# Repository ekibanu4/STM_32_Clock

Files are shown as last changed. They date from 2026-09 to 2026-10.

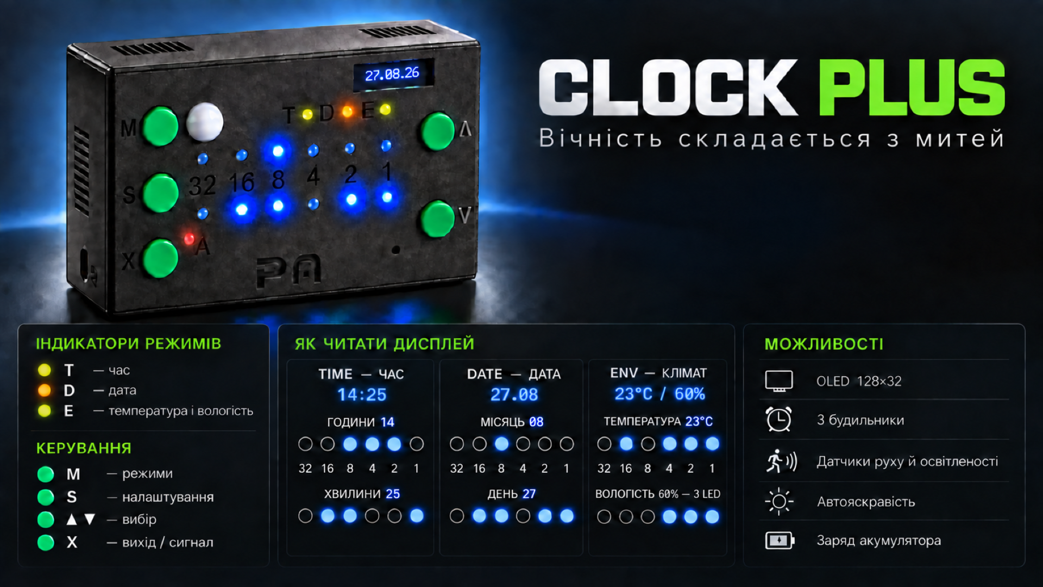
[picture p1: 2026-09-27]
docs/clock-plus-stand-poster-16x9.png

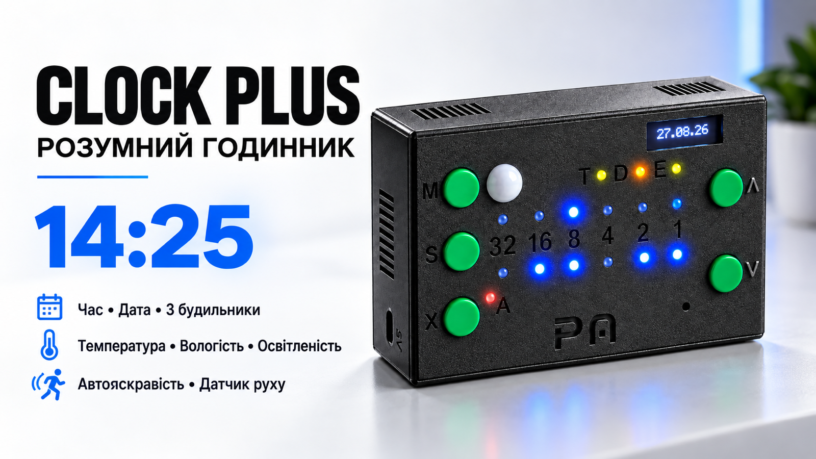
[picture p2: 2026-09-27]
docs/clock-plus-promo-16x9.png

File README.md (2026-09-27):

# STM32 Binary Clock Lab

This repository is a development sandbox for a binary clock built around
different STM32 microcontrollers and peripheral combinations. It contains the
current clock firmware, earlier hardware ports, reusable device drivers, board
experiments, KiCad sources, and end-user documentation.

The project is intentionally broader than a single finished product: it is used
to test display concepts, sensors, RTC implementations, power management, alarm
behavior, and small-memory firmware optimizations on real hardware.

## MCU variants

- **STM32L010F4P6** - current primary target and the most complete low-power build.
- **STM32F030F4P6** - compact CubeMX/HAL port used during early hardware tests.
- **STM32F407G-DISC1** - original prototype and development platform.

The default CMake configuration currently builds the STM32L010F4P6 firmware.
Board-specific notes and wiring are kept under [`Core/Src/boards`](Core/Src/boards).

## Hardware and drivers

The repository includes implementations or experiments for:

- a 16-LED binary display driven by chained 74HC595 shift registers;
- a 128x32 OLED display;
- an internal STM32 RTC clocked from a 32.768 kHz LSE crystal;
- the external DS1302 RTC used by earlier board versions;
- AHT10 and DHT11 temperature/humidity sensors;
- BH1750 and analog LDR light sensing with automatic display brightness;
- an ADC resistor ladder for five control buttons;
- active-buzzer alarm output and three persistent alarm slots;
- PIR motion detection, idle display shutdown, battery measurement, and standby
  power handling.

Separate branches also preserve display and peripheral experiments such as the
MAX721x 8x8 LED matrix version.

## Firmware layout

- `Core/Src/app` - clock behavior, alarms, display rendering, environment data,
  automatic modes, and user-interface state.
- `Core/Src/boards` - MCU/board-specific GPIO and peripheral implementations.
- `Core/Src/drivers` - reusable drivers for buttons, buzzer, DHT11, DS1302,
  light sensing, and shift registers.
- `Drivers` - STM32 CMSIS and HAL sources.
- `docs` - user guide, technical reference, diagrams, and promotional assets.
- `Clocl i2C l0 16 -2 595` - KiCad schematic and PCB sources for the current
  STM32L010-based hardware.

## Build

The current target requires CMake, Ninja, and the GNU Arm Embedded toolchain.

```bash
cmake --preset Release
cmake --build --preset Release
```

Debug and Release presets place their output under `build/`.

## Documentation

- [User manual](docs/clock-plus-user-manual.md)
- [Technical reference](docs/clock-plus-technical-reference.md)
- [STM32L010 board notes](Core/Src/boards/l010f4p6/README.md)
- [STM32F030 board notes](Core/Src/boards/f030f4p6/README.md)
- [STM32F407 board notes](Core/Src/boards/f407_disc1/README.md)

This is an experimental hardware/firmware repository. Verify the selected board
configuration, supply voltage, pin mapping, and programming setup before using
it on assembled hardware.

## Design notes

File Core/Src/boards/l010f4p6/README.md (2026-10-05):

# STM32L010F4P6 Clock Board

This board package contains the STM32L010F4P6 port of the binary clock.
The CubeMX project is `l010f4p6.ioc`.

## MCU Pinout

| MCU pin | Function | Notes |
| --- | --- | --- |
| PA0 | WKUP1 | Main-power wake input, `SYS_WKUP1` in CubeMX |
| PA1 | Buttons ADC | Five-button resistor ladder, `ADC_IN1` |
| PA2 | 74HC595 SER / DS | Shift-register serial data, pin 14 |
| PA3 | 74HC595 RCLK / ST_CP | Shift-register latch clock, pin 12 |
| PA4 | 74HC595 SRCLK / SH_CP | Shift-register shift clock, pin 11 |
| PA5 | 74HC595 OE / TIM2_CH1 | Active-low output enable PWM, pin 13 |
| PA6 | Buzzer drive | Active buzzer transistor control |
| PA7 | Motion sensor input | High means motion detected, low means idle; no internal pull |
| PA9 | I2C SCL | Software I2C clock for OLED, AHT10, and BH1750 |
| PA10 | I2C SDA | Software I2C data for OLED, AHT10, and BH1750 |
| PB1 | Battery sense ADC | BAT+ divider input, `ADC_IN9` |
| PC14 | LSE OSC32_IN | 32.768 kHz crystal |
| PC15 | LSE OSC32_OUT | 32.768 kHz crystal |
| PA13 | SWDIO | Debug/programming |
| PA14 | SWCLK | Debug/programming |

## 74HC595 Display

The current display module uses two chained 74HC595 shift registers:

| MCU pin | Display signal | 74HC595 pin |
| --- | --- | --- |
| PA2 | SER / DS | 14 |
| PA3 | RCLK / ST_CP | 12 |
| PA4 | SRCLK / SH_CP | 11 |
| PA5 | OE / TIM2_CH1 PWM | 13 |

OE is active-low. Firmware controls the display brightness automatically from
the BH1750 light sensor on the shared I2C bus.

### 74HC595 LED Map

The first register carries the six upper value LEDs plus the two high minute
bits. The second register carries the four low minute bits and mode/status
indicators.

| Firmware bit | Normal display meaning |
| --- | --- |
| `board1 bit0..bit5` | upper row value bits `32,16,8,4,2,1` |
| `board1 bit6..bit7` | lower row value bits `32,16` |
| `board2 bit0..bit3` | lower row value bits `8,4,2,1` |
| `board2 bit4` | time mode indicator |
| `board2 bit5` | date mode indicator |
| `board2 bit6` | environment mode indicator |
| `board2 bit7` | alarm indicator |

In time mode the upper row shows hours and the lower row shows minutes. In date
mode the upper row shows month and the lower row shows day. In environment mode
the upper row shows temperature as binary, while humidity is shown as a scale on
the lower row.

## Buttons ADC Ladder

The five buttons are read through one resistor ladder on `PA1 / ADC_IN1`.
The ADC node is pulled up to `3.3V` through `10k`; each button connects the
same `PA1` node to `GND` through its own resistor:

```text
3.3V -- 10k -- PA1 / ADC_IN1
                 |
                 +-- MODE -- 1k   -- GND
                 +-- SET  -- 2k   -- GND
                 +-- UP   -- 4.7k -- GND
                 +-- DOWN -- 10k  -- GND
                 +-- OFF  -- 20k  -- GND
```

With no button pressed, `PA1` stays near `3.3V` and the ADC value is treated as
no button. Pressing a button pulls `PA1` lower; smaller resistor means lower ADC
value.

Current thresholds:

| Button | Max ADC value |
| --- | ---: |
| MODE | 470 |
| SET | 950 |
| UP | 1630 |
| DOWN | 2330 |
| OFF | 3360 |

Values above `3360` are treated as no button.

## User Controls

Manual `MODE` presses cycle through:

```text
time -> date -> environment -> alarm -> battery -> time
```

Automatic display cycling only runs through:

```text
time -> date -> environment -> time
```

Current automatic durations are:

| Auto mode | Duration |
| --- | ---: |
| Time | 15 s |
| Date | 5 s |
| Environment | 5 s |

Button behavior by mode:

| Button | Time | Date | Environment | Alarm | Battery |
| --- | --- | --- | --- | --- | --- |
| MODE | next mode | next mode | next mode | next mode | next mode |
| SET | edit minutes/hours | edit day/month/year | no action | edit alarm hours/minutes | no action |
| UP | increment edited value | increment edited value | no action | when not editing: previous slot; when editing: increment value | no action |
| DOWN | decrement edited value | decrement edited value | no action | when not editing: next slot; when editing: decrement value | no action |
| OFF | exit editing | exit editing | no action | toggle/exit alarm editing | no action |

After user activity, automatic cycling is paused for 30 seconds on the current
screen. If a button is held, the 30-second pause starts after the button is
released. When this pause expires, firmware advances to the next automatic
display mode.

### Time And Date Editing

Setup modes exit automatically after 60 seconds without button activity, the
same as pressing `OFF`.

In time setup, `SET` cycles `minutes -> hours -> minutes`. On the 74HC595
display only the time mode LED blinks; the edited row stays steadily lit.
Editing minutes lights only the lower row, editing hours lights only the upper
row.

In date setup, `SET` cycles `day -> month -> year -> day`. On the 74HC595
display only the date mode LED blinks. Editing day lights only the lower row,
editing month lights only the upper row, and editing year lights `20` on the
upper row plus the editable `00..99` year on the lower row.

## I2C OLED / AHT10 / BH1750 Bus

The experimental I2C branch uses a software I2C bus:

| MCU pin | I2C signal |
| --- | --- |
| PA9 | SCL / SCK |
| PA10 | SDA |

The 0.91" 128x32 OLED is probed at `0x3C`, then `0x3D`. The AHT10
temperature/humidity sensor uses address `0x38`. The BH1750 light sensor uses
address `0x23`. All devices share the same two lines. Both lines are configured
as open-drain GPIO with pull-ups enabled in firmware; external pull-ups are
still recommended for a stable bus.

Before initializing AHT10, firmware recovers the bus with nine SCL pulses and
STOP, waits 40 ms, sends soft reset `0xBA`, and waits 20 ms. It then initializes
the sensor with `0xE1 0x08 0x00` and waits another 40 ms. A measurement starts
with `0xAC 0x33 0x00`; its 80 ms wait starts after the command finishes, so
initialization cannot shorten conversion time. Firmware reads 6 bytes and
converts the 20-bit humidity and temperature values. A busy response keeps the
measurement pending for another scheduler attempt, up to 200 ms from the
trigger; timeout marks the reading invalid and resets initialization state.
Successful measurements are throttled to no faster than once every 15 seconds.

In environment display mode, the top/six-hour LEDs show temperature as a binary
number. The lower humidity LEDs are a scale, not a binary value:

| Humidity | Lit humidity LEDs |
| --- | ---: |
| `< 30%` | 0 |
| `40%` | 1 |
| `50%` | 2 |
| `60%` | 3 |
| `70%` | 4 |
| `80%` | 5 |
| `>= 90%` | 6 |

For example, top `011011` means `27 C`; three lit humidity LEDs means about
`60% RH`.

## BH1750 Light Sensor

The light sensor is now a BH1750 on the shared software I2C bus. Firmware puts
it into continuous high-resolution mode and reads lux about once every 5 seconds,
then maps that value to 10 brightness levels with hysteresis. Brightness is
applied through `PA5 / TIM2_CH1` to the 74HC595 OE pin.

Current brightness calibration:

| Setting | Value |
| --- | ---: |
| Lux dark | 2 |
| Lux bright | 400 |
| Brightness min | 2% |
| Brightness max | 50% |
| Brightness levels | 10 |
| Lux hysteresis | 5 |

## OLED Display

The OLED mirrors the selected mode with text output:

| Mode | OLED content |
| --- | --- |
| Time | `HH:MM:SS`; a small `A` in the lower-right corner means at least one alarm is enabled |
| Date | `DD.MM.YY` |
| Environment | temperature and humidity from AHT10 |
| Alarm list | three rows, `*` marks the selected slot, `-` marks non-selected slots |
| Alarm edit | only the selected slot is shown large, with `..` over hours or minutes |
| Battery | `BAT xx.x%` plus a bottom charge bar |

Time/date setup on OLED uses two dots above the edited field. Alarm setup uses
two dots above the edited hour or minute field. When an alarm is ringing, OLED is
written once with `ALARM n` and normal redraw is skipped until the alarm stops.

## Active Buzzer

`PA6` drives the active buzzer circuit through a transistor. The firmware drives
`PA6` high while the buzzer should sound and low when it should be silent.

## Motion Sensor Idle Display

`PA7` is used as a digital motion sensor input. The sensor output should be
`0..3.3V`; high means motion is present. After one complete automatic display
cycle without motion, button activity, active setup, or an active alarm, firmware
clears the displays and turns the buzzer off. The firmware waits for the
actual automatic transitions `time -> date -> environment -> time`, so each
automatic screen is shown before idle display shutdown. With the current
`15s/5s/5s` auto-mode timing this is about 25 seconds. It does not enter standby
in this idle-display state.

The idle cycle is reset by:

- high level on `PA7`;
- any button press;
- active time/date/alarm editing;
- currently ringing alarm.

Between application updates the CPU enters ordinary Sleep (`WFI`, not STOP).
The active update interval remains 20 ms. In idle-display state it increases to
100 ms, and the core clock is reduced from MSI range 6 (`4.194304 MHz`) to MSI
range 5 (`2.097152 MHz`) while the displays are off.
When motion, a button press, or an alarm requires the UI again, firmware returns
the MSI clock to `4.194304 MHz`, restores the 20 ms interval, shows time mode,
and resumes the normal display cycle. Low-battery handling also uses 20 ms so
the existing buzzer pattern keeps its timing.

LPTIM1 is reserved for a one-shot wake interrupt, clocked from the RTC's
32.768 kHz LSE crystal. Sleep lasts only for the remaining part of the update
interval; if processing already consumed the interval, the next update runs
immediately. SysTick runs at 1 ms while code executes, but its counter and IRQ
are stopped during Sleep. On wake, the elapsed LPTIM1 count advances the HAL
millisecond counter, with fractional milliseconds retained across sleeps and
MSI changes. A pending SysTick is accounted for before sleeping. Interrupts
are masked across WFI: an enabled pending timer IRQ prevents sleep or wakes
the core even with its handler masked (PM0223, wakeup from WFI). This also
handles an IRQ that is already pending before WFI, without depending on the
WFE event latch or SEVONPEND. LPTIM1 is reset after reading its
elapsed count, avoiding flag clearing outside its ISR (ES0483). SysTick keeps
counting while the ARR write synchronizes to LSE. If LSE is not ready, the
firmware falls back to Sleep with the normal 1 ms SysTick wake source; timer
configuration also has a bounded synchronization wait.

PA7 and the ADC button ladder are still polled, without EXTI. Idle detection
latency is approximately up to 100 ms plus processing time, and button presses
shorter than the polling interval can be missed. RTC calendar updates remain
at 1 s. This path does not turn off ADC, TIM2 PWM, or sensor power.

When main power is missing, the normal standby path runs first and the motion
sensor is ignored so it cannot block power-loss handling.

## Alarms

The firmware supports three alarm slots. Alarm settings are stored in RTC backup
registers, so configured slots survive main-power loss while the RTC domain is
kept alive by the supercapacitor.

Alarm mode behavior:

- `MODE` selects the alarm screen.
- entering alarm mode selects slot `A1`.
- `DOWN` selects the next slot: `A1 -> A2 -> A3 -> A1`.
- `UP` selects the previous slot: `A1 -> A3 -> A2 -> A1`.
- `SET` enters alarm hour/minute editing.
- `UP` / `DOWN` while editing increment/decrement the edited alarm value.
- `OFF` while editing exits to alarm-slot selection.
- `OFF` while not editing toggles the selected configured slot on/off.
- `OFF` on an empty slot blinks all hour/minute LEDs as an error.
- long `OFF` toggles all configured alarms: if any alarm is on it disables all;
  if all are off it enables all configured slots.

74HC595 alarm-mode display:

| LED group | Meaning |
| --- | --- |
| upper/lower value rows | selected alarm time |
| alarm LED, `board2 bit7` | alarm mode indicator; also lit in other modes if any alarm is enabled |
| status LED, `board2 bit4` | lit when selected slot is enabled |
| slot number LEDs, `board2 bit6/bit5` visually | selected slot as binary `01`, `10`, `11` |

While editing an alarm, the alarm LED stays steadily lit, the selected slot
number LEDs blink, and only the edited value row is lit: upper row for hours,
lower row for minutes.

OLED alarm-list display uses:

```text
*A1 17:20 ON
-A2 12:20 OFF
-A3 --:-- OFF
```

An empty slot is shown as `--:--`.

When an alarm is saved or re-enabled, firmware clears the "already triggered for
this minute" guard. This means a slot can ring again after being reconfigured,
even if that same slot already fired earlier today.

## RTC / LSE

Time is read from the internal RTC clocked by an external 32.768 kHz crystal on
`PC14/PC15`. Firmware refreshes the cached RTC value once per second.

Date setup cycles through day, month, and year. The year is stored in the STM32
RTC as `00..99` with an implied `20xx` century. While editing the year, the
hour LEDs show the fixed `20` prefix and the minute LEDs show the editable
`00..99` year value; only the date mode indicator blinks. Leap-year day limits
are calculated for the `2000..2099` range.

RTC init keeps the LSE path conservative:

- if `LSERDY` is already set after standby wake, firmware does not re-run
  `HAL_RCC_OscConfig()` for LSE;
- if LSE/RTC init returns an error, firmware returns from RTC init instead of
  staying forever in `Error_Handler()`.

## Wake Power, Battery Sense, And Standby

`PA0 / WKUP1` is the hard power-loss and wake signal. If `PA0` is low, the
firmware powers external devices down, prepares `WKUP1`, and enters standby.

Battery level is measured separately on `PB1 / ADC_IN9`. The firmware converts
the ADC reading through `VREFINT`, then scales it through the measured battery
divider calibration. `PA0` and `PB1` intentionally have separate jobs:

- `PA0 / WKUP1` decides hard standby and wake after real power loss;
- `PB1 / ADC_IN9` decides low-battery display shutdown and battery percentage.

Divider scaling follows the fitted 470 kOhm upper and 1 MOhm lower resistors:

```text
BAT+ -- 470 kOhm -- PB1 / ADC_IN9 -- 1 MOhm -- GND
battery_mV = sense_mV * 1470 / 1000
```

At 3390 mV on BAT+, an unloaded PB1 should be about 2306 mV. The previous
3650/2140 scaling overestimated battery voltage by about 16%. A voltage meter
loads this high-impedance divider: a 1 MOhm input in parallel with the lower
resistor reduces PB1 to about 1747 mV and can trigger low-battery mode. Compare
firmware voltage against BAT+ with the PB1 probe removed; use the raw ADC and
VREFINT readings to inspect PB1 without changing the divider load.
On the tested board at 4200 mV input, ADC diagnostics measured 2184 mV with the
meter connected and 2870 mV after removing the PB1 probe.
After correcting the scaling, firmware read 4215 mV at the supply's 4200 mV
setting. At a multimeter-measured 3380 mV on BAT+, it read about 3338 mV; the
remaining error is about 42 mV (1.2%), so this is nominal divider scaling rather
than a precision calibration of the full measurement path.

Current low-battery thresholds:

```text
MAIN_POWER_BATTERY_MV_MIN = 2900 mV battery voltage
MAIN_POWER_BATTERY_MV_RECOVER = 3100 mV battery voltage
```

Battery voltage is measured once every 500 ms and cached for both the
low-battery check and the percentage display. ADC sampling time is 160.5 clock
cycles for button, battery, and VREFINT channels; the first conversion after
selecting a channel is discarded as before.

When the scaled battery voltage is below `2900 mV` for three consecutive fresh measurements
while `PA0` is still high, firmware enters low-battery mode instead of standby:
external devices are powered down and only the alarm LED blinks periodically.
Normal display operation resumes only after three consecutive fresh measurements
at or above `3100 mV`. Repeated cache reads do not count as confirmation; a
persistent threshold crossing takes approximately 1–1.5 s to confirm.

Before standby the firmware powers external devices down, then waits up to
`25 s` for `PA0 / WKUP1` to be low and debounces that low level for `300 ms`.

The battery display percentage uses a lookup curve from the same calibrated
battery voltage:

```text
2900 mV = 0%
3100 mV = 10%
3200 mV = 22%
3300 mV = 36%
3400 mV = 50%
3500 mV = 62%
3600 mV = 73%
3700 mV = 82%
3800 mV = 90%
4100 mV = 100%
```

Values between points are interpolated. The displayed percentage is filtered and
updated with hysteresis so it does not jump on every ADC sample.

The manual battery mode is reached through:

```text
time -> date -> environment -> alarm -> battery -> time
```

In battery mode the 74HC595 display uses only the six minute LEDs as a charge
bar. The OLED shows `BAT xx.x%` plus a bottom charge bar.

Expected power-loss flow:

```text
main power present  -> PA0 high, firmware runs
main power removed  -> PA0 low, VDD MCU held by supercapacitor
firmware enters standby
main power returns  -> PA0 rising edge wakes the MCU
```

`PA0` is not used as ADC or normal GPIO output. CubeMX assigns it as
`SYS_WKUP1`; firmware only enables the PWR wake source before entering standby.

## Size-Oriented Firmware Notes

The l010 build avoids several HAL driver paths to keep the firmware inside the
16 KB flash limit:

- ADC reads for the button ladder, battery sense, and `VREFINT` use direct ADC1
  registers instead of `HAL_ADC_Init`, `HAL_ADC_ConfigChannel`, and
  `HAL_ADC_PollForConversion`;
- `stm32l0xx_hal_adc.c`, `stm32l0xx_hal_adc_ex.c`, `stm32l0xx_hal_i2c.c`,
  `stm32l0xx_hal_i2c_ex.c`, and `stm32l0xx_hal_dma.c` are not linked by the
  CMake build;
- system clock setup and `HAL_InitTick` are kept small and register-based;
- the OLED/AHT10/BH1750 bus remains software I2C on GPIO, so no hardware I2C
  handle or HAL I2C transfer code is used.

The main loop uses ordinary Sleep between updates (20 ms active, 100 ms idle)
with LPTIM1 wakeup and HAL time compensation. This preserves peripheral state
and avoids 1 ms SysTick wakeups while asleep. STOP is not used; PA7 motion,
button input, low-battery handling, and software alarm checks run on each update.

## Flashing Notes

OpenOCD may fail to halt the target when the chip is in a low-power state. In
that case, use STM32CubeProgrammer CLI with connect-under-reset, for example:

```text
STM32_Programmer_CLI -c port=SWD mode=UR freq=50 -w build/Debug/l010f4p6.elf -v -rst
```

The VS Code tasks still include OpenOCD flash tasks for normal cases.

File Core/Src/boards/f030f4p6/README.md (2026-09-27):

# STM32F030F4P6 Binary Clock Board

This board package documents the STM32F030F4P6 wiring used by the CubeMX/HAL
port of the binary clock.

## MCU Pinout

| MCU pin | Function | Notes |
| --- | --- | --- |
| PA0 | LDR ADC input | Light sensor / automatic brightness, ADC_IN0 |
| PA1 | Buttons ADC input | Five-button resistor ladder, ADC_IN1 |
| PA2 | 74HC595 SER / DS | Shift-register serial data, pin 14 |
| PA3 | 74HC595 RCLK / ST_CP | Shift-register latch clock, pin 12 |
| PA5 | 74HC595 SRCLK / SH_CP | Shift-register shift clock, pin 11 |
| PA6 | 74HC595 OE | TIM3_CH1 PWM, active-low output enable, pin 13 |
| PA7 | DS1302 CLK | RTC clock |
| PA9 | DS1302 DATA / I/O | Bidirectional RTC data |
| PA10 | DS1302 RST / CE | RTC chip enable |
| PB1 | Buzzer control | Active buzzer transistor drive |
| PF1 | DHT11 DATA | Single-wire temperature/humidity data |
| PA13 | SWDIO | Debug/programming |
| PA14 | SWCLK | Debug/programming |

## 74HC595N Chain

Two 74HC595N shift registers are chained for 16 LED outputs.

STM32F030F4P6 to first 74HC595N:

| STM32 pin | 74HC595N pin | Function |
| --- | --- | --- |
| PA2 | pin 14 | SER / DS, serial data |
| PA3 | pin 12 | RCLK / ST_CP, latch clock |
| PA5 | pin 11 | SRCLK / SH_CP, shift clock |
| PA6 | pin 13 | OE, output enable PWM |

The first byte shifted out travels through the first 74HC595 `QH'` output and
ends up in the second chip. The second byte shifted out remains in the first
chip connected directly to MCU DATA.

### LED Mapping

First 74HC595, connected directly to MCU DATA:

| Output | Display |
| --- | --- |
| QA | hours 32 |
| QB | hours 16 |
| QC | hours 8 |
| QD | hours 4 |
| QE | hours 2 |
| QF | hours 1 |
| QG | minutes 32 |
| QH | minutes 16 |

Second 74HC595, chained from first chip `QH'`:

| Output | Display |
| --- | --- |
| QA | minutes 8 |
| QB | minutes 4 |
| QC | minutes 2 |
| QD | minutes 1 |
| QE | mode time / alarm slot 1 |
| QF | mode date / alarm slot 2 |
| QG | mode environment / alarm slot 3 |
| QH | alarm status |

## Buttons ADC Ladder

The five buttons are read through one resistor ladder on `PA1 / ADC_IN1`.

Current measured ADC ranges are decoded with these thresholds:

| Button | Max ADC value |
| --- | ---: |
| MODE | 470 |
| SET | 950 |
| UP | 1630 |
| DOWN | 2330 |
| OFF | 3360 |

Values above `3360` are treated as no button.

## Light Sensor

The LDR divider is connected to `PA0 / ADC_IN0`.

Current calibration:

| Constant | Value |
| --- | ---: |
| ADC dark | 1000 |
| ADC bright | 3200 |
| Brightness min | 5% |
| Brightness max | 70% |
| Brightness levels | 6 |
| ADC hysteresis | 80 |

Brightness is applied through `PA6 / TIM3_CH1` to the 74HC595 OE pin. OE is
active-low.

## DS1302 RTC

| STM32 pin | DS1302 pin |
| --- | --- |
| PA7 | CLK |
| PA9 | DATA / I/O |
| PA10 | RST / CE |

The DS1302 stores the current time/date and the three alarm slots in
battery-backed RAM.

Alarm RAM format:

```text
byte 0  -> signature
byte 1  -> version
byte 2  -> alarm slot 1 flags
byte 3  -> alarm slot 1 hour
byte 4  -> alarm slot 1 minute
byte 5  -> alarm slot 2 flags
byte 6  -> alarm slot 2 hour
byte 7  -> alarm slot 2 minute
byte 8  -> alarm slot 3 flags
byte 9  -> alarm slot 3 hour
byte 10 -> alarm slot 3 minute
byte 11 -> checksum
```

Alarm flags:

```text
bit 0 -> configured
bit 1 -> enabled
```

## DHT11

The DHT11 data line is connected to `PF1`.

The firmware switches PF1 between open-drain output for the start pulse and
input for the DHT11 response and 40-bit data transfer. The DHT11 transaction is
guarded so a full read is not started more often than once every 2 seconds.

## Buzzer

`PB1` drives the active buzzer circuit. The alarm pattern is generated by the
application layer:

```text
beep beep beep ... pause ... beep beep beep ... pause
```

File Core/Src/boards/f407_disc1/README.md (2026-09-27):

# STM32F407G-DISC1 Board Package

This board package contains the current prototype wiring for the binary clock on
STM32F407G-DISC1.

## MCU Pinout

| MCU pin | Function | Notes |
| --- | --- | --- |
| PA0 | Light sensor ADC | LDR divider input |
| PA1 | Buttons ADC | Five-button resistor ladder |
| PA2 | 74HC595 SER / DS | Shift-register serial data, pin 14 |
| PA3 | 74HC595 RCLK / ST_CP | Shift-register latch, pin 12 |
| PA4 | 74HC595 SRCLK / SH_CP | Shift-register clock, pin 11 |
| PA5 | DS1302 CLK | RTC clock |
| PA6 | 74HC595 OE / TIM3_CH1 | Output-enable PWM dimming, pin 13 |
| PA7 | DS1302 DATA / I/O | RTC bidirectional data |
| PA8 | DS1302 RST / CE | RTC chip enable |
| PA10 | DHT11 DATA / S | HW-481 DHT11 module data |
| PA15 | Buzzer drive | NPN base through 1k..4.7k |

PA13 and PA14 are kept free for SWD debugging.

## Buttons ADC Ladder

```text
3.3V
 |
[10k]
 |
 +-------> PA1 / ADC_BUTTONS
 |
 +--[ MODE]--[1k]--GND
 |
 +--[ SET ]--[2k]--GND
 |
 +--[ UP  ]--[4.7k]--GND
 |
 +--[ DOWN]--[10k]--GND
 |
 +--[ OFF ]--[20k]--GND
```

ADC thresholds live in `board_config.h`.

## Light Sensor

```text
3.3V
 |
[LDR]
 |
 +-------> PA0 / ADC_LIGHT
 |
[10k]
 |
GND
```

The light sensor controls display brightness from 5% to 70%. The 74HC595 outputs
are dimmed together through the OE pin.

## 74HC595 Chain

First 74HC595N wiring:

| 74HC595 pin | Signal | MCU / rail |
| --- | --- | --- |
| 14 DS / SER | Serial data | PA2 |
| 11 SH_CP / SRCLK | Shift clock | PA4 |
| 12 ST_CP / RCLK | Latch clock | PA3 |
| 13 OE | Output enable PWM | PA6 |
| 10 MR / SRCLR | Master reset | 3.3V |
| 16 VCC | Power | 3.3V |
| 8 GND | Ground | GND |

Second 74HC595N is chained from the first register QH' to the second register DS.

### Display Mapping

Board 1 outputs:

| Output | Display |
| --- | --- |
| QA | hours 32 |
| QB | hours 16 |
| QC | hours 8 |
| QD | hours 4 |
| QE | hours 2 |
| QF | hours 1 |
| QG | minutes 32 |
| QH | minutes 16 |

Board 2 outputs:

| Output | Display |
| --- | --- |
| QA | minutes 8 |
| QB | minutes 4 |
| QC | minutes 2 |
| QD | minutes 1 |
| QE | mode time |
| QF | mode date |
| QG | mode environment |
| QH | alarm set |

## DS1302Z RTC

| DS1302 pin | MCU / rail |
| --- | --- |
| CLK | PA5 |
| DATA / I/O | PA7 |
| RST / CE | PA8 |
| VCC | 3.3V |
| GND | GND |

The module has quartz and backup battery assembled. DS1302 RAM stores alarm
slots.

## HW-481 / DHT11

| Module pin | MCU / rail |
| --- | --- |
| DATA / S | PA10 |
| VCC / + | 5V on the current prototype |
| GND / - | GND |

The DHT11 module was unreliable at the lower prototype voltage, so the current
test wiring uses 5V module power while the data line goes to PA10.

## Active Buzzer

Current prototype buzzer: TMB12A05 active buzzer.

```text
PA15 -> NPN base through 1k..4.7k
3.3V -> 270R -> buzzer +
buzzer - -> NPN collector
NPN emitter -> GND
```

The 270R resistor was chosen experimentally to reduce volume.

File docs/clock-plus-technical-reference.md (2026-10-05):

# Clock Plus на STM32L010F4P6

## Технічна документація апаратної частини та firmware

**Статус документа:** первинна технічна редакція
**Дата звірки:** 2026-09-27
**Гілка:** `optimizations`
**Звірений коміт:** `ea0914f` (`Optimize l010 firmware size and idle mode`)
**Цільова плата:** STM32L010F4P6, TSSOP-20
**Проєкт CubeMX:** `l010f4p6.ioc`

Цей документ описує поточну реалізацію Clock Plus: електричну схему,
розведення контактів, периферію, формати даних, алгоритми firmware, режими
живлення, збірку, прошивання та відомі розбіжності між кодом і KiCad.

> Важливо: джерелом істини для поведінки пристрою є поточний код. KiCad-схема
> містить щонайменше одну критичну розбіжність із firmware у підключенні
> 74HC595. Перед виготовленням наступної ревізії плати її треба усунути.

## 1. Джерела даних

Документ складено за такими файлами:

- `Core/Src/main.c` - запуск, системна частота, RTC, головний цикл і стани
  живлення;
- `Core/Src/board.h` - апаратний API та формат 16-бітного LED-дисплея;
- `Core/Src/boards/l010f4p6/board.c` - GPIO, ADC, 74HC595, програмний I2C,
  AHT10, BH1750, батарея, buzzer і STANDBY;
- `Core/Src/boards/l010f4p6/board_config.h` - апаратні контакти, пороги й
  калібрування;
- `Core/Src/boards/l010f4p6/oled_128x32.c` - драйвер OLED 128x32;
- `Core/Src/app/*` - UI, автоматична зміна режимів, відображення, датчики й
  будильники;
- `Core/Src/boards/l010f4p6/README.md` - опис плати й інструкції збірки;
- `l010f4p6.ioc` - конфігурація STM32CubeMX;
- `STM32L010XX_FLASH.ld` - карта Flash/RAM;
- `CMakeLists.txt`, `CMakePresets.json`, `.vscode/*` та `openocd.cfg` - збірка,
  debug і прошивання;
- `docs/Clock i2c l0.pdf` - принципова схема KiCad;
- `docs/Clock i2c l0 pcb.pdf` - дев'ятисторінковий комплект шарів PCB;
- `docs/Clocl i2C l0 16 -2 595/Clock i2c l0.kicad_sch` - вихідна схема;
- `docs/Clocl i2C l0 16 -2 595/Clock i2c l0.kicad_pcb` - вихідна PCB.

## 2. Призначення та склад системи

Clock Plus - автономний бінарний годинник із двома засобами індикації:

- 16 світлодіодів через два послідовно з'єднані 74HC595;
- OLED 0.91 дюйма, 128x32, I2C, сумісний із SSD1306.

Функціональні вузли:

- RTC мікроконтролера від зовнішнього LSE 32.768 kHz;
- три незалежні щоденні будильники;
- активний buzzer через NPN-транзистор;
- AHT10 для температури й вологості;
- BH1750 для освітленості та автоматичної яскравості;
- PIR AM312/HC-SR312 для контролю присутності;
- п'ять кнопок через один ADC-резистивний ladder;
- контроль напруги 18650 через ADC;
- Sleep між обробками та повний STANDBY при зникненні основного
  живлення;
- SWD для програмування та налагодження.

## 3. Мікроконтролер і ресурси

| Параметр | Значення |
| --- | --- |
| MCU | STM32L010F4P6 |
| Ядро | Arm Cortex-M0+ |
| Корпус | TSSOP-20 |
| Flash | 16 KiB, адреса `0x08000000` |
| SRAM | 2 KiB, адреса `0x20000000` |
| Активна частота | MSI range 6, 4.194304 MHz |
| Частота очікування | MSI range 5, 2.097152 MHz |
| RTC clock | LSE 32.768 kHz |
| Системний tick | SysTick, 1 ms під час виконання; компенсація часу Sleep через LPTIM1/LSE |
| Період головного циклу | 20 ms активний, 100 ms із погашеними екранами |
| Мова | C11 із GNU extensions |
| HAL/CMSIS | STM32CubeL0 FW 1.12.4 |

### 3.1 Поточне використання пам'яті

Перевірено збірками Debug і Release 2026-09-27. Через однакову оптимізацію
`-Os` і LTO їхній виконуваний образ має однаковий розмір.

| Область | Використано | Доступно | Частка |
| --- | ---: | ---: | ---: |
| Flash | 14,100 B | 16,384 B | 86.06% |
| RAM разом із резервом heap/stack | 1,776 B | 2,048 B | 86.72% |
| `.text` | 13,592 B | - | - |
| `.rodata` | 256 B | - | - |
| `.data` | 52 B | - | - |
| `.bss` | 188 B | - | - |
| `_user_heap_stack` | 1,536 B | - | - |

Налаштування linker script:

- мінімальний heap: `0x200` = 512 B;
- мінімальний stack: `0x400` = 1024 B;
- запас Flash до межі регіону: 2,284 B;
- запас RAM з урахуванням зарезервованих heap/stack: 272 B.

У firmware не використовується динамічна пам'ять, тому резерв heap можна
переглянути окремою оптимізацією після перевірки всіх бібліотечних залежностей.

## 4. Архітектура вихідного коду

```text
Core/Src/main.c
  запуск MCU, clock, ADC base, RTC, main loop, power-state orchestration

Core/Src/board.h
  апаратно-незалежні типи та API плати

Core/Src/boards/l010f4p6/
  board.c              GPIO, ADC, PWM, I2C, датчики, battery, standby
  board_config.h       контакти, пороги, калібрування
  oled_128x32.c/.h     OLED SSD1306-compatible

Core/Src/app/
  alarm/               три alarm slots, trigger, buzzer, RTC backup storage
  display/             формування 16-бітної LED-маски
  environment/         планувальник читання AHT10
  ui/                  кнопки, edit states, auto modes
  core/                спільні типи та константи
```

Апаратна залежність зосереджена в `board.c`. Застосунок працює через функції
`Board_*`, але OLED поки що викликається напряму з `main.c`.

## 5. Карта контактів MCU

### 5.1 Карта, яку використовує поточний firmware

| Контакт MCU | Напрямок/периферія | Функція | Електричні примітки |
| --- | --- | --- | --- |
| PA0 | digital input / WKUP1 | наявність основного живлення, wake зі STANDBY | високий = живлення є; низький = підготовка до STANDBY |
| PA1 | ADC_IN1 | п'ять кнопок через resistor ladder | analog, без внутрішньої підтяжки |
| PA2 | GPIO output | 74HC595 SER/DS | serial data, pin 14 регістра |
| PA3 | GPIO output | 74HC595 RCLK/ST_CP | latch, pin 12 |
| PA4 | GPIO output | 74HC595 SRCLK/SH_CP | shift clock, pin 11 |
| PA5 | TIM2_CH1 AF5 | 74HC595 OE | active-low PWM, pin 13 |
| PA6 | GPIO output | активний buzzer через NPN | high = звук увімкнено |
| PA7 | digital input | PIR motion | high = рух; внутрішньої підтяжки немає |
| PA9 | GPIO open-drain | software I2C SCL | OLED, AHT10, BH1750 |
| PA10 | GPIO open-drain | software I2C SDA | OLED, AHT10, BH1750 |
| PA13 | SWDIO | програмування/debug | роз'єм SWD |
| PA14 | SWCLK | програмування/debug | роз'єм SWD |
| PB1 | ADC_IN9 | BAT+ sense | через резистивний дільник |
| PC14 | OSC32_IN | LSE input | кварц 32.768 kHz |
| PC15 | OSC32_OUT | LSE output | кварц 32.768 kHz |
| NRST | reset input | hardware reset/connect-under-reset | зовнішня підтяжка до VDD MCU |
| PB9/BOOT0 | boot selection | штатно притиснутий до GND | очікується normal boot from Flash |

### 5.2 CubeMX проти runtime-конфігурації

У `l010f4p6.ioc` описані PA0, PA1, PA2-PA5, PB1, PC14/PC15 та SWD. Контакти
PA6, PA7, PA9 і PA10 ініціалізуються вручну в board layer і не повністю
представлені в CubeMX. Після повторної генерації CubeMX необхідно перевіряти:

- збереження всіх блоків `USER CODE`;
- `Board_Init()` для PA6, PA7 і програмного I2C;
- CMake source list;
- ручну ініціалізацію ADC, системної частоти та SysTick.

### 5.3 Критична розбіжність KiCad і firmware

Поточна схема `Clock i2c l0.kicad_sch` підписує сигнали так:

| Контакт | KiCad-схема | Поточний firmware |
| --- | --- | --- |
| PA2 | RCLK/ST_CP | SER/DS |
| PA3 | OE | RCLK/ST_CP |
| PA4 | SER/DS | SRCLK/SH_CP |
| PA5 | SRCLK | OE/TIM2_CH1 |

Це не косметична різниця: PA5 потрібен firmware як TIM2_CH1 для PWM. Перед
замовленням PCB треба або перерозвести KiCad під firmware, або синхронно змінити
`board_config.h`, GPIO і TIM2. Поточна перевірена програмна карта наведена в
розділі 5.1.

## 6. Апаратна схема

### 6.1 PCB

Параметри поточного KiCad PCB:

| Параметр | Значення |
| --- | --- |
| Габарит | 120 x 80 mm |
| Шари міді | 2: F.Cu, B.Cu |
| Матеріал | FR4 |
| Товщина плати | 1.6 mm |
| Мідь | 35 um на кожному боці |
| Кількість footprints | 77 |
| Монтажні отвори | 4 x 3.3 mm |
| Координати отворів від origin KiCad | (22.65, 22.65), (22.65, 97.45), (137.35, 22.65), (137.35, 97.35) mm |

У `docs/Clock i2c l0 pcb.pdf` наведено дев'ять сторінок виробничого перегляду
шарів. Джерело PCB має кілька історичних snapshot-файлів `before-*`; актуальним
вважається файл без суфікса.

### 6.2 Основні компоненти зі схеми

| Позначення | Компонент/номінал | Призначення |
| --- | --- | --- |
| U1 | STM32L010F4Px | MCU |
| U2, U3 | 74HC595, SOIC-16 | 16 LED outputs |
| Y1 | 32.768 kHz crystal | LSE для RTC |
| C7, C8 | 15 pF | load capacitors LSE |
| C1, C2 | 100 nF | локальне decoupling VDD/VDDA |
| C4 | 10 uF | bulk decoupling VDD MCU |
| C3 | polarized, номінал у схемі не заданий | резервне живлення/накопичення |
| R2 | 10 kOhm | NRST pull-up |
| R3 | 220 kOhm | PA0/WKUP pull-down у схемі |
| R5 | 470 kOhm | верхнє плече BAT+ sense |
| R8 | 1 MOhm | нижнє плече BAT+ sense |
| R6, R9 | 4.7 kOhm | pull-up SCL/SDA до VCC peripheral |
| R7 | 10 kOhm | PB9/BOOT0 pull-down до GND |
| R27 | 10 kOhm | pull-up button ladder до VCC peripheral |
| R28-R32 | 1 k, 2 k, 4.7 k, 10 k, 20 kOhm | MODE, SET, UP, DOWN, OFF |
| R10 | 2 kOhm | base resistor buzzer transistor |
| Q1 | 2N2222 | low-side key активного buzzer |
| R11-R26 | 200 Ohm | струмообмеження 16 LED |
| BT1 | 18650 | акумулятор |
| J3 | BMS, 4 pin | BMS connection |
| J4 | buck-boost, 4 pin | перетворювач до 3.3 V |
| J2 | SWD, 5 pin | SWCLK, SWDIO, GND, VDD MCU, NRST |
| J5 | OLED, 4 pin | SDA, SCL/SCK, VCC peripheral, GND |
| J6 | GY-302/BH1750, 4 pin | VCC, GND, SCL, SDA |
| J7 | AHT10, 4 pin | VCC, GND, SCL, SDA |
| J1 | AM312/HC-SR312, 3 pin | PIR output, VCC, GND |
| BZ1 | active buzzer | звуковий сигнал |

На схемі D1-D4 та R1 мають загальні позначення без конкретного part number або
номіналу. Їх треба конкретизувати в BOM перед виробництвом.

### 6.3 Живлення

Схема розділяє щонайменше такі мережі:

- `+3.3V` - основний вихід buck-boost;
- `VCC периферія` - OLED, сенсори, 74HC595, LED, PIR і buzzer;
- `VDD MCU` - VDD та VDDA мікроконтролера;
- `Bms+`, `Bms-` - акумуляторна сторона BMS;
- `GND`.

Між основним живленням, периферією та MCU використано діоди D1-D4, резистор R1
і полярний накопичувальний конденсатор C3. Ідея вузла - не допустити живлення
вимкненої периферії через GPIO/I2C і дати RTC/MCU час коректно перейти в
STANDBY.

Firmware додатково переводить зовнішні лінії в analog/no-pull перед STANDBY,
щоб зменшити leakage і back-powering. Діодна розв'язка не скасовує вимоги, що
сигнал на вході MCU не повинен перевищувати VDD MCU більш ніж допускає
datasheet.

### 6.4 Decoupling і LSE

- C1 і C2: 100 nF біля VDD та VDDA;
- C4: 10 uF на `VDD MCU`;
- LSE: Y1 32.768 kHz між PC14 і PC15;
- C7 і C8: по 15 pF від кожного виводу кварцу до GND;
- доріжки LSE повинні бути короткими, симетричними й віддаленими від LED/PWM;
- точне значення load capacitors слід перевірити за `CL` конкретного кварцу та
  паразитною ємністю PCB. 15 pF - значення поточної схеми, а не універсальне
  правило.

## 7. RTC і календар

RTC тактується від зовнішнього LSE:

| Налаштування | Значення |
| --- | --- |
| LSE | 32.768 kHz |
| Drive | `RCC_LSEDRIVE_HIGH` |
| Формат часу | 24 години |
| Async prescaler | 127 |
| Sync prescaler | 255 |
| RTC output | disabled |

Під час запуску `App_RTC_Init()`:

1. відкриває доступ до backup domain;
2. скидає backup domain, якщо RTC clock source не LSE;
3. запускає LSE через `HAL_RCC_OscConfig()`;
4. перевіряє `LSERDY`;
5. вибирає LSE для RTC та вмикає RTC;
6. викликає `HAL_RTC_Init()`.

Якщо запуск LSE або RTC не вдався, функція повертає 0, але `main()` зараз
ігнорує результат і продовжує запуск. Окремої індикації LSE failure немає.

Поточний час читається раз на 1000 ms. За вимогою STM32 HAL після
`HAL_RTC_GetTime()` одразу викликається `HAL_RTC_GetDate()` для коректного
розблокування shadow registers.

Рік зберігається як `00..99` та інтерпретується UI як 2000-2099. Високосний
рік визначається через `year % 4 == 0`, що коректно для цього діапазону.
`Board_WriteDate()` записує weekday як Monday; weekday у UI не використовується
і не обчислюється з дати.

## 8. 16-LED дисплей і 74HC595

Використано два каскадно з'єднані 74HC595. Firmware передає спочатку `board2`
від MSB до LSB, потім `board1` від MSB до LSB, після чого формує імпульс latch.

### 8.1 Формат `ClockDisplay_t`

| Байт/біт | Значення у звичайних режимах |
| --- | --- |
| `board1 bit0` | верхній ряд, вага 32 |
| `board1 bit1` | верхній ряд, вага 16 |
| `board1 bit2` | верхній ряд, вага 8 |
| `board1 bit3` | верхній ряд, вага 4 |
| `board1 bit4` | верхній ряд, вага 2 |
| `board1 bit5` | верхній ряд, вага 1 |
| `board1 bit6` | нижній ряд, вага 32 |
| `board1 bit7` | нижній ряд, вага 16 |
| `board2 bit0` | нижній ряд, вага 8 |
| `board2 bit1` | нижній ряд, вага 4 |
| `board2 bit2` | нижній ряд, вага 2 |
| `board2 bit3` | нижній ряд, вага 1 |
| `board2 bit4` | T/time; у alarm mode статус selected slot |
| `board2 bit5` | D/date; у alarm mode старший біт номера slot |
| `board2 bit6` | E/environment; у alarm mode молодший біт номера slot |
| `board2 bit7` | alarm indicator |

### 8.2 Значення режимів

- **TIME:** верхній ряд - години у binary, нижній - хвилини;
- **DATE:** верхній ряд - місяць, нижній - день;
- **ENVIRONMENT:** верхній ряд - температура у binary; нижній - шкала
  вологості;
- **ALARM:** два ряди - час вибраного будильника; mode LEDs кодують номер і
  enabled state;
- **BATTERY:** верхній ряд вимкнений, нижній - шкала з 0..6 LED.

Шкала вологості реалізована так:

| RH | Кількість LED |
| ---: | ---: |
| `<=30%` | 0 |
| 40% | 1 |
| 50% | 2 |
| 60% | 3 |
| 70% | 4 |
| 80% | 5 |
| `>=90%` | 6 |

LED шкали заповнюються від молодшої ваги: 1, 2, 4, 8, 16, 32.

### 8.3 PWM яскравості

OE регістрів активний низьким рівнем. TIM2_CH1 налаштований вручну:

| Регістр | Значення |
| --- | --- |
| PSC | 7 |
| ARR | 99 |
| CCR1 | 0..100 |
| PWM mode | mode 1, preload enabled |
| Polarity | inverted через `CC1P` |

При 4.194304 MHz PWM має приблизно 5.24 kHz; у режимі очікування дисплей уже
вимкнений, тому зміна core clock не впливає на видиму яскравість.

BH1750 задає 10 дискретних рівнів у діапазоні 2-50%.

## 9. Програмний I2C

Шина реалізована bit-bang GPIO, без апаратного I2C, DMA та interrupt transfer.

| Параметр | Значення |
| --- | --- |
| SCL | PA9 |
| SDA | PA10 |
| GPIO mode | open-drain output |
| Внутрішні pull-up | увімкнені |
| Зовнішні pull-up у KiCad | 4.7 kOhm на кожній лінії |
| Software delay | 8 коротких loop iterations на edge |
| Clock stretching | не підтримується явно |
| Bus arbitration | не підтримується |

На одній шині працюють:

| Пристрій | 7-bit address |
| --- | ---: |
| OLED | `0x3C`, fallback `0x3D` |
| AHT10 | `0x38` |
| BH1750 | `0x23` |

OLED має власну копію low-level I2C-функцій, а AHT10/BH1750 використовують
реалізацію з `board.c`. Доступ до шини не арбітрується mutex/state machine, але
всі операції виконуються послідовно з одного main loop.

## 10. OLED 128x32

Поточний драйвер орієнтований на SSD1306-compatible 128x32:

| Параметр | Значення |
| --- | --- |
| Розмір | 128 x 32 px |
| Сторінки | 4 сторінки по 8 px |
| Power-on delay | 80 ms |
| Probe retries | 3 |
| Text chunk | 24 bytes/columns |
| Мінімальний redraw interval | 200 ms |

Драйвер:

- пробує адресу `0x3C`, потім `0x3D`;
- виконує bus recovery перед probe;
- має вбудований 5x7 font;
- масштабує текст 2x у два OLED pages;
- кешує останні відображені значення й не перерисовує незмінний екран;
- групує символи в I2C chunks до 24 bytes;
- очищає весь framebuffer OLED при переходах до/з alarm і battery та при
  переході між alarm list/edit;
- під час звичайного оновлення часу/дати пише лише потрібні області.

Поточна відрисовка синхронна. Окремої черги дрібних OLED jobs і функції
`Process()` немає; довгі clear/battery operations блокують main loop на час
I2C-транзакцій.

Формати:

| Mode | OLED output |
| --- | --- |
| TIME | `HH:MM:SS`; `A` у правому нижньому куті, якщо є enabled alarm |
| DATE | `DD.MM.YY` |
| ENVIRONMENT | `Txx Hxx` або `T-- H--` |
| ALARM list | `*A1 HH:MM ON`, `-A2 --:-- OFF` тощо |
| ALARM edit | один slot великим шрифтом, `..` над hours/minutes |
| BATTERY | `BAT xx.x%` та смуга 120 px |
| Active alarm | `ALARM n`, запис один раз до завершення alarm |

## 11. AHT10

| Параметр | Значення |
| --- | --- |
| Address | `0x38` |
| Bus recovery | 9 SCL pulses та STOP перед initialization |
| Soft reset | `BA`, після 40 ms очікування; далі 20 ms до init command |
| Init command | `E1 08 00` |
| Init delay | 40 ms після init command |
| Measure command | `AC 33 00` |
| Conversion wait | 80 ms |
| Busy timeout | 200 ms після завершення measure command |
| Response | 6 bytes |
| Мінімальний interval | 15 s |
| Busy flag | byte 0, bit `0x80` |

Humidity і temperature вилучаються як 20-бітні значення. Результат округлюється
до цілих одиниць:

- humidity обмежується 0..100% RH;
- temperature обмежується 0..99 C;
- від'ємні temperature зараз примусово стають 0 C;
- LED-дисплей додатково обмежує temperature до 60.

Measurement розділена на start і read, тому 80 ms очікування не виконується
через блокувальний `HAL_Delay`. Відлік починається після завершення measure
command, а не до initialization. Busy response залишає measurement pending
для наступної спроби scheduler; після 200 ms дані позначаються invalid і стан
initialization скидається. При помилці запису/читання драйвер також повторно
ініціалізує сенсор із bus recovery та soft reset.

## 12. BH1750

| Параметр | Значення |
| --- | --- |
| Address | `0x23` |
| Power on | `0x01` |
| Reset | `0x07` |
| Mode | continuous high-resolution, `0x10` |
| Read interval | 5 s |
| Lux conversion | `raw * 5 / 6`, приблизно `raw / 1.2` |

Мапування яскравості:

| Параметр | Значення |
| --- | ---: |
| Темний поріг | 2 lux |
| Верхній поріг | 400 lux |
| Рівні | 10 |
| Мінімальна яскравість | 2% |
| Максимальна яскравість | 50% |
| Hysteresis | 5 lux |

У разі відсутності/помилки BH1750 зберігається попередня PWM brightness.

## 13. Кнопки через ADC ladder

Схема:

```text
VCC peripheral -- 10k -- PA1 / ADC_IN1
                           |
                           +-- MODE -- 1k   -- GND
                           +-- SET  -- 2k   -- GND
                           +-- UP   -- 4.7k -- GND
                           +-- DOWN -- 10k  -- GND
                           +-- OFF  -- 20k  -- GND
```

ADC threshold values:

| Button | Максимальне значення ADC |
| --- | ---: |
| MODE | 470 |
| SET | 950 |
| UP | 1630 |
| DOWN | 2330 |
| OFF | 3360 |
| NONE | `>3360` |

ADC 12-bit, full scale 4095. Для кожного читання firmware виконує дві
конверсії та використовує останню. Подія звичайної кнопки формується на зміні
`NONE -> button`; auto-repeat для UP/DOWN не реалізований. OFF обробляється
окремо для long press.

Керування:

- MODE: `time -> date -> environment -> alarm -> battery -> time`;
- SET: перехід між edit fields;
- UP/DOWN: зміна значення або вибір alarm slot;
- OFF short: вихід із edit або toggle selected alarm;
- OFF hold 2 s: якщо щось enabled - вимкнути всі; інакше ввімкнути всі
  configured alarms;
- будь-яка кнопка під час звучання лише вимикає buzzer; її UI-команда
  відкидається до повного відпускання.

## 14. Будильники

### 14.1 Модель

- три slots: A1, A2, A3;
- кожен має `configured`, `enabled`, `hour`, `minute`;
- seconds не налаштовуються;
- trigger перевіряється кожні 20 ms (100 ms у режимі очікування) проти кешованого RTC часу, який
  оновлюється раз на секунду;
- hardware RTC Alarm interrupt не використовується;
- однакова hour/minute не запускається повторно в межах тієї самої хвилини;
- редагування або повторне ввімкнення slot очищає trigger guard;
- наступного дня той самий alarm знову спрацьовує, бо guard очищується після
  зміни minute.

### 14.2 Звуковий pattern

| Параметр | Ticks | Час при 50 Hz |
| --- | ---: | ---: |
| Buzzer on | 5 | 100 ms |
| Пауза між beep | 7 | 140 ms |
| Один beep step | 12 | 240 ms |
| Beeps у group | 3 | - |
| Group pause | 45 | 900 ms |
| Повний group | 81 | 1.62 s |
| Максимальна тривалість alarm | 3000 | 60 s |

Використовується активний buzzer: firmware лише подає/знімає DC керування на
PA6. Генерування звукової частоти PWM не потрібне.

### 14.3 Формат RTC backup storage

Firmware резервує 16 bytes у BKP0R-BKP3R і використовує перші 12 bytes.
Packing little-endian по чотири bytes на 32-bit register.

| Byte | Вміст |
| ---: | --- |
| 0 | signature `0xA7` |
| 1 | version `0x01` |
| 2 | A1 flags: bit0 configured, bit1 enabled |
| 3 | A1 hour |
| 4 | A1 minute |
| 5..7 | A2 flags/hour/minute |
| 8..10 | A3 flags/hour/minute |
| 11 | checksum |

Checksum: сума bytes 0..10 modulo 256, потім XOR із `0x5A`.

Під час завантаження образ читається до трьох разів. Якщо signature, version
або checksum неправильні, alarm slots очищуються в RAM. Невалідний образ не
перезаписується автоматично до наступної зміни налаштувань.

## 15. Battery sense і ADC

### 15.1 Апаратний дільник

KiCad показує:

```text
Bms+ -- 470k -- PB1 / ADC_IN9 -- 1M -- GND
```

Це дає коефіцієнт `1M / (470k + 1M) = 0.6803`. Firmware відновлює
напругу батареї за номіналами встановленого дільника:

```text
battery_mV = sense_mV * 1470 / 1000
```

При 3390 mV на BAT+ ненавантажений PB1 має близько 2306 mV. Попередня
пара 2140/3650 mV завищувала відновлену напругу батареї приблизно на 16%.
Вхідний опір мультиметра навантажує високоомний дільник: 1 MOhm паралельно
нижньому резистору знижує PB1 приблизно до 1747 mV і може викликати low-battery
mode. Для перевірки firmware вимірювати BAT+ зі знятим щупом PB1; сам PB1
перевіряти через ADC raw data та VREFINT або враховувати навантаження приладу.
Перевірка на платі при 4200 mV: ADC показав 2184 mV на PB1 зі щупом
мультиметра та 2870 mV після його зняття.
Після виправлення коефіцієнта firmware показав 4215 mV при встановлених
4200 mV на джерелі. При виміряних мультиметром 3380 mV на BAT+ firmware
показує близько 3338 mV: залишкова похибка близько 42 mV (1.2%). Це номінальне
масштабування дільника, а не точне калібрування всього вимірювального тракту.

### 15.2 ADC implementation

- ADC1 налаштовується напряму через регістри, без HAL ADC driver;
- channels: ADC_IN1, ADC_IN9 та internal VREFINT;
- 12-bit result, range 0..4095;
- увімкнений low-frequency mode;
- sampling time — 160.5 ADC clock cycles (`ADC_SMPR_SMPR`), включно з VREFINT;
- виконується hardware calibration;
- кожен channel читається двічі, використовується другий sample;
- sense voltage коригується через factory-calibrated VREFINT;
- напруга батареї вимірюється раз на 500 ms; low-battery check та percentage
  display використовують спільне кешоване значення;
- перед STANDBY ADC, VREFINT і regulator вимикаються.

### 15.3 Low-battery state

| Параметр | Значення |
| --- | ---: |
| Вхід у low battery | `<2900 mV` |
| Вихід із low battery | `>=3100 mV` |
| Confirm samples | 3 |
| Measurement interval | 500 ms |
| Hysteresis | 200 mV |
| Alarm LED blink | 1 s |

Підтвердження рахує лише нові вимірювання, а не повторні читання кешу.
Постійне перетинання порога підтверджується приблизно за 1–1.5 s.

Low-battery state не є STANDBY. У ньому:

- дисплеї та зовнішня індикація вимикаються;
- червоний alarm LED блимає раз на секунду;
- alarm trigger і buzzer продовжують працювати;
- кнопки продовжують читатися, тому alarm можна вимкнути;
- повернення вище 3.1 V відновлює активну частоту й time mode.

### 15.4 State-of-charge curve

Процент обчислюється piecewise-linear interpolation:

| Battery, mV | Charge, % |
| ---: | ---: |
| 4100 | 100 |
| 3800 | 90 |
| 3700 | 82 |
| 3600 | 73 |
| 3500 | 62 |
| 3400 | 50 |
| 3300 | 36 |
| 3200 | 22 |
| 3100 | 10 |
| 2900 | 0 |

Фільтр percentage: IIR `new = (old * 15 + sample + 8) / 16`. Відображене
значення оновлюється не частіше ніж раз на 2 s і лише при зміні не менше 2.0
percentage points. Значення 0% і 100% застосовуються одразу.

## 16. PIR і Sleep

PA7 читається як digital input без pull-up/pull-down. PIR повинен видавати
логічний рівень у межах 0..VDD MCU.

`userActivity` активний, якщо виконується хоча б одна умова:

- PA7 high;
- натиснута будь-яка кнопка;
- активне редагування;
- звучить alarm.

Без активності firmware очікує завершення повного фактичного циклу
`time -> date -> environment -> time`. Після цього:

- очищує LED і OLED;
- вимикає buzzer;
- знижує MSI з 4.194304 до 2.097152 MHz;
- збільшує інтервал обробки з 20 до 100 ms та спить між обробками;
- не читає AHT10/BH1750 і не оновлює OLED, бо повертається з `App_Tick()`
  одразу після перевірки motion/button/alarm.

Між обробками ядро входить у звичайний Sleep через `WFI`; STOP не
використовується. LPTIM1 від LSE 32.768 kHz генерує одноразове пробудження через
залишок інтервалу. Якщо обробка вже зайняла весь інтервал, наступна починається
одразу. SysTick зупиняється лише на час Sleep, а фактичний час LPTIM1 додається
до HAL tick із накопиченням дробових мілісекунд. Під час виконання коду SysTick
працює з кроком 1 ms, тому HAL delays і timeouts зберігають цей крок.
Handler замаскований до відновлення HAL tick і SysTick, але дозволений у NVIC
pending IRQ розбудить WFI або не дозволить заснути, якщо вже pending перед
WFI. Пробудження не залежить від event latch WFE або `SEVONPEND`.
Після читання лічильника LPTIM1
скидається, щоб не очищувати його flags поза ISR (ES0483). Під час
синхронізації ARR із LSE SysTick продовжує працювати. Якщо LSE не готовий,
використовується Sleep із пробудженням від звичайного SysTick кожні 1 ms.
Очікування синхронізації ARR обмежене timeout.

PA7, ADC-кнопки, battery та alarm перевіряються після кожного пробудження.
EXTI для PIR не використовується. Коротке натискання менш як 100 ms у режимі
очікування може бути пропущене. При виявленні активності частота відновлюється,
інтервал повертається до 20 ms, UI переходить до TIME. Low-battery mode також
має інтервал 20 ms, щоб зберігався ритм buzzer. RTC читається раз на 1 s.
ADC, TIM2 PWM і живлення сенсорів цей Sleep path не вимикає.

## 17. Повний STANDBY

STANDBY запускається незалежно від battery percentage, коли PA0/WKUP1 low.
Перевірка PA0 виконується першою у кожному application tick (20 ms активний,
100 ms у режимі очікування), тому PIR не
може заблокувати перехід при зникненні основного живлення.

Послідовність `Board_EnterStandby()`:

1. очистити 74HC595 та OLED;
2. вимкнути buzzer;
3. зупинити TIM2 PWM і примусово підняти OE;
4. перевести зовнішні GPIO в analog/no-pull;
5. чекати PA0 low до 25 s; якщо не впав - скасувати STANDBY;
6. debounce low 300 ms; якщо сигнал повернувся high - скасувати;
7. вимкнути ADC, VREFINT, ADC regulator і ADC clock;
8. вимкнути fast wake, увімкнути ultra-low-power;
9. очистити debug bit у DBGMCU;
10. перевести решту GPIO в analog/no-pull, не змінюючи PA0;
11. disable WKUP1, очистити WUF до reset, enable WKUP1;
12. `HAL_PWR_EnterSTANDBYMode()`.

Wake від PA0 викликає reset-like startup. RTC і BKP-регістри зберігаються лише
поки backup domain має достатнє живлення. Firmware не використовує RTC alarm
або RTC wakeup timer для виходу зі STANDBY.

## 18. Автоматичні режими та таймінги UI

| Подія | Значення |
| --- | ---: |
| TIME auto duration | 15 s |
| DATE auto duration | 5 s |
| ENV auto duration | 5 s |
| Пауза auto після user action | 30 s |
| Edit inactivity timeout | 60 s |
| Mode/edit blink | 800 ms |
| Empty alarm error | 1 s |
| OLED redraw throttle | 200 ms |
| RTC refresh | 1 s |
| BH1750 read | 5 s |
| AHT10 read | 15 s |

Automatic cycle містить лише TIME, DATE та ENVIRONMENT. ALARM не переходить
автоматично. BATTERY після завершення 30 s user pause використовує default
5-second duration і переходить у TIME.

Під час утримання кнопки 30-second user pause постійно перезапускається. Відлік
фактично починається після відпускання. Через 60 s бездіяльності edit mode
закривається як short OFF.

## 19. Ініціалізація та головний цикл

Порядок startup:

1. custom `HAL_InitTick()`;
2. `HAL_MspInit()`;
3. MSI 4.194304 MHz;
4. base GPIO;
5. direct-register ADC setup;
6. LSE + RTC;
7. board peripherals;
8. OLED probe/init;
9. UI state;
10. alarm backup load;
11. environment scheduler;
12. infinite main loop.

Кожні 20 ms (100 ms у режимі очікування) `App_Tick()` виконує:

1. PA0/STANDBY check;
2. RTC cache refresh, якщо минула 1 s;
3. alarm trigger check;
4. ADC button read і alarm-button suppression;
5. low-battery state check;
6. activity/idle handling;
7. battery percentage read;
8. auto mode update;
9. environment scheduler;
10. buzzer pattern update;
11. BH1750 brightness update;
12. 74HC595 render/write;
13. OLED conditional render;
14. full-auto-cycle idle check.

## 20. Збірка

### 20.1 Вимоги

- CMake 3.22+;
- Ninja;
- GNU Arm Embedded toolchain із prefix `arm-none-eabi-` у `PATH`;
- STM32CubeL0 sources вже збережені в репозиторії.

### 20.2 Команди

Debug:

```bash
cmake --preset Debug
cmake --build --preset Debug
arm-none-eabi-size build/Debug/l010f4p6.elf
```

Release:

```bash
cmake --preset Release
cmake --build --preset Release
arm-none-eabi-size build/Release/l010f4p6.elf
```

Обидві конфігурації використовують `-Os`, `-ffunction-sections`,
`-fdata-sections`, `--gc-sections` і `-flto`. Debug додає `-g3`, Release -
`-g0`. Linker використовує `nano.specs`.

У source list навмисно додано тільки потрібний RTC HAL module. ADC і I2C HAL
drivers не лінкуються, бо ці підсистеми реалізовані напряму.

## 21. Прошивання і debug

### 21.1 OpenOCD

```bash
openocd -f openocd.cfg \
  -c "init; reset halt; program build/Debug/l010f4p6.elf verify; reset run; shutdown"
```

OpenOCD settings:

- ST-Link DAP;
- SWD;
- adapter speed 100 kHz;
- `connect_assert_srst` / connect under reset;
- target work area `0x800` bytes;
- `srst_only srst_nogate`.

### 21.2 STM32CubeProgrammer CLI

```bash
STM32_Programmer_CLI \
  -c port=SWD mode=UR freq=50 \
  -w build/Debug/l010f4p6.elf -v -rst
```

`mode=UR` потрібен для надійного підключення під reset, особливо коли firmware
швидко переходить у STANDBY або стан низького споживання.

### 21.3 VS Code Cortex-Debug

Конфігурація `Debug OpenOCD`:

- device `STM32L010F4P6`;
- executable `build/Debug/l010f4p6.elf`;
- preLaunchTask: Debug build;
- remote timeout 20 s;
- reset run, 100 ms wait, halt, load, reset halt.

Cortex-M0+ цього MCU має обмежену кількість hardware breakpoints. Надлишкові
breakpoints дають OpenOCD error `Can not find free FPB Comparator`.

## 22. Error handling і діагностика

Поточні обмеження:

- `Error_Handler()` вимикає interrupts і входить у нескінченний loop;
- окремого error code на LED/OLED немає;
- failure `App_RTC_Init()` ігнорується в `main()`;
- OLED init failure лише встановлює `oledReady = 0`, LED-дисплей продовжує
  працювати;
- AHT10 failure показує invalid environment;
- BH1750 failure залишає попередню brightness;
- software I2C не має timeout на stuck SCL і не читає clock stretching;
- ADC ready/calibration loops переважно не мають аварійного timeout;
- weekday не обчислюється;
- negative AHT10 temperature не відображається;
- firmware не має brownout telemetry або журналу reset causes.

## 23. Відомі розбіжності та ризики

1. **74HC595 pin mapping:** KiCad не відповідає `board_config.h`; це треба
   виправити до виробництва.
2. **Battery divider calibration:** firmware використовує номінальний коефіцієнт
   1.47 для 470k/1M; точність залежить від допусків резисторів. Щуп мультиметра
   на PB1 змінює навантаження дільника і може спотворити перевірку.
3. **CubeMX clock report:** `.ioc` може показувати близько 2.097 MHz, але runtime
   стартує на 4.194304 MHz через ручну конфігурацію.
4. **Manual GPIO outside CubeMX:** PA6, PA7, PA9 і PA10 легко втратити під час
   необережної регенерації проєкту.
5. **LSE failure:** немає user-visible fault path, запуск продовжується.
6. **OLED blocking:** оптимізовано кешем і 24-byte chunks, але немає повністю
   асинхронного renderer.
7. **I2C duplication:** OLED і sensors мають дві low-level bit-bang
   реалізації, що збільшує Flash і ускладнює єдине відновлення bus.
8. **RAM margin:** лише 272 B понад зарезервовані heap/stack; великі локальні
   buffers небезпечні.
9. **Flash margin:** близько 2.23 KiB; нові features потребують size check.
10. **Schematic placeholders:** D1-D4, R1 і C3 не мають завершених BOM values.
11. **BOOT0:** очікується зовнішня прив'язка PB9 до GND; її слід перевірити на
    готовій PCB continuity test.
12. **PIR input:** PA7 без pull resistor; sensor output не повинен плавати при
    вимкненій периферії.

## 24. Контрольний список bring-up

### 24.1 До подачі живлення

- перевірити short між `+3.3V`, `VDD MCU`, `VCC peripheral` і GND;
- перевірити орієнтацію U1, U2, U3, D1-D4, C3, BT1 і Q1;
- перевірити фактичний pinout 2N2222 конкретного корпусу;
- перевірити PB9/BOOT0 -> GND;
- перевірити NRST pull-up 10 kOhm;
- перевірити LSE і два 15 pF capacitors;
- перевірити відповідність 74HC595 wiring до firmware, а не лише до KiCad;
- перевірити SCL/SDA pull-up 4.7 kOhm до правильної rail.

### 24.2 Перше живлення

- подати лабораторне 3.3 V з current limit;
- виміряти VDD і VDDA без значної різниці;
- переконатися, що NRST high, BOOT0 low;
- під'єднати SWD із NRST і використати connect under reset;
- прошити й verify ELF;
- перевірити запуск LSE та зміну seconds;
- перевірити обидва 74HC595 тестовим pattern;
- перевірити PWM на PA5/OE;
- просканувати фактичні I2C addresses;
- перевірити всі п'ять ADC button ranges;
- калібрувати BAT+ проти PB1 і показу firmware;
- перевірити PA0 low -> STANDBY та PA0 high -> wake;
- перевірити зникнення peripheral power на відсутність back-power через I2C.

### 24.3 Функціональний regression test

- TIME, DATE, ENV, ALARM, BATTERY на LED та OLED;
- дата 28/29 February для високосного й невисокосного року;
- три alarm slots, persistence після power cycle;
- повторне спрацювання наступного дня;
- зупинка alarm будь-якою кнопкою без виконання її UI action;
- long OFF toggle all;
- low battery 2.9 V та recover 3.1 V;
- buzzer продовжує звучати у low-battery mode;
- один повний auto cycle до Sleep із погашеними екранами;
- LPTIM1/LSE wake через залишок 20/100 ms, відсутність 1 ms SysTick wake під час Sleep;
- wake від PIR і кнопок;
- full STANDBY тільки від PA0 low;
- відновлення RTC і alarm backup після wake.

## 25. Рекомендовані наступні технічні роботи

Пріоритет 1:

- синхронізувати 74HC595 mapping у KiCad і firmware;
- зафіксувати точні part numbers D1-D4, R1 та C3;
- повторно відкалібрувати battery divider мінімум у трьох точках;
- додати явну індикацію LSE/RTC initialization failure.

Пріоритет 2:

- об'єднати дві software-I2C реалізації;
- додати timeout і bus-recovery для всіх I2C transactions;
- винести OLED у неблокувальну чергу малих jobs;
- зменшити linker heap reservation після stack-usage audit;
- додати build-time size limit, щоб Flash/RAM overflow ловився в CI.

Пріоритет 3:

- обчислювати weekday;
- підтримати negative temperature;
- зберігати reset cause для сервісної діагностики;
- додати production self-test для LED, buttons, I2C sensors, buzzer і battery
  ADC.

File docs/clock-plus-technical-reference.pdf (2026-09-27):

# CLOCK PLUS

## Технічна документація

ПЛАТФОРМА | STM32L010F4P6 / Cortex-M0+
РЕДАКЦІЯ | Первинна технічна редакція
ЗВІРЕНО | 2026-09-27, гілка optimizations
СКЛАД | Hardware, firmware, power states, build, KiCad appendices

Повний довідник апаратної частини та firmware з оригінальною принциповою схемою і комплектом шарів PCB.

CLOCK PLUS / STM32L010F4P6

Сторінка 2

# Зміст

1. Джерела даних | 4
2. Призначення та склад системи | 4
3. Мікроконтролер і ресурси | 4
4. Архітектура вихідного коду | 6
5. Карта контактів MCU | 6
6. Апаратна схема | 7
7. RTC і календар | 9
8. 16-LED дисплей і 74HC595 | 9
9. Програмний I2C | 11
10. OLED 128x32 | 11
11. AHT10 | 12
12. BH1750 | 12
13. Кнопки через ADC ladder | 13
14. Будильники | 14
15. Battery sense і ADC | 15

16. PIR і псевдосон | 16
17. Повний STANDBY | 16
18. Автоматичні режими та таймінги UI | 17
19. Ініціалізація та головний цикл | 17
20. Збірка | 18
21. Прошивання і debug | 18
22. Error handling і діагностика | 19
23. Відомі розбіжності та ризики | 19
24. Контрольний список bring-up | 20
25. Рекомендовані наступні технічні роботи | 21
Технічні додатки KiCad | 22

# 1. Джерела даних

Документ складено за такими файлами:

- Core/Src/main.c - запуск, системна частота, RTC, головний цикл і стани

живлення;

- Core/Src/board.h - апаратний API та формат 16-бітного LED-дисплея;
- Core/Src/boards/l010f4p6/board.c - GPIO, ADC, 74HC595, програмний I2C,

AHT10, BH1750, батарея, buzzer і STANDBY;

- Core/Src/boards/l010f4p6/board_config.h - апаратні контакти, пороги й

калібрування;

- Core/Src/boards/l010f4p6/oled_128x32.c - драйвер OLED 128x32;
- Core/Src/app/* - UI, автоматична зміна режимів, відображення, датчики й

будильники;

- Core/Src/boards/l010f4p6/README.md - опис плати й інструкції збірки;
- l010f4p6.ioc - конфігурація STM32CubeMX;
- STM32L010XX_FLASH.ld - карта Flash/RAM;
- CMakeLists.txt, CMakePresets.json, .vscode/* та openocd.cfg - збірка,

debug і прошивання;

- docs/Clock i2c l0.pdf - принципова схема KiCad;
- docs/Clock i2c l0 pcb.pdf - дев'ятисторінковий комплект шарів PCB;
- docs/Clocl i2C l0 16 -2 595/Clock i2c l0.kicad_sch - вихідна схема;
- docs/Clocl i2C l0 16 -2 595/Clock i2c l0.kicad_pcb - вихідна PCB.

# 2. Призначення та склад системи

Clock Plus - автономний бінарний годинник із двома засобами індикації:

- 16 світлодіодів через два послідовно з'єднані 74HC595;
- OLED 0.91 дюйма, 128x32, I2C, сумісний із SSD1306.

Функціональні вузли:

- RTC мікроконтролера від зовнішнього LSE 32.768 kHz;
- три незалежні щоденні будильники;
- активний buzzer через NPN-транзистор;
- AHT10 для температури й вологості;
- BH1750 для освітленості та автоматичної яскравості;
- PIR AM312/HC-SR312 для контролю присутності;
- п'ять кнопок через один ADC-резистивний ladder;
- контроль напруги 18650 через ADC;
- псевдосон без зупинки ядра та повний STANDBY при зникненні основного

живлення;

- SWD для програмування та налагодження.

# 3. Мікроконтролер і ресурси

Параметр | Значення
MCU | STM32L010F4P6
Ядро | Arm Cortex-M0+
Корпус | TSSOP-20
Flash | 16 KiB, адреса 0x08000000
SRAM | 2 KiB, адреса 0x20000000
Активна частота | MSI range 6, 4.194304 MHz
Частота псевдосну | MSI range 5, 2.097152 MHz
RTC clock | LSE 32.768 kHz
Системний tick | SysTick, 1 ms
Період головного циклу | 20 ms, 50 Hz
Мова | C11 із GNU extensions
HAL/CMSIS | STM32CubeL0 FW 1.12.4

## 3.1 Поточне використання пам'яті

Перевірено збірками Debug і Release 2026-09-27. Через однакову оптимізацію -Os і LTO їхній виконуваний образ має однаковий розмір.

Область | Використано | Доступно | Частка
Flash | 14,100 B | 16,384 B | 86.06%
RAM разом із резервом heap/stack | 1,776 B | 2,048 B | 86.72%
.text | 13,592 B | - | -
.rodata | 256 B | - | -
.data | 52 B | - | -
.bss | 188 B | - | -
_user_heap_stack | 1,536 B | - | -

Налаштування linker script:

- мінімальний heap: 0x200 = 512 B;
- мінімальний stack: 0x400 = 1024 B;
- запас Flash до межі регіону: 2,284 B;
- запас RAM з урахуванням зарезервованих heap/stack: 272 B.

У firmware не використовується динамічна пам'ять, тому резерв heap можна переглянути окремою оптимізацією після перевірки всіх бібліотечних залежностей.

# 4. Архітектура вихідного коду

Core/Src/main.c
запуск MCU, clock, ADC base, RTC, main loop, power-state orchestration

Core/Src/board.h
апаратно-незалежні типи та API плати

Core/Src/boards/l010f4p6/
board.c | GPIO, ADC, PWM, I2C, датчики, battery, standby
board_config.h | контакти, пороги, калібрування
oled_128x32.c/.h | OLED SSD1306-compatible

Core/Src/app/
alarm/ | три alarm slots, trigger, buzzer, RTC backup storage
display/ | формування 16-бітної LED-маски
environment/ | планувальник читання AHT10
ui/ | кнопки, edit states, auto modes
core/ | спільні типи та константи

Апаратна залежність зосереджена в board.c. Застосунок працює через функції Board_*, але OLED поки що викликається напряму з main.c.

# 5. Карта контактів MCU

## 5.1 Карта, яку використовує поточний firmware

Контакт MCU | Напрямок/периферія | Функція | Електричні примітки
PA0 | digital input / WKUP1 | наявність основного живлення, wake зі STANDBY | високий = живлення є; низький = підготовка до STANDBY
PA1 | ADC_IN1 | п'ять кнопок через resistor ladder | analog, без внутрішньої підтяжки
PA2 | GPIO output | 74HC595 SER/DS | serial data, pin 14 регістра
PA3 | GPIO output | 74HC595 RCLK/ST_CP | latch, pin 12
PA4 | GPIO output | 74HC595 SRCLK/SH_CP | shift clock, pin 11
PA5 | TIM2_CH1 AF5 | 74HC595 OE | active-low PWM, pin 13
PA6 | GPIO output | активний buzzer через NPN | high = звук увімкнено
PA7 | digital input | PIR motion | high = рух; внутрішньої підтяжки немає
PA9 | GPIO open-drain | software I2C SCL | OLED, AHT10, BH1750
PA10 | GPIO open-drain | software I2C SDA | OLED, AHT10, BH1750
PA13 | SWDIO | програмування/debug | роз'єм SWD
PA14 | SWCLK | програмування/debug | роз'єм SWD
PB1 | ADC_IN9 | BAT+ sense | через резистивний дільник
PC14 | OSC32_IN | LSE input | кварц 32.768 kHz
PC15 | OSC32_OUT | LSE output | кварц 32.768 kHz
NRST | reset input | hardware reset/connect-under-reset | зовнішня підтяжка до VDD MCU
PB9/BOOT0 | boot selection | штатно притиснутий до GND | очікується normal boot from Flash

## 5.2 CubeMX проти runtime-конфігурації

У l010f4p6.ioc описані PA0, PA1, PA2-PA5, PB1, PC14/PC15 та SWD. Контакти PA6, PA7, PA9 і PA10 ініціалізуються вручну в board layer і не повністю представлені в CubeMX. Після повторної генерації CubeMX необхідно перевіряти:

- збереження всіх блоків USER CODE;
- Board_Init() для PA6, PA7 і програмного I2C;
- CMake source list;

- ручну ініціалізацію ADC, системної частоти та SysTick.

## 5.3 Критична розбіжність KiCad і firmware

Поточна схема Clock i2c l0.kicad_sch підписує сигнали так:

Контакт | KiCad-схема | Поточний firmware
PA2 | RCLK/ST_CP | SER/DS
PA3 | OE | RCLK/ST_CP
PA4 | SER/DS | SRCLK/SH_CP
PA5 | SRCLK | OE/TIM2_CH1

Це не косметична різниця: PA5 потрібен firmware як TIM2_CH1 для PWM. Перед замовленням PCB треба або перерозвести KiCad під firmware, або синхронно змінити board_config.h, GPIO і TIM2. Поточна перевірена програмна карта наведена в розділі 5.1.

# 6. Апаратна схема

## 6.1 PCB

Параметри поточного KiCad PCB:

Параметр | Значення
Габарит | 120 x 80 mm
Шари міді | 2: F.Cu, B.Cu
Матеріал | FR4
Товщина плати | 1.6 mm
Мідь | 35 um на кожному боці
Кількість footprints | 77
Монтажні отвори | 4 x 3.3 mm
Координати отворів від origin KiCad | (22.65, 22.65), (22.65, 97.45), (137.35, 22.65), (137.35, 97.35) mm

У docs/Clock i2c l0 pcb.pdf наведено дев'ять сторінок виробничого перегляду шарів. Джерело PCB має кілька історичних snapshot-файлів before-*; актуальним вважається файл без суфікса.

## 6.2 Основні компоненти зі схеми

Позначення | Компонент/номінал | Призначення
U1 | STM32L010F4Px | MCU
U2, U3 | 74HC595, SOIC-16 | 16 LED outputs
Y1 | 32.768 kHz crystal | LSE для RTC
C7, C8 | 15 pF | load capacitors LSE
C1, C2 | 100 nF | локальне decoupling VDD/VDDA
C4 | 10 uF | bulk decoupling VDD MCU
C3 | polarized, номінал у схемі не заданий | резервне живлення/накопичення
R2 | 10 kOhm | NRST pull-up
R3 | 220 kOhm | PA0/WKUP pull-down у схемі
R5 | 470 kOhm | верхнє плече BAT+ sense
R8 | 1 MOhm | нижнє плече BAT+ sense
R6, R9 | 4.7 kOhm | pull-up SCL/SDA до VCC peripheral
R7 | 10 kOhm | PB9/BOOT0 pull-down до GND
R27 | 10 kOhm | pull-up button ladder до VCC peripheral
R28-R32 | 1 k, 2 k, 4.7 k, 10 k, 20 kOhm | MODE, SET, UP, DOWN, OFF
R10 | 2 kOhm | base resistor buzzer transistor
Q1 | 2N2222 | low-side key активного buzzer
R11-R26 | 200 Ohm | струмообмеження 16 LED
BT1 | 18650 | акумулятор
J3 | BMS, 4 pin | BMS connection
J4 | buck-boost, 4 pin | перетворювач до 3.3 V
J2 | SWD, 5 pin | SWCLK, SWDIO, GND, VDD MCU, NRST
J5 | OLED, 4 pin | SDA, SCL/SCK, VCC peripheral, GND
J6 | GY-302/BH1750, 4 pin | VCC, GND, SCL, SDA
J7 | AHT10, 4 pin | VCC, GND, SCL, SDA
J1 | AM312/HC-SR312, 3 pin | PIR output, VCC, GND
BZ1 | active buzzer | звуковий сигнал

На схемі D1-D4 та R1 мають загальні позначення без конкретного part number або номіналу. Їх треба конкретизувати в BOM перед виробництвом.

## 6.3 Живлення

Схема розділяє щонайменше такі мережі:

- +3.3V - основний вихід buck-boost;
- VCC периферія - OLED, сенсори, 74HC595, LED, PIR і buzzer;
- VDD MCU - VDD та VDDA мікроконтролера;
- Bms+, Bms- - акумуляторна сторона BMS;
- GND.

Між основним живленням, периферією та MCU використано діоди D1-D4, резистор R1 і полярний накопичувальний конденсатор C3. Ідея вузла - не допустити живлення вимкненої периферії через GPIO/I2C і дати RTC/MCU час коректно перейти в STANDBY.

Firmware додатково переводить зовнішні лінії в analog/no-pull перед STANDBY, щоб зменшити leakage і back-powering. Діодна розв'язка не скасовує вимоги, що сигнал на вході MCU не повинен перевищувати VDD MCU більш ніж допускає datasheet.

## 6.4 Decoupling і LSE

- C1 і C2: 100 nF біля VDD та VDDA;
- C4: 10 uF на VDD MCU;
- LSE: Y1 32.768 kHz між PC14 і PC15;
- C7 і C8: по 15 pF від кожного виводу кварцу до GND;
- доріжки LSE повинні бути короткими, симетричними й віддаленими від LED/PWM;
- точне значення load capacitors слід перевірити за CL конкретного кварцу та

паразитною ємністю PCB. 15 pF - значення поточної схеми, а не універсальне правило.

# 7. RTC і календар

RTC тактується від зовнішнього LSE:

Налаштування | Значення
LSE | 32.768 kHz
Drive | RCC_LSEDRIVE_HIGH
Формат часу | 24 години
Async prescaler | 127
Sync prescaler | 255
RTC output | disabled

Під час запуску App_RTC_Init():

1. відкриває доступ до backup domain;
2. скидає backup domain, якщо RTC clock source не LSE;
3. запускає LSE через HAL_RCC_OscConfig();
4. перевіряє LSERDY;
5. вибирає LSE для RTC та вмикає RTC;
6. викликає HAL_RTC_Init().

Якщо запуск LSE або RTC не вдався, функція повертає 0, але main() зараз ігнорує результат і продовжує запуск. Окремої індикації LSE failure немає.

Поточний час читається раз на 1000 ms. За вимогою STM32 HAL після HAL_RTC_GetTime() одразу викликається HAL_RTC_GetDate() для коректного розблокування shadow registers.

Рік зберігається як 00..99 та інтерпретується UI як 2000-2099. Високосний рік визначається через year % 4 == 0, що коректно для цього діапазону. Board_WriteDate() записує weekday як Monday; weekday у UI не використовується і не обчислюється з дати.

# 8. 16-LED дисплей і 74HC595

Використано два каскадно з'єднані 74HC595. Firmware передає спочатку board2 від MSB до LSB, потім board1 від MSB до LSB, після чого формує імпульс latch.

### 8.1 Формат ClockDisplay_t

Байт/біт | Значення у звичайних режимах
board1 bit0 | верхній ряд, вага 32
board1 bit1 | верхній ряд, вага 16
board1 bit2 | верхній ряд, вага 8
board1 bit3 | верхній ряд, вага 4
board1 bit4 | верхній ряд, вага 2
board1 bit5 | верхній ряд, вага 1
board1 bit6 | нижній ряд, вага 32
board1 bit7 | нижній ряд, вага 16
board2 bit0 | нижній ряд, вага 8
board2 bit1 | нижній ряд, вага 4
board2 bit2 | нижній ряд, вага 2
board2 bit3 | нижній ряд, вага 1
board2 bit4 | T/time; у alarm mode статус selected slot
board2 bit5 | D/date; у alarm mode старший біт номера slot
board2 bit6 | E/environment; у alarm mode молодший біт номера slot
board2 bit7 | alarm indicator

## 8.2 Значення режимів

- TIME: верхній ряд - години у binary, нижній - хвилини;
- DATE: верхній ряд - місяць, нижній - день;
- ENVIRONMENT: верхній ряд - температура у binary; нижній - шкала

вологості;

- ALARM: два ряди - час вибраного будильника; mode LEDs кодують номер і

enabled state;

- BATTERY: верхній ряд вимкнений, нижній - шкала з 0..6 LED.

Шкала вологості реалізована так:

RH | Кількість LED
<=30% | 0
40% | 1
50% | 2
60% | 3
70% | 4
80% | 5
>=90% | 6

LED шкали заповнюються від молодшої ваги: 1, 2, 4, 8, 16, 32.

## 8.3 PWM яскравості

OE регістрів активний низьким рівнем. TIM2_CH1 налаштований вручну:

Регістр | Значення
PSC | 7
ARR | 99
CCR1 | 0..100
PWM mode | mode 1, preload enabled
Polarity | inverted через CC1P

При 4.194304 MHz PWM має приблизно 5.24 kHz; у псевдосні дисплей уже вимкнений, тому зміна core clock не впливає на видиму яскравість.

BH1750 задає 10 дискретних рівнів у діапазоні 2-50%.

# 9. Програмний I2C

Шина реалізована bit-bang GPIO, без апаратного I2C, DMA та interrupt transfer.

Параметр | Значення
SCL | PA9
SDA | PA10
GPIO mode | open-drain output
Внутрішні pull-up | увімкнені
Зовнішні pull-up у KiCad | 4.7 kOhm на кожній лінії
Software delay | 8 коротких loop iterations на edge
Clock stretching | не підтримується явно
Bus arbitration | не підтримується

На одній шині працюють:

Пристрій | 7-bit address
OLED | 0x3C, fallback 0x3D
AHT10 | 0x38
BH1750 | 0x23

OLED має власну копію low-level I2C-функцій, а AHT10/BH1750 використовують реалізацію з board.c. Доступ до шини не арбітрується mutex/state machine, але всі операції виконуються послідовно з одного main loop.

# 10. OLED 128x32

Поточний драйвер орієнтований на SSD1306-compatible 128x32:

Параметр | Значення
Розмір | 128 x 32 px
Сторінки | 4 сторінки по 8 px
Power-on delay | 80 ms
Probe retries | 3
Text chunk | 24 bytes/columns
Мінімальний redraw interval | 200 ms

Драйвер:

- пробує адресу 0x3C, потім 0x3D;
- виконує bus recovery перед probe;
- має вбудований 5x7 font;

- масштабує текст 2x у два OLED pages;
- кешує останні відображені значення й не перерисовує незмінний екран;
- групує символи в I2C chunks до 24 bytes;
- очищає весь framebuffer OLED при переходах до/з alarm і battery та при

переході між alarm list/edit;

- під час звичайного оновлення часу/дати пише лише потрібні області.

Поточна відрисовка синхронна. Окремої черги дрібних OLED jobs і функції Process() немає; довгі clear/battery operations блокують main loop на час I2C-транзакцій.

Формати:

Mode | OLED output
TIME | HH:MM:SS; A у правому нижньому куті, якщо є enabled alarm
DATE | DD.MM.YY
ENVIRONMENT | Txx Hxx або T-- H--
ALARM list | *A1 HH:MM ON, -A2 --:-- OFF тощо
ALARM edit | один slot великим шрифтом, .. над hours/minutes
BATTERY | BAT xx.x% та смуга 120 px
Active alarm | ALARM n, запис один раз до завершення alarm

# 11. AHT10

Параметр | Значення
Address | 0x38
Init command | E1 08 00
Init delay | 40 ms до і 40 ms після command
Measure command | AC 33 00
Conversion wait | 80 ms
Response | 6 bytes
Мінімальний interval | 15 s
Busy flag | byte 0, bit 0x80

Humidity і temperature вилучаються як 20-бітні значення. Результат округлюється до цілих одиниць:

- humidity обмежується 0..100% RH;
- temperature обмежується 0..99 C;
- від'ємні temperature зараз примусово стають 0 C;
- LED-дисплей додатково обмежує temperature до 60.

Measurement розділена на start і read, тому 80 ms очікування не виконується через блокувальний HAL_Delay. При помилці запису/читання дані позначаються invalid і драйвер повторно ініціалізує сенсор.

# 12. BH1750

Параметр | Значення
Address | 0x23
Power on | 0x01
Reset | 0x07
Mode | continuous high-resolution, 0x10
Read interval | 5 s
Lux conversion | raw * 5 / 6, приблизно raw / 1.2

Мапування яскравості:

Параметр | Значення
Темний поріг | 2 lux
Верхній поріг | 400 lux
Рівні | 10
Мінімальна яскравість | 2%
Максимальна яскравість | 50%
Hysteresis | 5 lux

У разі відсутності/помилки BH1750 зберігається попередня PWM brightness.

# 13. Кнопки через ADC ladder

Схема:

VCC peripheral -- 10k -- PA1 / ADC_IN1 |
+-- MODE -- 1k | -- GND
+-- SET | -- 2k | -- GND
+-- UP | -- 4.7k -- GND
+-- DOWN -- 10k | -- GND
+-- OFF | -- 20k | -- GND

ADC threshold values:

Button | Максимальне значення ADC
MODE | 470
SET | 950
UP | 1630
DOWN | 2330
OFF | 3360
NONE | >3360

ADC 12-bit, full scale 4095. Для кожного читання firmware виконує дві конверсії та використовує останню. Подія звичайної кнопки формується на зміні NONE -> button; auto-repeat для UP/DOWN не реалізований. OFF обробляється окремо для long press.

Керування:

- MODE: time -> date -> environment -> alarm -> battery -> time;
- SET: перехід між edit fields;
- UP/DOWN: зміна значення або вибір alarm slot;
- OFF short: вихід із edit або toggle selected alarm;
- OFF hold 2 s: якщо щось enabled - вимкнути всі; інакше ввімкнути всі

configured alarms;

- будь-яка кнопка під час звучання лише вимикає buzzer; її UI-команда

відкидається до повного відпускання.

# 14. Будильники

## 14.1 Модель

- три slots: A1, A2, A3;
- кожен має configured, enabled, hour, minute;
- seconds не налаштовуються;
- trigger перевіряється кожні 20 ms проти кешованого RTC часу, який

оновлюється раз на секунду;

- hardware RTC Alarm interrupt не використовується;
- однакова hour/minute не запускається повторно в межах тієї самої хвилини;
- редагування або повторне ввімкнення slot очищає trigger guard;
- наступного дня той самий alarm знову спрацьовує, бо guard очищується після

зміни minute.

## 14.2 Звуковий pattern

Параметр | Ticks | Час при 50 Hz
Buzzer on | 5 | 100 ms
Пауза між beep | 7 | 140 ms
Один beep step | 12 | 240 ms
Beeps у group | 3 | -
Group pause | 45 | 900 ms
Повний group | 81 | 1.62 s
Максимальна тривалість alarm | 3000 | 60 s

Використовується активний buzzer: firmware лише подає/знімає DC керування на PA6. Генерування звукової частоти PWM не потрібне.

## 14.3 Формат RTC backup storage

Firmware резервує 16 bytes у BKP0R-BKP3R і використовує перші 12 bytes. Packing little-endian по чотири bytes на 32-bit register.

Byte | Вміст
0 | signature 0xA7
1 | version 0x01
2 | A1 flags: bit0 configured, bit1 enabled
3 | A1 hour
4 | A1 minute
5..7 | A2 flags/hour/minute
8..10 | A3 flags/hour/minute
11 | checksum

Checksum: сума bytes 0..10 modulo 256, потім XOR із 0x5A.

Під час завантаження образ читається до трьох разів. Якщо signature, version або checksum неправильні, alarm slots очищуються в RAM. Невалідний образ не перезаписується автоматично до наступної зміни налаштувань.

# 15. Battery sense і ADC

## 15.1 Апаратний дільник

KiCad показує:

Bms+ -- 470k -- PB1 / ADC_IN9 -- 1M -- GND

Це дає теоретичний коефіцієнт 1M / (470k + 1M) = 0.6803. Firmware, однак, відновлює напругу батареї за виміряною калібрувальною парою:

2140 mV на PB1 відповідає 3650 mV батареї
battery_mV = sense_mV * 3650 / 2140

Ефективний калібрувальний коефіцієнт становить 0.5863 і не збігається з ідеальним дільником 470k/1M. Це може враховувати фактичну плату, допуски, помилку монтажу або інший установленний номінал. Перед серійною ревізією треба повторно виміряти BAT+, PB1 і VDD та узгодити схему з константами.

## 15.2 ADC implementation

- ADC1 налаштовується напряму через регістри, без HAL ADC driver;
- channels: ADC_IN1, ADC_IN9 та internal VREFINT;
- 12-bit result, range 0..4095;
- увімкнений low-frequency mode;
- sampling time задається ADC_SMPR_SMPR_1;
- виконується hardware calibration;
- кожен channel читається двічі, використовується другий sample;
- sense voltage коригується через factory-calibrated VREFINT;
- перед STANDBY ADC, VREFINT і regulator вимикаються.

## 15.3 Low-battery state

Параметр | Значення
Вхід у low battery | <2900 mV
Вихід із low battery | >=3100 mV
Confirm samples | 3
Hysteresis | 200 mV
Alarm LED blink | 1 s

Low-battery state не є STANDBY. У ньому:

- дисплеї та зовнішня індикація вимикаються;
- червоний alarm LED блимає раз на секунду;
- alarm trigger і buzzer продовжують працювати;
- кнопки продовжують читатися, тому alarm можна вимкнути;
- повернення вище 3.1 V відновлює активну частоту й time mode.

## 15.4 State-of-charge curve

Процент обчислюється piecewise-linear interpolation:

Battery, mV | Charge, %
4100 | 100
3800 | 90
3700 | 82
3600 | 73
3500 | 62
3400 | 50
3300 | 36
3200 | 22
3100 | 10
2900 | 0

Фільтр percentage: IIR new = (old * 15 + sample + 8) / 16. Відображене значення оновлюється не частіше ніж раз на 2 s і лише при зміні не менше 2.0 percentage points. Значення 0% і 100% застосовуються одразу.

# 16. PIR і псевдосон

PA7 читається як digital input без pull-up/pull-down. PIR повинен видавати логічний рівень у межах 0..VDD MCU.

userActivity активний, якщо виконується хоча б одна умова:

- PA7 high;
- натиснута будь-яка кнопка;
- активне редагування;
- звучить alarm.

Без активності firmware очікує завершення повного фактичного циклу time -> date -> environment -> time. Після цього:

- очищує LED і OLED;
- вимикає buzzer;
- знижує MSI з 4.194304 до 2.097152 MHz;
- залишається у main loop;
- не читає AHT10/BH1750 і не оновлює OLED, бо повертається з App_Tick()

одразу після перевірки motion/button/alarm.

Це не STOP і не STANDBY. Пробудження не потребує interrupt: main loop продовжує опитувати PA7, кнопки й alarm. Після wake частота відновлюється, UI переходить до TIME.

# 17. Повний STANDBY

STANDBY запускається незалежно від battery percentage, коли PA0/WKUP1 low. Перевірка PA0 виконується першою у кожному 20 ms application tick, тому PIR не може заблокувати перехід при зникненні основного живлення.

Послідовність Board_EnterStandby():

1. очистити 74HC595 та OLED;
2. вимкнути buzzer;
3. зупинити TIM2 PWM і примусово підняти OE;
4. перевести зовнішні GPIO в analog/no-pull;
5. чекати PA0 low до 25 s; якщо не впав - скасувати STANDBY;
6. debounce low 300 ms; якщо сигнал повернувся high - скасувати;

7. вимкнути ADC, VREFINT, ADC regulator і ADC clock;
8. вимкнути fast wake, увімкнути ultra-low-power;
9. очистити debug bit у DBGMCU;
10. перевести решту GPIO в analog/no-pull, не змінюючи PA0;
11. disable WKUP1, очистити WUF до reset, enable WKUP1;
12. HAL_PWR_EnterSTANDBYMode().

Wake від PA0 викликає reset-like startup. RTC і BKP-регістри зберігаються лише поки backup domain має достатнє живлення. Firmware не використовує RTC alarm або RTC wakeup timer для виходу зі STANDBY.

# 18. Автоматичні режими та таймінги UI

Подія | Значення
TIME auto duration | 15 s
DATE auto duration | 5 s
ENV auto duration | 5 s
Пауза auto після user action | 30 s
Edit inactivity timeout | 60 s
Mode/edit blink | 800 ms
Empty alarm error | 1 s
OLED redraw throttle | 200 ms
RTC refresh | 1 s
BH1750 read | 5 s
AHT10 read | 15 s

Automatic cycle містить лише TIME, DATE та ENVIRONMENT. ALARM не переходить автоматично. BATTERY після завершення 30 s user pause використовує default 5-second duration і переходить у TIME.

Під час утримання кнопки 30-second user pause постійно перезапускається. Відлік фактично починається після відпускання. Через 60 s бездіяльності edit mode закривається як short OFF.

# 19. Ініціалізація та головний цикл

Порядок startup:

1. custom HAL_InitTick();
2. HAL_MspInit();
3. MSI 4.194304 MHz;
4. base GPIO;
5. direct-register ADC setup;
6. LSE + RTC;
7. board peripherals;
8. OLED probe/init;
9. UI state;
10. alarm backup load;
11. environment scheduler;
12. infinite main loop.

Кожні 20 ms App_Tick() виконує:

1. PA0/STANDBY check;
2. RTC cache refresh, якщо минула 1 s;
3. alarm trigger check;
4. ADC button read і alarm-button suppression;
5. low-battery state check;
6. activity/idle handling;
7. battery percentage read;
8. auto mode update;
9. environment scheduler;
10. buzzer pattern update;
11. BH1750 brightness update;
12. 74HC595 render/write;
13. OLED conditional render;
14. full-auto-cycle idle check.

# 20. Збірка

## 20.1 Вимоги

- CMake 3.22+;
- Ninja;
- GNU Arm Embedded toolchain із prefix arm-none-eabi- у PATH;
- STM32CubeL0 sources вже збережені в репозиторії.

## 20.2 Команди

Debug:

cmake --preset Debug
cmake --build --preset Debug arm-none-eabi-size build/Debug/l010f4p6.elf

Release:

cmake --preset Release
cmake --build --preset Release
arm-none-eabi-size build/Release/l010f4p6.elf

Обидві конфігурації використовують -Os, -ffunction-sections, -fdata-sections, --gc-sections і -flto. Debug додає -g3, Release - -g0. Linker використовує nano.specs.

У source list навмисно додано тільки потрібний RTC HAL module. ADC і I2C HAL drivers не лінкуються, бо ці підсистеми реалізовані напряму.

# 21. Прошивання і debug

## 21.1 OpenOCD

openocd -f openocd.cfg \
-c "init; reset halt; program build/Debug/l010f4p6.elf verify; reset run; shutdown"

OpenOCD settings:

- ST-Link DAP;
- SWD;
- adapter speed 100 kHz;

- connect_assert_srst / connect under reset;
- target work area 0x800 bytes;
- srst_only srst_nogate.

## 21.2 STM32CubeProgrammer CLI

STM32_Programmer_CLI \
-c port=SWD mode=UR freq=50 \
-w build/Debug/l010f4p6.elf -v -rst

mode=UR потрібен для надійного підключення під reset, особливо коли firmware швидко переходить у STANDBY або стан низького споживання.

## 21.3 VS Code Cortex-Debug

Конфігурація Debug OpenOCD:

- device STM32L010F4P6;
- executable build/Debug/l010f4p6.elf;
- preLaunchTask: Debug build;
- remote timeout 20 s;
- reset run, 100 ms wait, halt, load, reset halt.

Cortex-M0+ цього MCU має обмежену кількість hardware breakpoints. Надлишкові breakpoints дають OpenOCD error Can not find free FPB Comparator.

# 22. Error handling і діагностика

Поточні обмеження:

- Error_Handler() вимикає interrupts і входить у нескінченний loop;
- окремого error code на LED/OLED немає;
- failure App_RTC_Init() ігнорується в main();
- OLED init failure лише встановлює oledReady = 0, LED-дисплей продовжує

працювати;

- AHT10 failure показує invalid environment;
- BH1750 failure залишає попередню brightness;
- software I2C не має timeout на stuck SCL і не читає clock stretching;
- ADC ready/calibration loops переважно не мають аварійного timeout;
- weekday не обчислюється;
- negative AHT10 temperature не відображається;
- firmware не має brownout telemetry або журналу reset causes.

# 23. Відомі розбіжності та ризики

1. 74HC595 pin mapping: KiCad не відповідає board_config.h; це треба

виправити до виробництва.

2. Battery divider calibration: номінали 470k/1M не відповідають парі

2140/3650 mV у firmware; потрібне повторне вимірювання.

3. CubeMX clock report: .ioc може показувати близько 2.097 MHz, але runtime

стартує на 4.194304 MHz через ручну конфігурацію.

4. Manual GPIO outside CubeMX: PA6, PA7, PA9 і PA10 легко втратити під час

необережної регенерації проєкту.

5. LSE failure: немає user-visible fault path, запуск продовжується.
6. OLED blocking: оптимізовано кешем і 24-byte chunks, але немає повністю

асинхронного renderer.

7. I2C duplication: OLED і sensors мають дві low-level bit-bang

реалізації, що збільшує Flash і ускладнює єдине відновлення bus.

8. RAM margin: лише 272 B понад зарезервовані heap/stack; великі локальні

buffers небезпечні.

9. Flash margin: близько 2.23 KiB; нові features потребують size check.
10. Schematic placeholders: D1-D4, R1 і C3 не мають завершених BOM values.
11. BOOT0: очікується зовнішня прив'язка PB9 до GND; її слід перевірити на

готовій PCB continuity test.

12. PIR input: PA7 без pull resistor; sensor output не повинен плавати при

вимкненій периферії.

# 24. Контрольний список bring-up

## 24.1 До подачі живлення

- перевірити short між +3.3V, VDD MCU, VCC peripheral і GND;
- перевірити орієнтацію U1, U2, U3, D1-D4, C3, BT1 і Q1;
- перевірити фактичний pinout 2N2222 конкретного корпусу;
- перевірити PB9/BOOT0 -> GND;
- перевірити NRST pull-up 10 kOhm;
- перевірити LSE і два 15 pF capacitors;
- перевірити відповідність 74HC595 wiring до firmware, а не лише до KiCad;
- перевірити SCL/SDA pull-up 4.7 kOhm до правильної rail.

## 24.2 Перше живлення

- подати лабораторне 3.3 V з current limit;
- виміряти VDD і VDDA без значної різниці;
- переконатися, що NRST high, BOOT0 low;
- під'єднати SWD із NRST і використати connect under reset;
- прошити й verify ELF;
- перевірити запуск LSE та зміну seconds;
- перевірити обидва 74HC595 тестовим pattern;
- перевірити PWM на PA5/OE;
- просканувати фактичні I2C addresses;
- перевірити всі п'ять ADC button ranges;
- калібрувати BAT+ проти PB1 і показу firmware;
- перевірити PA0 low -> STANDBY та PA0 high -> wake;
- перевірити зникнення peripheral power на відсутність back-power через I2C.

## 24.3 Функціональний regression test

- TIME, DATE, ENV, ALARM, BATTERY на LED та OLED;
- дата 28/29 February для високосного й невисокосного року;
- три alarm slots, persistence після power cycle;
- повторне спрацювання наступного дня;
- зупинка alarm будь-якою кнопкою без виконання її UI action;
- long OFF toggle all;
- low battery 2.9 V та recover 3.1 V;
- buzzer продовжує звучати у low-battery mode;
- один повний auto cycle до псевдосну;
- wake від PIR і кнопок;
- full STANDBY тільки від PA0 low;
- відновлення RTC і alarm backup після wake.

# 25. Рекомендовані наступні технічні роботи

Пріоритет 1:

- синхронізувати 74HC595 mapping у KiCad і firmware;
- зафіксувати точні part numbers D1-D4, R1 та C3;
- повторно відкалібрувати battery divider мінімум у трьох точках;
- додати явну індикацію LSE/RTC initialization failure.

Пріоритет 2:

- об'єднати дві software-I2C реалізації;
- додати timeout і bus-recovery для всіх I2C transactions;
- винести OLED у неблокувальну чергу малих jobs;
- зменшити linker heap reservation після stack-usage audit;
- додати build-time size limit, щоб Flash/RAM overflow ловився в CI.

Пріоритет 3:

- обчислювати weekday;
- підтримати negative temperature;
- зберігати reset cause для сервісної діагностики;
- додати production self-test для LED, buttons, I2C sensors, buzzer і battery

ADC.

# Технічні додатки KiCad

Після цієї сторінки без змін додано оригінальний PDF принципової схеми та дев'ять сторінок PCB output. Вони є частиною технічного пакета, але в разі розбіжності поведінку поточної прошивки визначає вихідний код і таблиця перевірки у розділі 5.3.

Buzzer VCC периферія | Bms+VCC периферія
SW2 set R28 | 1K Q1

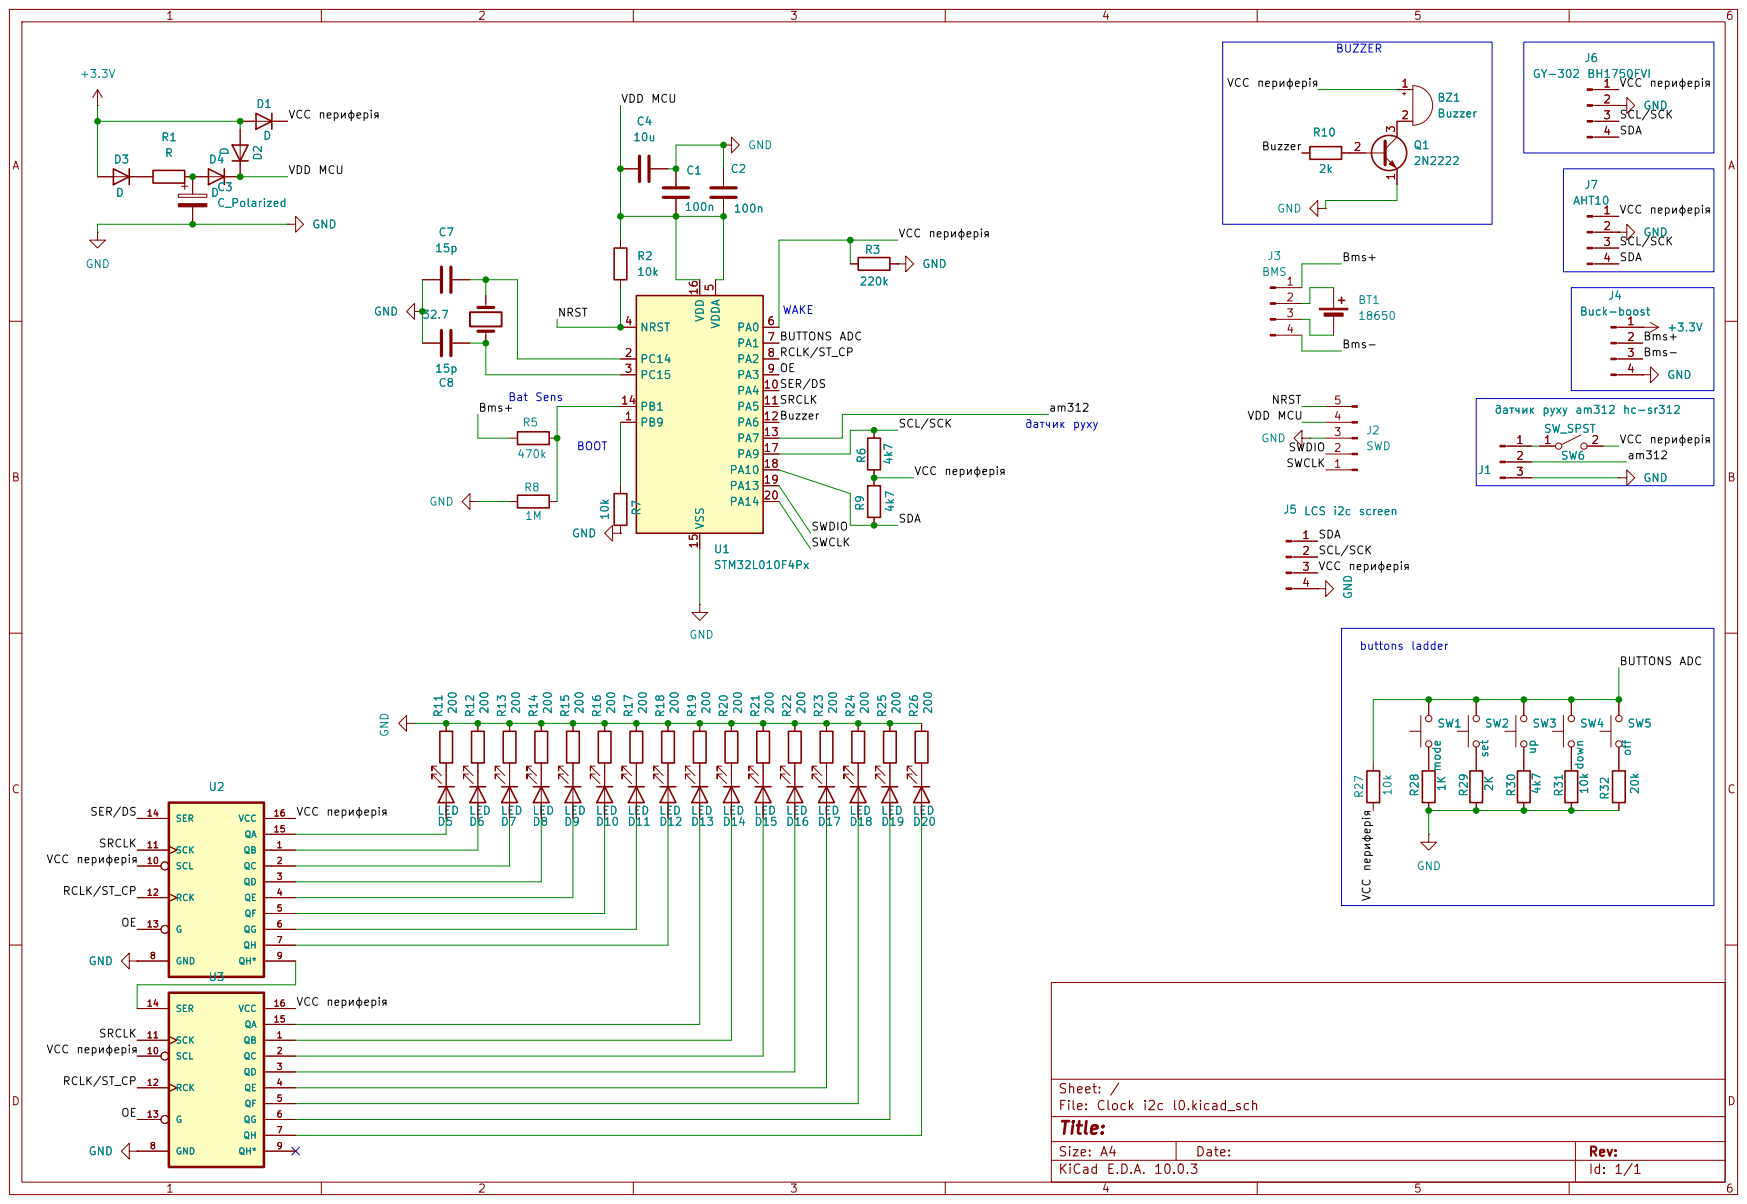
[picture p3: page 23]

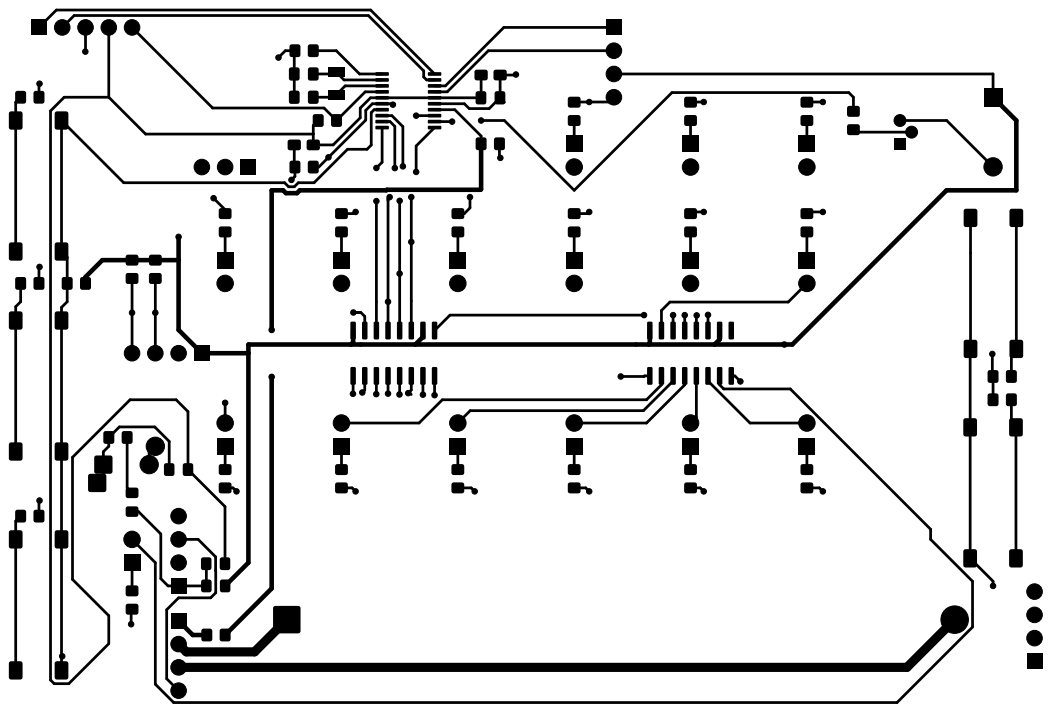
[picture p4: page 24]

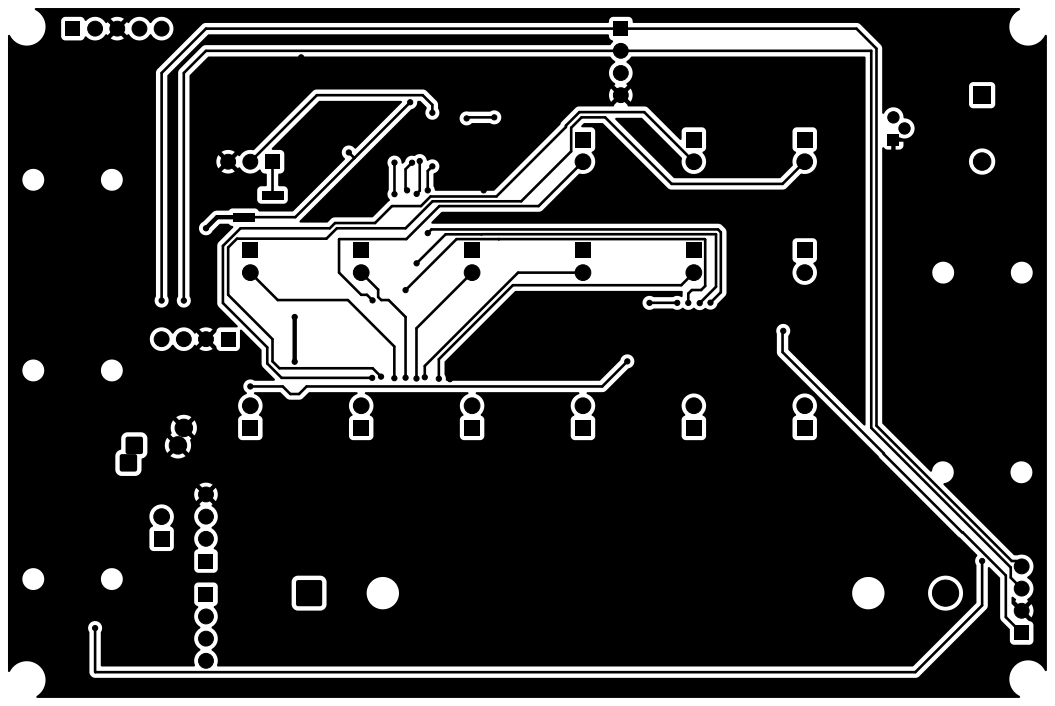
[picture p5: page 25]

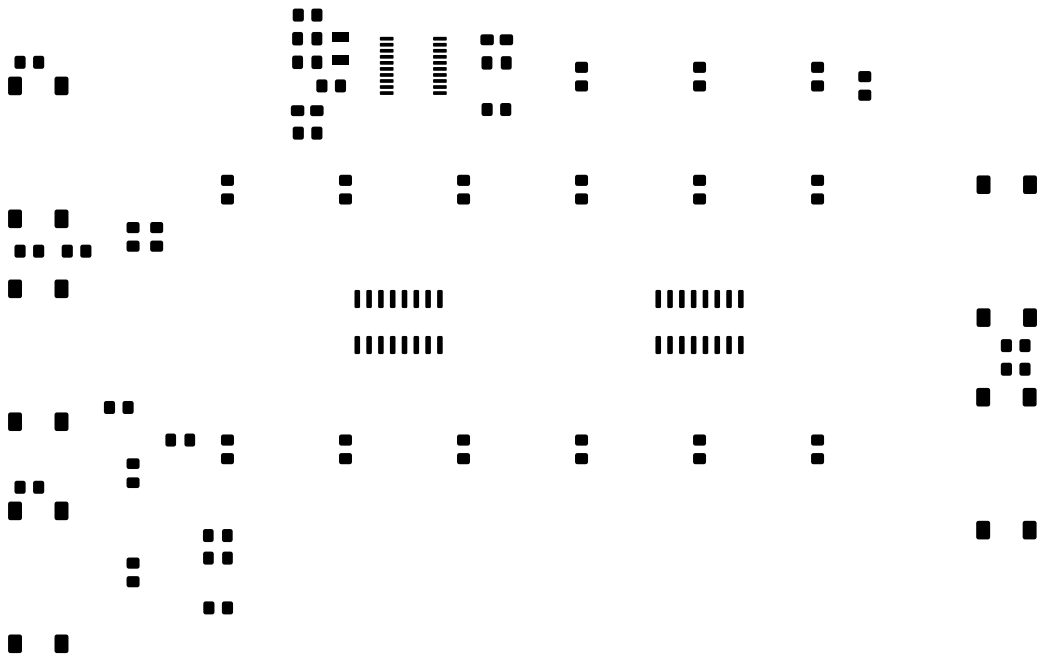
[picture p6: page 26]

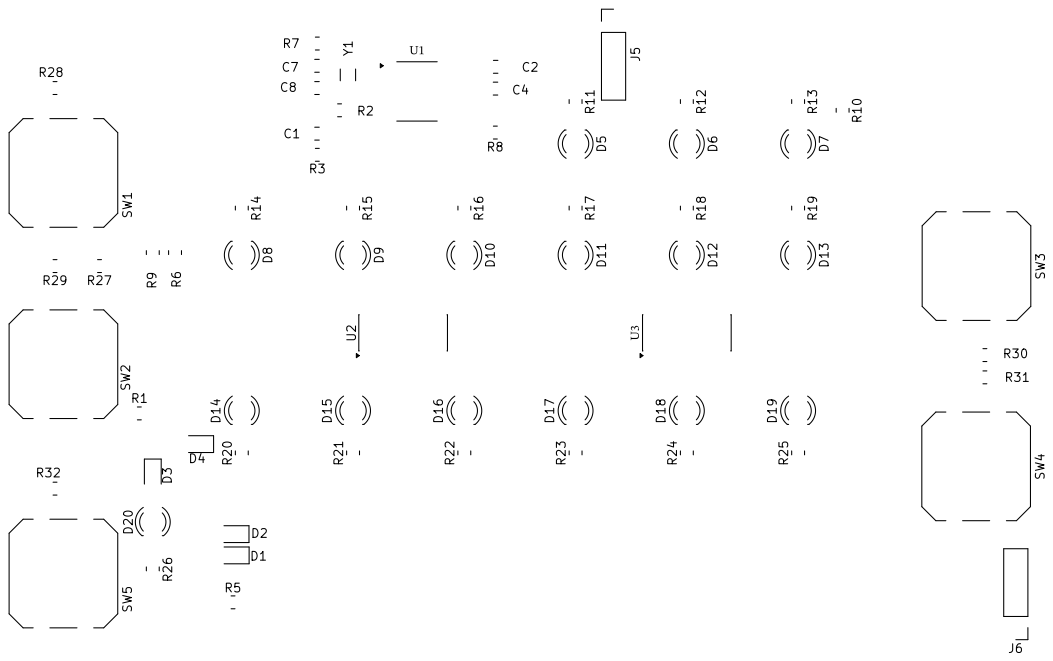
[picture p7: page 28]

J2 C3 J7 BT1 +

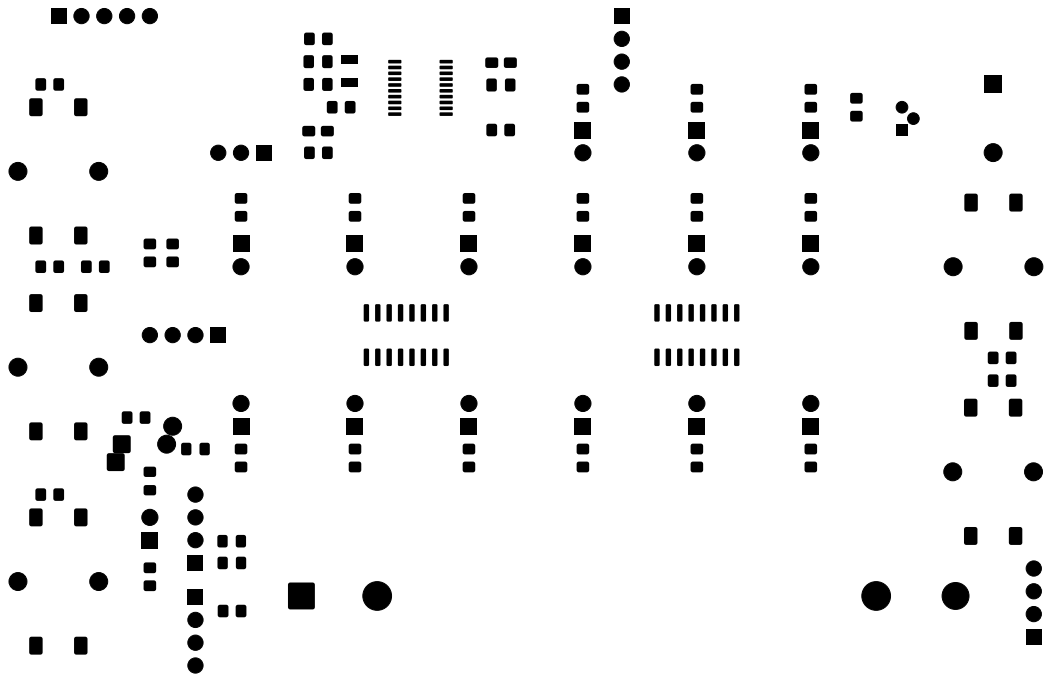
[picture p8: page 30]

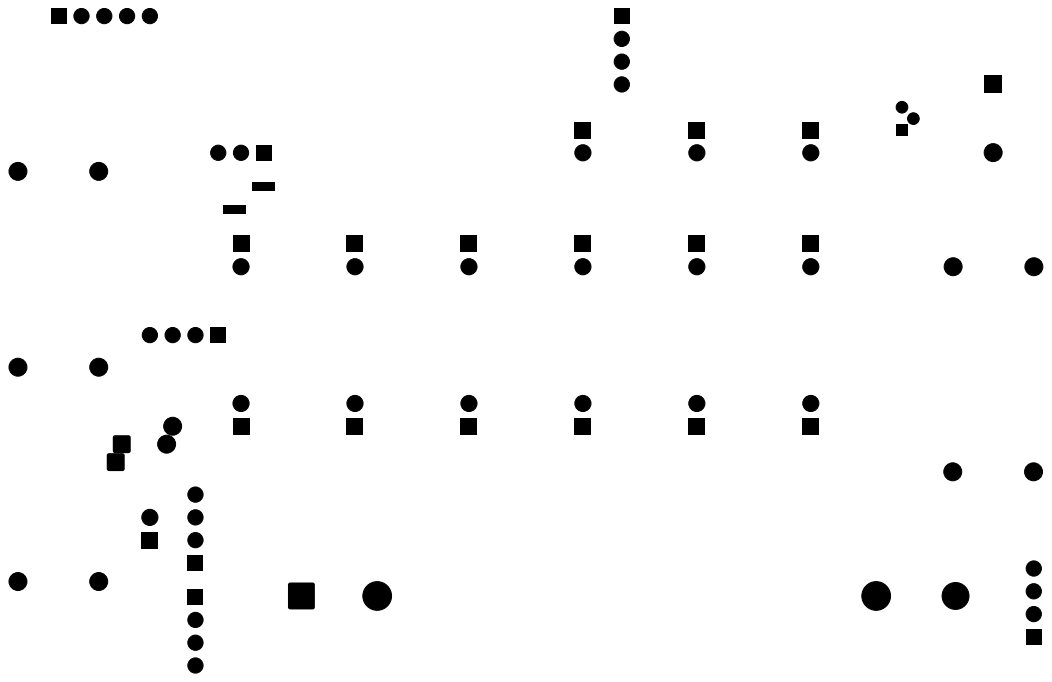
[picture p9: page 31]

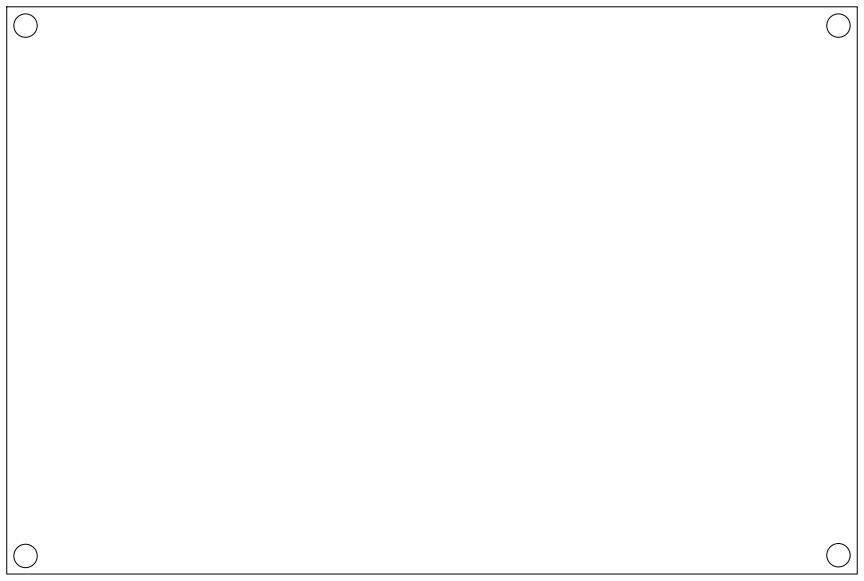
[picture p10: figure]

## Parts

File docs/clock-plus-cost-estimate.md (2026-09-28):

# Орієнтовна собівартість Clock Plus

Оцінка складена 28.09.2026 для поточної версії годинника на
STM32L010F4P6 з PCB 120 x 80 mm, LED-дисплеєм на двох 74HC595, OLED,
AHT10, BH1750, PIR, активним buzzer і живленням від одного акумулятора
18650.

Це роздрібна прототипна оцінка в гривнях. Доставка з різних магазинів,
паяння, складання, програмування, тестування та вартість зарядного кабелю
не враховані.

## Комплектуючі на один годинник

| Позиція | Кількість | Орієнтир за одиницю, грн | Сума, грн | Примітка |
| --- | ---: | ---: | ---: | --- |
| PCB, FR4, 2 шари, 120 x 80 mm | 1 | 450 | 450 | Локальне одиничне/мінімальне замовлення |
| STM32L010F4P6, TSSOP-20 | 1 | 59 | 59 | Основний MCU |
| 74HC595, SOIC-16 | 2 | 12 | 24 | Керування 16-бітним LED-дисплеєм |
| OLED 0.91 inch, 128x32, I2C | 1 | 154 | 154 | Текстовий дисплей |
| AHT10 module | 1 | 80 | 80 | Температура та вологість |
| GY-302/BH1750 module | 1 | 66 | 66 | Освітленість та автояскравість |
| PIR AM312/HC-SR312 | 1 | 52 | 52 | Датчик руху |
| Li-ion 18650, 2000-2600 mAh | 1 | 105 | 105 | Без окремого захисту; захист дає BMS |
| TP4056 Type-C із захистом 1S | 1 | 15 | 15 | Заряд і BMS акумулятора |
| Buck-boost 1.8-5 V to 3.3 V | 1 | 25 | 25 | Стабілізація живлення від 18650 |
| Світлодіоди 5 mm | 17 | 2 | 34 | 16 індикаторів плюс alarm/status LED |
| Кнопки | 5 | 5 | 25 | MODE, SET, UP, DOWN, OFF |
| Активний buzzer, 2N2222 та base resistor | 1 комплект | 20 | 20 | Звуковий сигнал |
| Кварц 32.768 kHz та два конденсатори 15 pF | 1 комплект | 20 | 20 | LSE для RTC |
| Резистори, конденсатори та діоди | 1 комплект | 50 | 50 | LED resistors, I2C pull-ups, dividers, decoupling, power isolation |
| Роз'єми, SWD header, тримач 18650, вимикач і провід | 1 комплект | 45 | 45 | Монтажна дрібнота |
| Резервний полярний конденсатор C3 | 1 | 35 | 35 | Значення ще треба остаточно зафіксувати в BOM |
| Корпус | 1 | 50 | 50 | Задана вартість виготовлення |
| **Разом, один прототип** |  |  | **1309 грн** | Без доставки та роботи |

Розумний резерв на розкид цін, брак і дрібні невраховані матеріали становить
приблизно 10%. Тому практичний бюджет одного прототипу: **близько 1450 грн**.

## Мала партія

Якщо PCB замовляти партією та отримати приблизну ціну **150 грн за плату**,
електроніка й корпус одного годинника коштуватимуть близько **1009 грн**, або
приблизно **1110 грн з резервом 10%**. Гуртові ціни на MCU, сенсори, LED та
74HC595 можуть додатково зменшити цю суму.

## Найбільші статті витрат

1. Одиничне виготовлення PCB: 450 грн.
2. OLED: 154 грн.
3. Акумулятор 18650: 105 грн.
4. AHT10 і BH1750 разом: 146 грн.
5. MCU: 59 грн.

Без OLED та I2C-сенсорів спрощена версія могла б бути дешевшою приблизно на
300 грн, не враховуючи можливе здешевлення самої PCB.

## Джерела цін

- [STM32L010F4P6, 59 грн](https://arduino.ua/prod4934-mikrokontroller-stm32l010f4p6)
- [74HC595, типові роздрібні пропозиції](https://prom.ua/ua/Mikroshema-74hc595.html)
- [OLED 0.91 inch 128x32, 154 грн](https://rozetka.com.ua/ua/285928023/p285928023/)
- [AHT10, 80.23 грн](https://www.k206.net/ua/catalog/1173/22871/)
- [GY-302/BH1750, 66 грн](https://arduino.ua/prod1116-datchik-osveshhennosti-cifrovoi-bh1750fvi)
- [AM312 PIR, 52.40 грн](https://radiostore.com.ua/ua/p1187887797-mini-piroelektricheskij-infrakrasnyj.html)
- [TP4056 Type-C із захистом, 15 грн](https://arduino.ua/prod4517-zaryadnii-modyl-tp4056-type-c-s-fynkciei-zashhiti-akkymylyatora)
- [18650 Quantum 2000 mAh, 105 грн](https://batterex.com.ua/rechargeable-batteries-ua/18650_batteries-ua/18650-quantum-ua/18650-quantum-icr18650-2000mah-button-top-ua)
- [Buck-boost 1.8-5 V to 3.3 V, 25 грн](https://shafa.ua/uk/building/biznes-obladnannya/152335251-miniperetvoryuvach-n1if-dc-18-5v-do-33-v)
- [5 mm blue LED, 2 грн](https://arduino.ua/prod5700-svetodiod-5mm-sinii)
- [Локальне виготовлення двошарової PCB](https://craft-electronics.com.ua/ua/p869869376-izgotovlenie-pechatnyh-plat.html)

Ціни є орієнтирами для попереднього планування, а не остаточною закупівельною
специфікацією. Перед серійним замовленням потрібно зафіксувати точні part
numbers для D1-D4, C3, buck-boost module, buzzer і механічних компонентів.

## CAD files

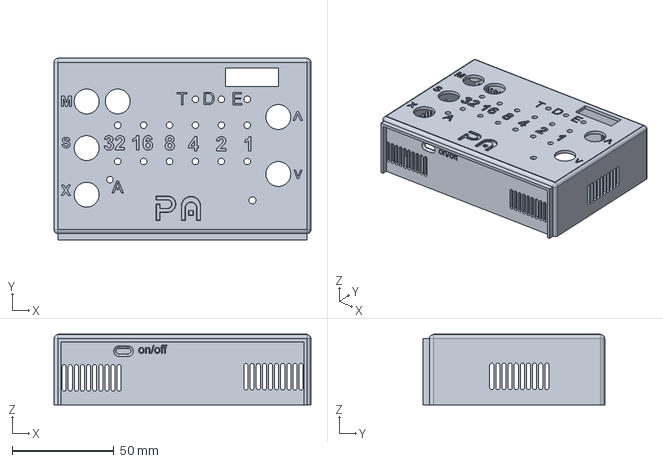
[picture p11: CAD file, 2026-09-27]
Case/CASE-v0_1.1.FCStd
126.0 x 89.0 x 34.8 mm

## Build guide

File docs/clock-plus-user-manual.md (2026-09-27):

# Clock Plus

Посібник користувача для версії пристрою **Clock Plus Premium**.

Ця версія годинника має годинник реального часу з резервним живленням, OLED-екран 128x32, основний бінарний LED-індикатор, датчики температури, вологості, освітленості та руху, активний бузер і контроль заряду акумулятора.

Вайрфрейм нижче зроблено за наданою фотографією корпусу. Він показує органи керування та зони індикації; конкретна механіка корпусу може трохи відрізнятися.

Clock Plus front panel wireframe

## 1. Призначення пристрою

Clock Plus показує час, дату, температуру, вологість, заряд акумулятора і стан будильників. Пристрій уміє автоматично перемикати режими показу, регулювати яскравість LED-індикатора за рівнем освітленості, вимикати периферію за відсутності руху та зберігати хід годинника при зникненні основного живлення.

Основні функції:

- годинник реального часу зі збереженням ходу при резервному живленні;
- дата з урахуванням місяця та високосного року в діапазоні 2000-2099;
- три незалежні будильники;
- OLED-дублювання даних у текстовому вигляді;
- бінарна LED-індикація значень;
- автоматична яскравість LED-індикатора;
- датчик руху для гасіння та пробудження індикації;
- режим низького заряду акумулятора;
- глибокий енергозберігаючий режим при повному зникненні основного живлення.

## 2. Органи керування

На передній панелі використовуються п'ять логічних кнопок:

| Маркування | Назва | Дія |
| --- | --- | --- |
| `M` | MODE | Перемикає екран: час, дата, середовище, будильники, батарея |
| `S` | SET | Входить у налаштування поточного режиму або перемикає поле редагування |
| `▲` | UP | Збільшує значення або вибирає попередній пункт |
| `▼` | DOWN | Зменшує значення або вибирає наступний пункт |
| `X` | OFF / EXIT | Вихід із налаштування, зупинка будильника, перемикання будильника on/off |

Якщо будильник зараз пищить, будь-яка кнопка лише вимикає звук. Вона не виконує свою звичайну дію, поки сигнал будильника активний.

Довге утримання `OFF / EXIT` у режимі будильників перемикає всі налаштовані будильники одразу: якщо хоча б один увімкнений, усі налаштовані будуть вимкнені; якщо всі вимкнені, усі налаштовані будуть увімкнені.

## 3. Екрани та режими

Кнопка `MODE` перемикає ручні режими по колу:

`Time -> Date -> Environment -> Alarm -> Battery -> Time`

Автоматичний цикл показу працює тільки для основних інформаційних екранів:

`Time -> Date -> Environment -> Time`

Тривалість автоматичного показу:

| Екран | Тривалість |
| --- | --- |
| Time | 15 секунд |
| Date | 5 секунд |
| Environment | 5 секунд |

Після натискання будь-якої кнопки автоматичний цикл ставиться на паузу на 30 секунд. Якщо кнопку тримають довго, 30 секунд рахуються після відпускання. Коли пауза закінчиться, пристрій переходить до наступного екрана автоматичного циклу.

Якщо пристрій перебуває в режимі налаштування, через 1 хвилину без дій він виходить із налаштування так само, як при натисканні `OFF / EXIT`.

## 4. Основна LED-індикація

Основний LED-індикатор складається з двох рядів по 6 значущих світлодіодів:

`32 16 8 4 2 1`

Значення читається як сума світлодіодів, що горять. Наприклад:

- горять `16 + 8 + 2 + 1` = 27;
- горять `32 + 16 + 1` = 49;
- нічого не горить = 0.

У звичайному режимі:

- верхній ряд найчастіше показує години, місяць або температуру;
- нижній ряд найчастіше показує хвилини, день, вологість або заряд.

Додаткові індикатори режимів:

| Індикатор | Значення |
| --- | --- |
| `T` | екран часу |
| `D` | екран дати |
| `E` | екран температури/вологості |
| `A` | екран будильників; також загальна ознака ввімкненого будильника |

Якщо є хоча б один увімкнений будильник, індикатор `A` горить у будь-якому режимі. При низькому заряді акумулятора останній/червоний alarm LED використовується як попереджувальний миготливий індикатор.

## 5. OLED-екран

OLED показує ту саму інформацію в читабельному текстовому вигляді:

- час: `HH:MM:SS`;
- дата: `DD.MM.YY`;
- середовище: температура і вологість;
- будильники: список або вибраний слот;
- батарея: відсоток і нижня смуга заряду.

Маленька літера `A` у нижньому правому куті головного екрана означає, що ввімкнений хоча б один будильник.

Коли спрацьовує будильник, OLED один раз показує `ALARM 1`, `ALARM 2` або `ALARM 3` і не перемальовує звичайні екрани, поки сигнал не вимкнений або не закінчився за таймаутом.

## 6. Екран часу

У режимі часу:

- OLED показує `HH:MM:SS`;
- верхній LED-ряд показує години;
- нижній LED-ряд показує хвилини;
- індикатор `T` показує режим часу.

### Налаштування часу

1. Натисніть `MODE`, поки не відкриється екран часу.
2. Натисніть `SET`.
3. Кнопками `UP` і `DOWN` змінюйте вибране поле.
4. Натискайте `SET`, щоб перемикатися між хвилинами та годинами.
5. Натисніть `OFF / EXIT`, щоб вийти з налаштування.

Під час налаштування:

- індикатор `T` блимає;
- світиться тільки той LED-ряд, який зараз редагується;
- при редагуванні годин світиться верхній ряд;
- при редагуванні хвилин світиться нижній ряд;
- на OLED дві точки показують редаговане поле.

## 7. Екран дати

У режимі дати:

- OLED показує `DD.MM.YY`;
- верхній LED-ряд показує місяць;
- нижній LED-ряд показує день;
- індикатор `D` показує режим дати.

Рік задається як `00..99` і означає `2000..2099`. Наприклад, `26` означає 2026 рік. Правильний рік потрібен для коректного розрахунку 28/29 лютого та переходів 30/31 день.

### Налаштування дати

1. Натисніть `MODE`, поки не відкриється екран дати.
2. Натисніть `SET`.
3. Кнопками `UP` і `DOWN` змінюйте вибране поле.
4. Натискайте `SET`, щоб перемикатися по циклу: день -> місяць -> рік -> день.
5. Натисніть `OFF / EXIT`, щоб вийти.

Під час налаштування:

- індикатор `D` блимає;
- при редагуванні дня світиться нижній ряд;
- при редагуванні місяця світиться верхній ряд;
- при редагуванні року верхній ряд показує `20`, нижній ряд показує останні дві цифри року;
- на OLED дві точки показують редаговане поле.

## 8. Екран середовища

Екран середовища показує температуру і вологість із вбудованого датчика.

На OLED відображаються текстові значення температури та вологості.

На LED-індикаторі:

- верхній ряд показує температуру в градусах Цельсія бінарним числом;
- нижній ряд показує вологість шкалою.

Шкала вологості на нижньому ряду:

| Вологість | LED-шкала |
| --- | --- |
| нижче 30% | 0 світлодіодів |
| близько 40% | 1 світлодіод |
| близько 50% | 2 світлодіоди |
| близько 60% | 3 світлодіоди |
| близько 70% | 4 світлодіоди |
| близько 80% | 5 світлодіодів |
| 90% і вище | 6 світлодіодів |

Температура/вологість опитуються приблизно раз на 15 секунд, щоб не гальмувати кнопки та відрисовку.

## 9. Екран будильників

Пристрій підтримує три будильники: `A1`, `A2`, `A3`.

Будильники зберігаються в backup-регістрах RTC. При зникненні основного живлення вони зберігаються, якщо RTC-домен продовжує живитися від резервної лінії/іоністора.

### Перегляд будильників

1. Натисніть `MODE`, поки не відкриється екран будильників.
2. При вході вибирається `A1`.
3. `DOWN` перемикає вибір: `A1 -> A2 -> A3 -> A1`.
4. `UP` перемикає вибір назад: `A1 -> A3 -> A2 -> A1`.

На OLED список виглядає так:

```text
*A1 17:20 ON
-A2 12:20 OFF
-A3 --:-- OFF
```

`*` означає вибраний слот. `-` означає невибраний слот. `--:--` означає, що час будильника ще не задано.

На LED-індикаторі:

- ряди показують час вибраного будильника;
- окремий status LED горить, якщо вибраний будильник увімкнений;
- два LED номера показують вибраний слот бінарно: `01`, `10`, `11`;
- індикатор режиму `A` показує, що відкрито екран будильників.

### Увімкнення та вимкнення будильника

У режимі перегляду будильників натисніть `OFF / EXIT`:

- якщо вибраний слот налаштований, його статус перемкнеться `ON/OFF`;
- якщо слот порожній, пристрій мигне всіма LED на рядах годин і хвилин як помилкою.

Довге утримання `OFF / EXIT` вмикає або вимикає всі налаштовані будильники одразу.

### Налаштування будильника

1. Відкрийте режим будильників.
2. `UP` або `DOWN` виберіть `A1`, `A2` або `A3`.
3. Натисніть `SET`.
4. `UP` і `DOWN` змінюють вибране поле.
5. `SET` перемикає редагування годин і хвилин.
6. `OFF / EXIT` виходить із редагування назад до списку будильників.

Під час налаштування:

- OLED показує тільки вибраний слот;
- дві точки на OLED стоять над редагованим полем;
- цифри не блимають, щоб не витрачати зайвий час процесора;
- на LED-індикаторі номер вибраного будильника блимає;
- індикатор режиму `A` горить постійно;
- світиться тільки ряд, який редагується: верхній для годин, нижній для хвилин.

Якщо будильник уже спрацьовував сьогодні, але ви переналаштували його час, він знову зможе спрацювати цього ж дня за новим часом.

## 10. Спрацювання будильника

Коли поточний час збігся з увімкненим будильником:

- вмикається активний бузер;
- OLED показує `ALARM n`;
- звичайне оновлення екранів зупиняється до вимкнення будильника;
- будь-яка кнопка вимикає звук і не виконує свою звичайну дію.

Звуковий рисунок: короткі серії `пі-пі-пі`, пауза, знову `пі-пі-пі`.

Якщо живлення просіло, але пристрій ще може працювати, будильник все одно має пріоритет і продовжує пищати. Кнопки залишаються доступними, щоб користувач міг вимкнути сигнал.

Будильник спрацює знову наступного дня, якщо він залишився увімкненим.

## 11. Екран батареї

Екран батареї знаходиться після екрана будильників у ручному циклі `MODE`.

На OLED:

- показується `BAT`;
- показується відсоток заряду;
- внизу малюється смуга заряду.

На LED-індикаторі:

- використовується шкала з 6 світлодіодів нижнього ряду;
- інші значення вимкнені, щоб шкала читалася окремо.

Відсоток розраховується за виміряною напругою акумулятора. Шкала нелінійна і підібрана під реальну криву розряду:

| Напруга акумулятора | Заряд |
| --- | --- |
| 4.10 V і вище | 100% |
| 3.80 V | 90% |
| 3.70 V | 82% |
| 3.60 V | 73% |
| 3.50 V | 62% |
| 3.40 V | 50% |
| 3.30 V | 36% |
| 3.20 V | 22% |
| 3.10 V | 10% |
| 2.90 V | 0% |

Якщо батарея падає нижче аварійного порогу, пристрій вимикає зовнішню периферію і блимає alarm LED. Зворотне ввімкнення нормальної індикації відбувається після відновлення напруги вище порогу повернення.

## 12. Автоматична яскравість

Яскравість основного LED-індикатора регулюється вбудованим датчиком освітленості.

Поточне налаштування:

| Параметр | Значення |
| --- | --- |
| Нижня межа яскравості | близько 2% |
| Верхня межа яскравості | близько 50% |
| Темно | близько 2 lux |
| Яскраво | близько 400 lux |
| Кількість рівнів | 10 |

Датчик освітленості опитується приблизно раз на 5 секунд. Яскравість OLED регулюється окремо, тому його поведінка може відрізнятися від LED-індикатора.

## 13. Датчик руху та гасіння периферії

Датчик руху визначає присутність людини перед пристроєм.

Якщо немає руху, немає натискань кнопок, немає активного налаштування і немає активного будильника, пристрій чекає один повний автоматичний цикл показу і потім гасить периферію:

- очищає LED-індикатор;
- очищає OLED;
- вимикає бузер;
- припиняє опитування кліматичних датчиків;
- переходить у режим зниженого споживання.

Це легкий енергозберігаючий режим: годинник продовжує реагувати на кнопки, датчик руху, стан живлення і будильник.

Пробудження з цього режиму відбувається від:

- руху перед датчиком;
- натискання будь-якої кнопки;
- активного будильника.

Після пробудження пристрій показує екран часу.

## 14. Поведінка при зникненні живлення

Пристрій окремо контролює наявність основного живлення та рівень заряду акумулятора.

Якщо основне живлення повністю зникло, пристрій:

1. вимикає дисплеї, датчики та іншу зовнішню периферію;
2. перевіряє, що живлення справді відсутнє;
3. переходить у глибокий енергозберігаючий режим;
4. автоматично прокидається після відновлення живлення.

Якщо заряд акумулятора став надто низьким, годинник спочатку вмикає попередження та режим економії. Активний будильник і кнопки вимкнення сигналу залишаються доступними, доки пристрій має достатньо енергії для роботи.

## 15. Як читати значення на LED-індикаторі

Приклад читання часу:

- верхній ряд: горять `8 + 4 + 2` = 14 годин;
- нижній ряд: горять `16 + 8 + 1` = 25 хвилин;
- OLED додатково показує `14:25:xx`.

Приклад читання дати:

- верхній ряд: `8` = 8 місяць;
- нижній ряд: `16 + 8 + 2 + 1` = 27 день;
- OLED показує `27.08.26`.

Приклад читання середовища:

- верхній ряд: `16 + 8 + 2 + 1` = 27 C;
- нижня шкала: 3 світлодіоди = приблизно 60% вологості.

## 16. Швидка пам'ятка

| Що треба зробити | Дія |
| --- | --- |
| Подивитися наступний екран | `MODE` |
| Налаштувати час | `MODE` до часу, потім `SET` |
| Налаштувати дату | `MODE` до дати, потім `SET` |
| Подивитися будильники | `MODE` до alarm |
| Вибрати будильник | `UP` або `DOWN` в alarm |
| Налаштувати вибраний будильник | `SET` в alarm |
| Увімкнути/вимкнути вибраний будильник | `OFF / EXIT` в alarm без редагування |
| Увімкнути/вимкнути всі налаштовані будильники | Довге утримання `OFF / EXIT` в alarm |
| Зупинити будильник, що спрацював | Будь-яка кнопка |
| Вийти з налаштування | `OFF / EXIT` |
| Подивитися заряд | `MODE` до battery |

## 17. Що вважається нормальною поведінкою

- OLED може оновлюватися не миттєво: відрисовка розбита на маленькі операції, щоб кнопки і будильник не зависали.
- Температура і вологість оновлюються рідко, приблизно раз на 15 секунд.
- Освітленість оновлюється приблизно раз на 5 секунд.
- Після бездіяльності екран може погаснути; це нормальний режим економії.
- При русі або натисканні кнопки пристрій повертається до екрана часу.
- При низькій батареї пристрій може погасити основну індикацію і залишити попереджувальне миготіння.

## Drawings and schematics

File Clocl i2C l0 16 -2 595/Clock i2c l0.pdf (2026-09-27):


Size: A4 | Rev:
KiCad E.D.A. 10.0.3 | Id: 1/1

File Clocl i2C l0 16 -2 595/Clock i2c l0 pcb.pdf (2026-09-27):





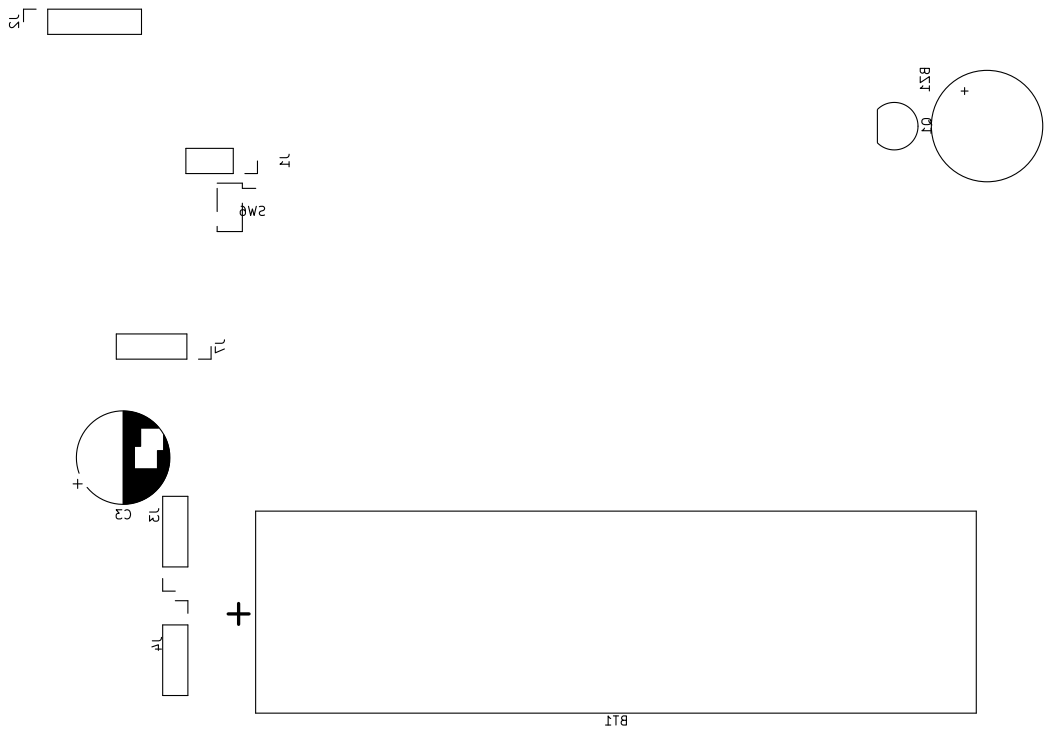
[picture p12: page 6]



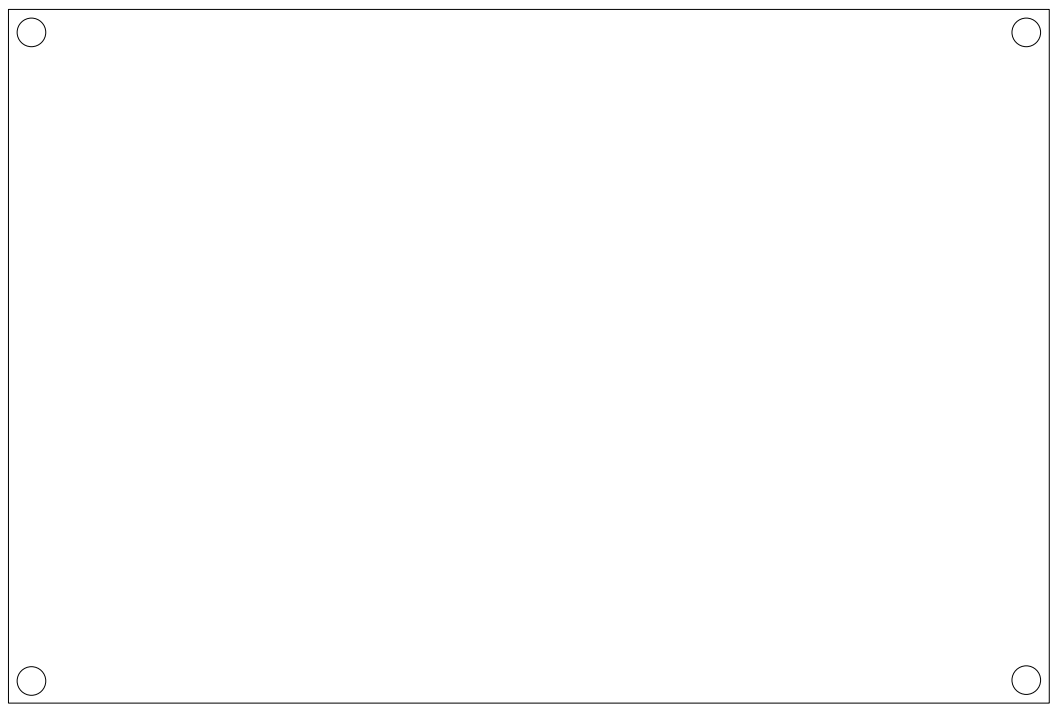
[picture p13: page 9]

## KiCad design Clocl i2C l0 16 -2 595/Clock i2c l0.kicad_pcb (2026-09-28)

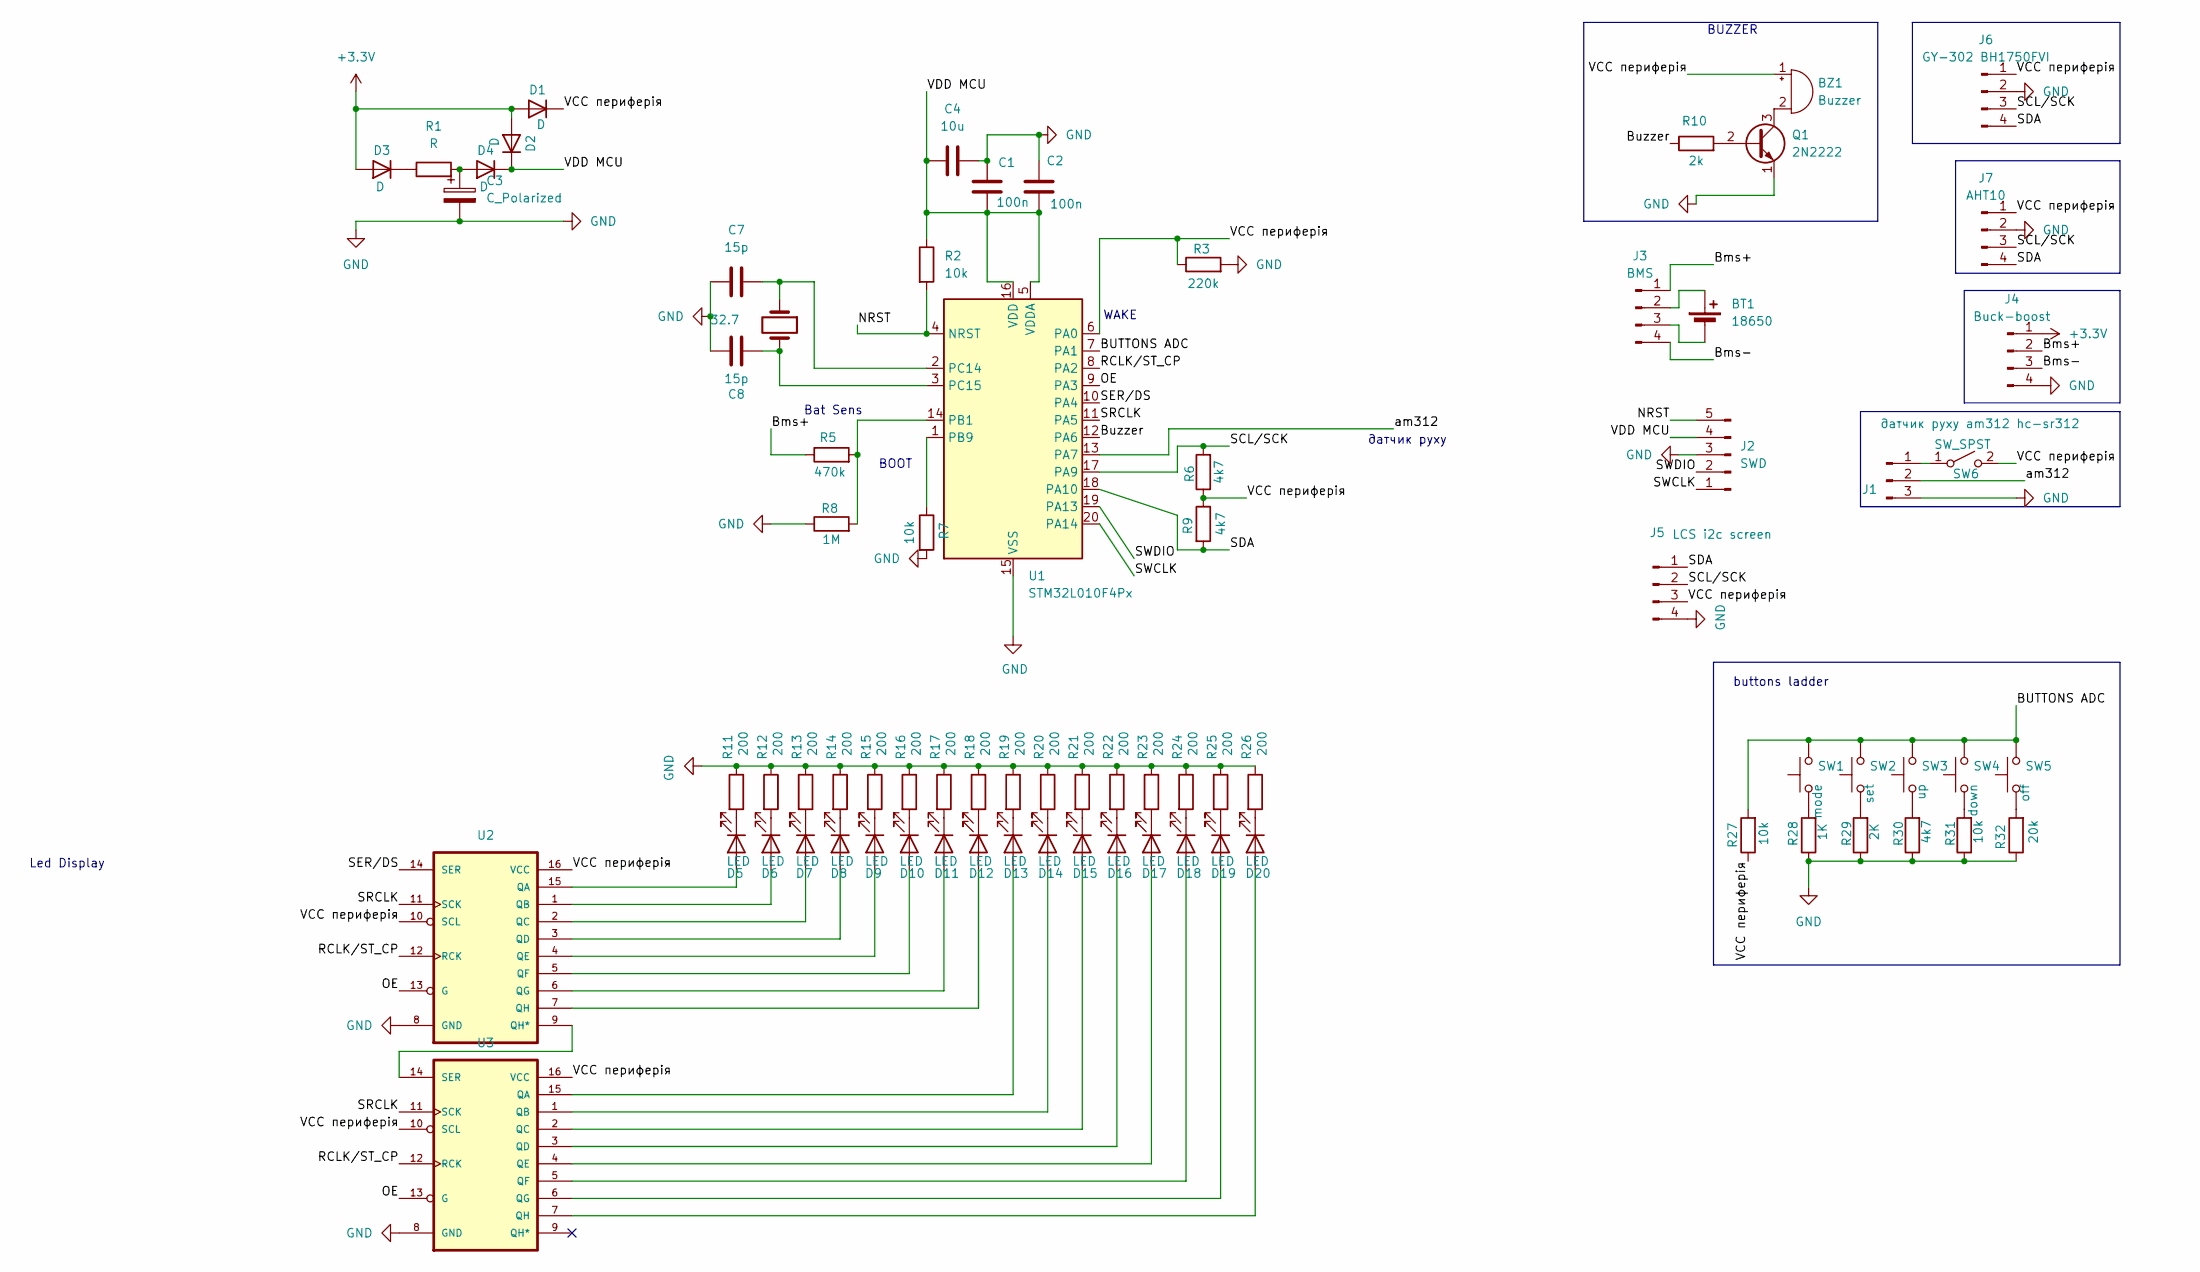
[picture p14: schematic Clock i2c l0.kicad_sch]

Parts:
BT1: 18650; BatteryHolder_MPD_BH-18650-PC
BZ1: Buzzer; Buzzer_12x9.5RM7.6
C1, C2: 100n; C_0805_2012Metric_Pad1.18x1.45mm_HandSolder
C3: C_Polarized; CP_Radial_D10.0mm_P5.00mm_P7.50mm
C4: 10u; C_0805_2012Metric_Pad1.18x1.45mm_HandSolder
C7, C8: 15p; C_0805_2012Metric_Pad1.18x1.45mm_HandSolder
D1, D2, D3, D4: D; D_0805_2012Metric_Pad1.15x1.40mm_HandSolder
D5, D6, D7, D8, D9, D10, D11, D12, D13, D14, D15, D16, D17, D18, D19, D20: LED; LED_D3.0mm
J1: датчик руху am312 hc-sr312; PinHeader_1x03_P2.54mm_Vertical
J2: SWD; PinHeader_1x05_P2.54mm_Vertical
J3: BMS; PinHeader_1x04_P2.54mm_Vertical
J4: Buck-boost; PinHeader_1x04_P2.54mm_Vertical
J5: LCS i2c screen; PinHeader_1x04_P2.54mm_Vertical
J6: GY-302 BH1750FVI; PinHeader_1x04_P2.54mm_Vertical
J7: AHT10; PinHeader_1x04_P2.54mm_Vertical
Q1: 2N2222; TO-92
R1: R; R_0805_2012Metric_Pad1.20x1.40mm_HandSolder
R2, R7, R27, R31: 10k; R_0805_2012Metric_Pad1.20x1.40mm_HandSolder
R3: 220k; R_0805_2012Metric_Pad1.20x1.40mm_HandSolder
R5: 470k; R_0805_2012Metric_Pad1.20x1.40mm_HandSolder
R6, R9, R30: 4k7; R_0805_2012Metric_Pad1.20x1.40mm_HandSolder
R8: 1M; R_0805_2012Metric_Pad1.20x1.40mm_HandSolder
R10: 2k; R_0805_2012Metric_Pad1.20x1.40mm_HandSolder
R11, R12, R13, R14, R15, R16, R17, R18, R19, R20, R21, R22, R23, R24, R25, R26: 200; R_0805_2012Metric_Pad1.20x1.40mm_HandSolder
R28: 1K; R_0805_2012Metric_Pad1.20x1.40mm_HandSolder
R29: 2K; R_0805_2012Metric_Pad1.20x1.40mm_HandSolder
R32: 20k; R_0805_2012Metric_Pad1.20x1.40mm_HandSolder
SW1: mode; SW_Push_1P1T_NO_CK_PTS125Sx73PSMTR
SW2: set; SW_Push_1P1T_NO_CK_PTS125Sx73PSMTR
SW3: up; SW_Push_1P1T_NO_CK_PTS125Sx73PSMTR
SW4: down; SW_Push_1P1T_NO_CK_PTS125Sx73PSMTR
SW5: off; SW_Push_1P1T_NO_CK_PTS125Sx73PSMTR
SW6: SW_SPST; PinHeader_1x02_P2.54mm_Vertical_SMD_Pin1Left
U1: STM32L010F4Px; TSSOP-20_4.4x6.5mm_P0.65mm
U2, U3: 74HC595N-DIP16; SOIC-16_3.9x9.9mm_P1.27mm; MPN 74HC595N
Y1: 32.7; Crystal_SMD_3215-2Pin_3.2x1.5mm

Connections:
+3.3V: D1.2 (A), D2.2 (A), D3.2 (A), J4.1
/BUTTONS ADC: R27.2, SW1.2, SW2.2, SW3.2, SW4.2, SW5.2, U1.7 (PA1)
/Bms+: J3.1, J4.2, R5.1
/Bms-: J3.4, J4.3
/Buzzer: R10.1, U1.12 (PA6)
/NRST: J2.5, R2.2, U1.4 (NRST)
/OE: U1.9 (PA3), U2.13 (G), U3.13 (G)
/RCLK/ST_CP: U1.8 (PA2), U2.12 (RCK), U3.12 (RCK)
/SCL/SCK: J5.2, J6.3, J7.3, R6.2, U1.17 (PA9)
/SDA: J5.1, J6.4, J7.4, R9.2, U1.18 (PA10)
/SER/DS: U1.10 (PA4), U2.14 (SER)
/SRCLK: U1.11 (PA5), U2.11 (SCK), U3.11 (SCK)
/SWCLK: J2.1, U1.20 (PA14)
/SWDIO: J2.2, U1.19 (PA13)
/VCC периферія: BZ1.1 (+), D1.1 (K), J5.3, J6.1, J7.1, R3.1, R6.1, R9.1, R27.1, SW6.2 (B), U1.6 (PA0), U2.10 (SCL), U2.16 (VCC), U3.10 (SCL), U3.16 (VCC)
/VDD MCU: C1.2, C2.2, C4.1, D2.1 (K), D4.1 (K), J2.4, R2.1, U1.5 (VDDA), U1.16 (VDD)
/am312: J1.2, U1.13 (PA7)
GND: C1.1, C2.1, C3.2, C4.2, C7.1, C8.1, J1.3, J2.3, J4.4, J5.4, J6.2, J7.2, Q1.1 (E), R3.2, R7.2, R8.1, R11.1, R12.1, R13.1, R14.1, R15.1, R16.1, R17.1, R18.1, R19.1, R20.1, R21.1, R22.1, R23.1, R24.1, R25.1, R26.1, R28.1, R29.1, R30.1, R31.1, R32.1, U1.15 (VSS), U2.8 (GND), U3.8 (GND)
unnamed: BT1.1 (+), J3.2
unnamed: BT1.2 (-), J3.3
unnamed: BZ1.2 (-), Q1.3 (C)
unnamed: D3.1 (K), R1.1
unnamed: C3.1, D4.2 (A), R1.2
unnamed: D5.2 (A), U2.15 (QA)
unnamed: D5.1 (K), R11.2
unnamed: D6.2 (A), U2.1 (QB)
unnamed: D6.1 (K), R12.2
unnamed: D7.2 (A), U2.2 (QC)
unnamed: D7.1 (K), R13.2
unnamed: D8.2 (A), U2.3 (QD)
unnamed: D8.1 (K), R14.2
unnamed: D9.2 (A), U2.4 (QE)
unnamed: D9.1 (K), R15.2
unnamed: D10.2 (A), U2.5 (QF)
unnamed: D10.1 (K), R16.2
unnamed: D11.2 (A), U2.6 (QG)
unnamed: D11.1 (K), R17.2
unnamed: D12.2 (A), U2.7 (QH)
unnamed: D12.1 (K), R18.2
unnamed: D13.2 (A), U3.15 (QA)
unnamed: D13.1 (K), R19.2
unnamed: D14.2 (A), U3.1 (QB)
unnamed: D14.1 (K), R20.2
unnamed: D15.2 (A), U3.2 (QC)
unnamed: D15.1 (K), R21.2
unnamed: D16.2 (A), U3.3 (QD)
unnamed: D16.1 (K), R22.2
unnamed: D17.2 (A), U3.4 (QE)
unnamed: D17.1 (K), R23.2
unnamed: D18.2 (A), U3.5 (QF)
unnamed: D18.1 (K), R24.2
unnamed: D19.2 (A), U3.6 (QG)
unnamed: D19.1 (K), R25.2
unnamed: D20.2 (A), U3.7 (QH)
unnamed: D20.1 (K), R26.2
unnamed: J1.1, SW6.1 (A)
unnamed: Q1.2 (B), R10.2
unnamed: R28.2, SW1.1
unnamed: R29.2, SW2.1
unnamed: R30.2, SW3.1
unnamed: R31.2, SW4.1
unnamed: R32.2, SW5.1
unnamed: R5.2, R8.2, U1.14 (PB1)
unnamed: R7.1, U1.1 (PB9)
unnamed: C7.2, U1.2 (PC14), Y1.1
unnamed: C8.2, U1.3 (PC15), Y1.2
unnamed: U2.9 (QH*), U3.14 (SER)

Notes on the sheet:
датчик руху
WAKE
Bat Sens
buttons ladder
BOOT
Led Display
BUZZER

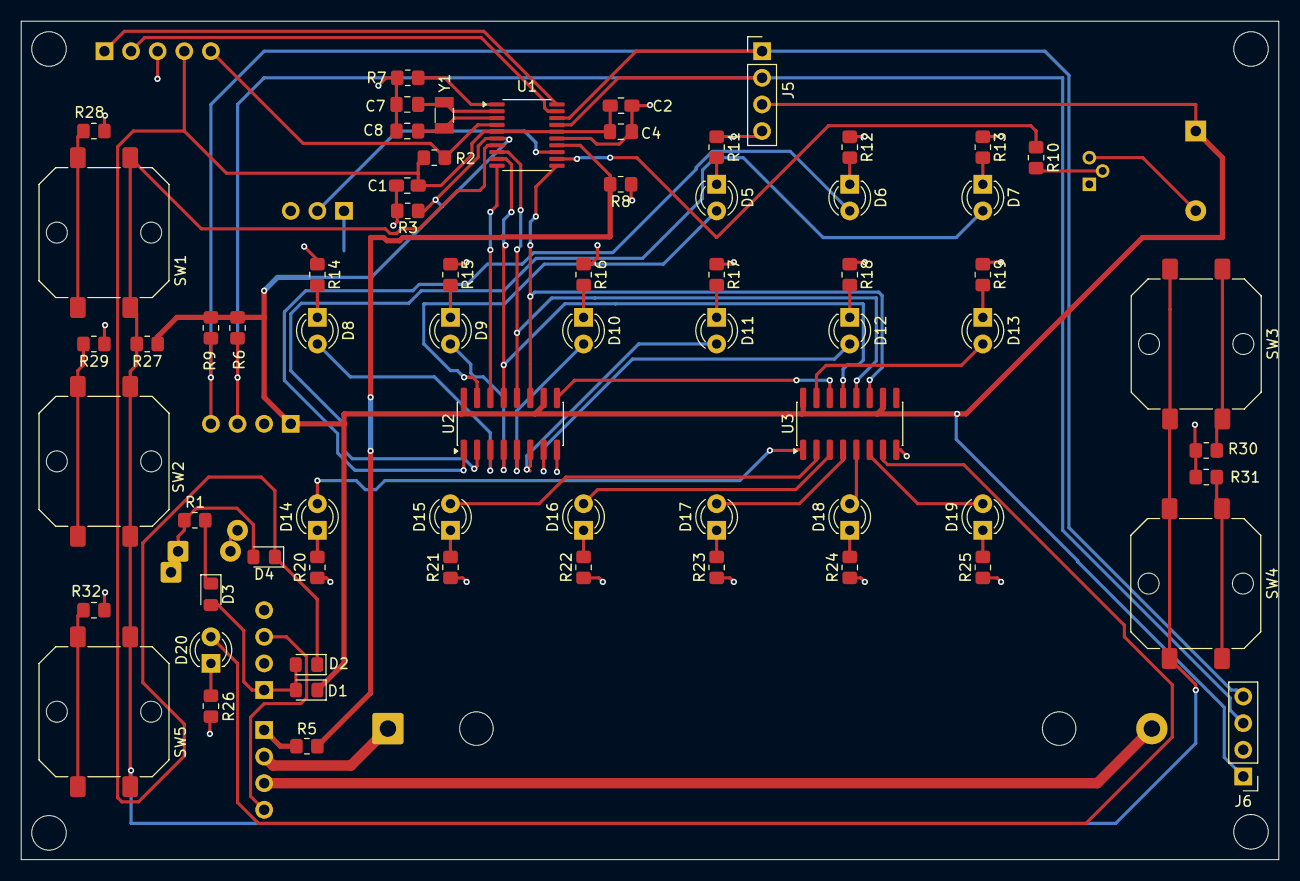
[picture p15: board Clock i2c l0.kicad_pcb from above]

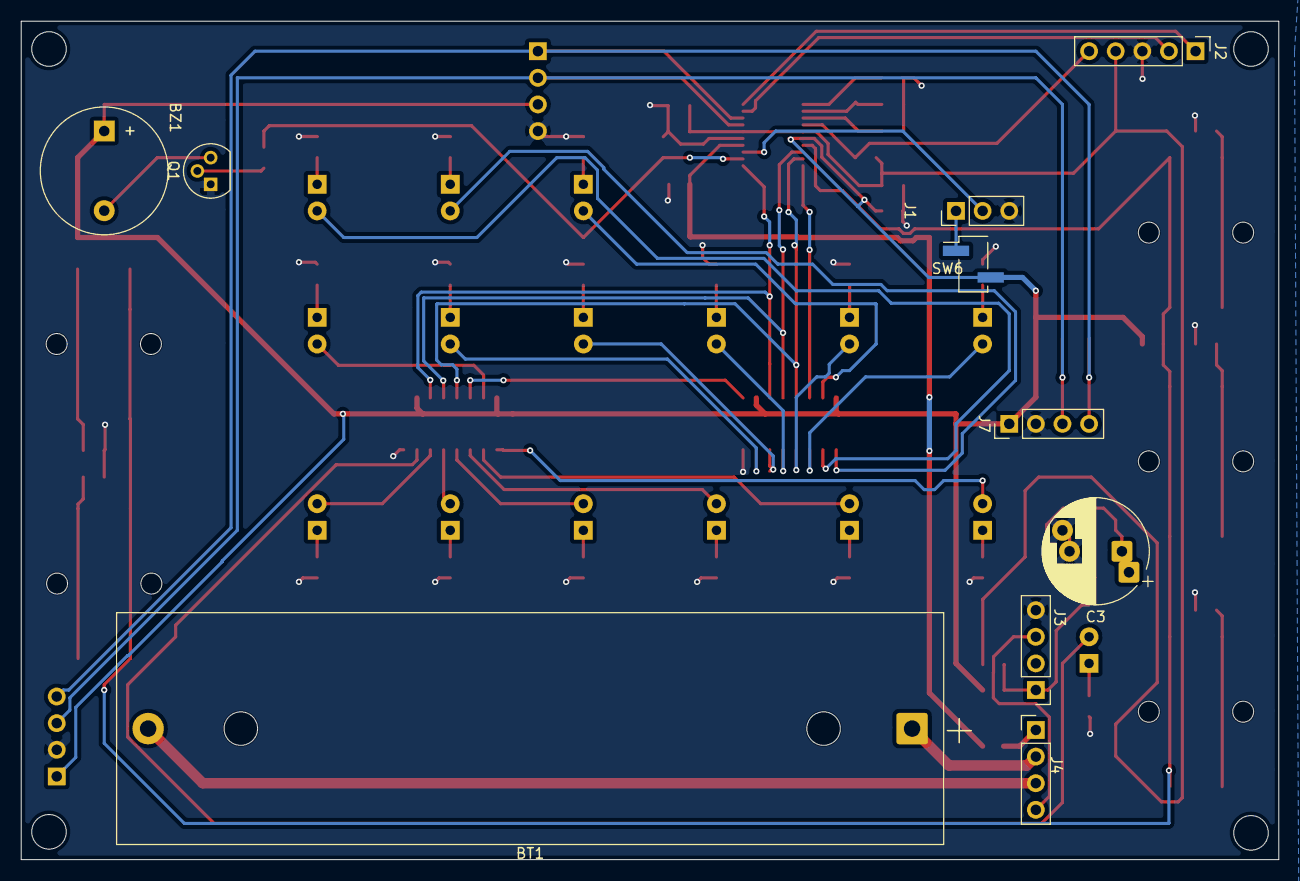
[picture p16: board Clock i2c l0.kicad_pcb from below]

Board: 2 copper layers, 120.0 x 80.0 mm, 77 parts (10 on the bottom side), 67 nets.

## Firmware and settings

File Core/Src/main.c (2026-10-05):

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
/* Includes ------------------------------------------------------------------*/
#include "main.h"

/* USER CODE BEGIN Includes */
#include "alarm_manager.h"
#include "board.h"
#include "display_renderer.h"
#include "environment_manager.h"
#include "oled_128x32.h"
#include "ui_controller.h"

/* USER CODE END Includes */

/* USER CODE BEGIN PD */
#define MAIN_LOOP_DELAY_MS 20U
#define IDLE_LOOP_DELAY_MS 100U
#define APP_SLEEP_TIMEBASE_HZ 32768U
#define APP_SLEEP_TIMER_SYNC_TIMEOUT 10000U
#define RTC_REFRESH_INTERVAL_MS 1000U
#define BLINK_INTERVAL_MS 800U
#define MAIN_POWER_STANDBY_ENABLED 1U
#define IDLE_AUTO_MODE_TIME_SEEN 0x01U
#define IDLE_AUTO_MODE_DATE_SEEN 0x02U
#define IDLE_AUTO_MODE_ENVIRONMENT_SEEN 0x04U
#define IDLE_AUTO_MODE_ALL_SEEN \
  (IDLE_AUTO_MODE_TIME_SEEN | IDLE_AUTO_MODE_DATE_SEEN | \
   IDLE_AUTO_MODE_ENVIRONMENT_SEEN)
#define LOW_BATTERY_BLINK_INTERVAL_MS 1000U
#define APP_MSI_ACTIVE_RANGE RCC_ICSCR_MSIRANGE_6
#define APP_MSI_ACTIVE_HZ 4194304UL
#define APP_MSI_IDLE_RANGE RCC_ICSCR_MSIRANGE_5
#define APP_MSI_IDLE_HZ 2097152UL

/* USER CODE END PD */

/* USER CODE BEGIN PV */
RTC_HandleTypeDef hrtc;
static uint32_t appLastLoopTick = 0U;
static uint32_t appLoopIntervalMs = MAIN_LOOP_DELAY_MS;

/* USER CODE END PV */

void SystemClock_Config(void);
static void MX_GPIO_Init(void);
static void MX_ADC_Init(void);
/* USER CODE BEGIN PFP */
static uint8_t App_RTC_Init(void);
static uint8_t App_Tick(void);
static void App_SetMsiClock(uint32_t msiRange, uint32_t coreClockHz);
static void App_SleepUntilNextTick(void);

/* USER CODE END PFP */

/**
  * @brief  The application entry point.
  * @retval int
  */
int main(void)
{

  /* MCU Configuration--------------------------------------------------------*/

  /* Reset of all peripherals, Initializes the Flash interface and the Systick. */
  if (HAL_InitTick(TICK_INT_PRIORITY) != HAL_OK)
  {
    Error_Handler();
  }
  HAL_MspInit();

  /* Configure the system clock */
  SystemClock_Config();

  /* Initialize all configured peripherals */
  MX_GPIO_Init();
  MX_ADC_Init();
  /* USER CODE BEGIN 2 */
  (void)App_RTC_Init();
  Board_Init();
  Oled128x32_Init();

  UiController_Init();
  AlarmManager_Init();
  EnvironmentManager_Init();

  /* USER CODE END 2 */

  /* Infinite loop */
  /* USER CODE BEGIN WHILE */
  while (1)
  {
    (void)App_Tick();
    App_SleepUntilNextTick();

    /* USER CODE END WHILE */

    /* USER CODE BEGIN 3 */
  }
  /* USER CODE END 3 */
}

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
/* USER CODE BEGIN 4 */
HAL_StatusTypeDef HAL_InitTick(uint32_t TickPriority)
{
  if (TickPriority < (1UL << __NVIC_PRIO_BITS)) {
    uwTickPrio = TickPriority;
  }

  SysTick->LOAD = (SystemCoreClock / 1000U) - 1UL;
  SysTick->VAL = 0UL;
  SysTick->CTRL = SysTick_CTRL_CLKSOURCE_Msk | SysTick_CTRL_TICKINT_Msk |
                  SysTick_CTRL_ENABLE_Msk;
  return HAL_OK;
}

static void App_SetMsiClock(uint32_t msiRange, uint32_t coreClockHz)
{
  RCC->CR |= RCC_CR_MSION;
  while ((RCC->CR & RCC_CR_MSIRDY) == 0U) {
  }

  RCC->ICSCR = (RCC->ICSCR & ~RCC_ICSCR_MSIRANGE) | msiRange;
  while ((RCC->CR & RCC_CR_MSIRDY) == 0U) {
  }

  SystemCoreClock = coreClockHz;
  if (HAL_InitTick(TICK_INT_PRIORITY) != HAL_OK) {
    Error_Handler();
  }
}

static uint8_t App_RTC_Init(void)
{
  RCC_OscInitTypeDef RCC_OscInitStruct = {0};

  HAL_PWR_EnableBkUpAccess();

  if (__HAL_RCC_GET_RTC_SOURCE() != RCC_RTCCLKSOURCE_LSE) {
    __HAL_RCC_BACKUPRESET_FORCE();
    __HAL_RCC_BACKUPRESET_RELEASE();
  }

  __HAL_RCC_LSEDRIVE_CONFIG(RCC_LSEDRIVE_HIGH);

  RCC_OscInitStruct.OscillatorType = RCC_OSCILLATORTYPE_LSE;
  RCC_OscInitStruct.LSEState = RCC_LSE_ON;
  if (HAL_RCC_OscConfig(&RCC_OscInitStruct) != HAL_OK)
  {
    return 0U;
  }

  if (__HAL_RCC_GET_FLAG(RCC_FLAG_LSERDY) == RESET) {
    return 0U;
  }

  __HAL_RCC_RTC_CONFIG(RCC_RTCCLKSOURCE_LSE);
  __HAL_RCC_RTC_ENABLE();

  hrtc.Instance = RTC;
  hrtc.Init.HourFormat = RTC_HOURFORMAT_24;
  hrtc.Init.AsynchPrediv = 127;
  hrtc.Init.SynchPrediv = 255;
  hrtc.Init.OutPut = RTC_OUTPUT_DISABLE;
  hrtc.Init.OutPutPolarity = RTC_OUTPUT_POLARITY_HIGH;
  hrtc.Init.OutPutType = RTC_OUTPUT_TYPE_OPENDRAIN;
  if (HAL_RTC_Init(&hrtc) != HAL_OK)
  {
    return 0U;
  }

  return 1U;
}

static void App_SleepUntilNextTick(void)
{
  static uint32_t sleepFraction = 0U;
  uint32_t elapsedMs = HAL_GetTick() - appLastLoopTick;
  uint32_t timerPeriod;
  uint32_t elapsedTimerTicks;
  uint32_t previousCounter;
  uint32_t elapsedUnits;
  uint32_t systickControl;
  uint32_t syncTimeout = APP_SLEEP_TIMER_SYNC_TIMEOUT;

  if (elapsedMs >= appLoopIntervalMs) {
    return;
  }
  if (__HAL_RCC_GET_FLAG(RCC_FLAG_LSERDY) == RESET) {
    /* Keep the 1 ms HAL tick as a safe wake source if the RTC crystal fails. */
    SCB->SCR &= ~(SCB_SCR_SLEEPDEEP_Msk | SCB_SCR_SLEEPONEXIT_Msk);
    __DSB();
    __WFI();
    return;
  }

  __HAL_RCC_LPTIM1_CLK_ENABLE();
  __HAL_RCC_LPTIM1_CLK_SLEEP_ENABLE();
  __HAL_RCC_LPTIM1_CONFIG(RCC_LPTIM1CLKSOURCE_LSE);

  /* WFI also returns for an already pending enabled IRQ with PRIMASK set.
     Keep handlers masked until elapsed time and SysTick have been restored. */
  __disable_irq();
  systickControl = SysTick->CTRL;
  if ((SCB->ICSR & SCB_ICSR_PENDSTSET_Msk) != 0U) {
    SCB->ICSR = SCB_ICSR_PENDSTCLR_Msk;
    HAL_IncTick();
  }

  elapsedMs = HAL_GetTick() - appLastLoopTick;
  if (elapsedMs < appLoopIntervalMs) {
    timerPeriod = (((appLoopIntervalMs - elapsedMs) * APP_SLEEP_TIMEBASE_HZ) +
                   999U) / 1000U;
    __HAL_RCC_LPTIM1_FORCE_RESET();
    __HAL_RCC_LPTIM1_RELEASE_RESET();
    LPTIM1->CFGR = 0U;
    /* IER may only be changed while the peripheral is disabled (RM0451). */
    LPTIM1->IER = LPTIM_IER_ARRMIE;
    LPTIM1->CR = LPTIM_CR_ENABLE;
    LPTIM1->ARR = timerPeriod - 1U;
    while (((LPTIM1->ISR & LPTIM_ISR_ARROK) == 0U) && (syncTimeout != 0U)) {
      --syncTimeout;
    }
    if (syncTimeout != 0U) {
      /* Count the timer's asynchronous setup time with the normal SysTick.
         Stop it only after ARR has reached the LSE clock domain. */
      SysTick->CTRL = systickControl &
                      ~(SysTick_CTRL_ENABLE_Msk | SysTick_CTRL_TICKINT_Msk);
      if ((SCB->ICSR & SCB_ICSR_PENDSTSET_Msk) != 0U) {
        SCB->ICSR = SCB_ICSR_PENDSTCLR_Msk;
        HAL_IncTick();
      }
      NVIC_ClearPendingIRQ(LPTIM1_IRQn);
      NVIC_EnableIRQ(LPTIM1_IRQn);
      SCB->SCR &= ~(SCB_SCR_SLEEPDEEP_Msk | SCB_SCR_SLEEPONEXIT_Msk |
                    SCB_SCR_SEVONPEND_Msk);
      LPTIM1->CR = LPTIM_CR_ENABLE | LPTIM_CR_SNGSTRT;
      __DSB();
      __WFI();

      /* The asynchronous counter must be read twice with matching values. */
      do {
        previousCounter = LPTIM1->CNT;
        elapsedTimerTicks = LPTIM1->CNT;
      } while (elapsedTimerTicks != previousCounter);
      if ((LPTIM1->ISR & LPTIM_ISR_ARRM) != 0U) {
        elapsedTimerTicks = timerPeriod;
      }
      elapsedUnits = sleepFraction + elapsedTimerTicks * 1000U;
      uwTick += elapsedUnits / APP_SLEEP_TIMEBASE_HZ;
      sleepFraction = elapsedUnits % APP_SLEEP_TIMEBASE_HZ;
    }
    /* Reset clears the source without an ICR write outside its IRQ handler
       (STM32L010 errata ES0483, LPTIM interrupt clearing limitation). */
    __HAL_RCC_LPTIM1_FORCE_RESET();
    __HAL_RCC_LPTIM1_RELEASE_RESET();
    NVIC_ClearPendingIRQ(LPTIM1_IRQn);
    NVIC_DisableIRQ(LPTIM1_IRQn);
    __DSB();
  }
  __HAL_RCC_LPTIM1_CLK_DISABLE();
  /* Preserve the SysTick counter phase and fractional sleep milliseconds. */
  SysTick->CTRL = systickControl;
  __enable_irq();
}

static uint8_t App_Tick(void)
{
  static uint32_t lastRtcRefreshTick = 0U;
  static uint32_t lastBlinkTick = 0U;
  static DisplayMode_t lastIdleDisplayMode = DISPLAY_TIME;
  static uint8_t oledAlarmShown = 0U;
  static uint8_t blinkOn = 1U;
  static uint8_t idlePeripheralsOff = 0U;
  static uint8_t idleAutoModeSeenMask = 0U;
  static uint8_t lowBatteryMode = 0U;
  static uint8_t alarmButtonReleasePending = 0U;
  uint32_t now = HAL_GetTick();
  ClockButton_t button = CLOCK_BUTTON_NONE;
  ClockDisplay_t display = {0U, 0U};
  DisplayMode_t displayMode = DISPLAY_TIME;
  uint16_t batteryPercentTenths = 0U;
  uint8_t alarmAnyEnabled = 0U;
  uint8_t userActivity = 0U;
  uint8_t buttonActivity = 0U;

  if ((now - appLastLoopTick) < appLoopIntervalMs) {
    return 0U;
  }
  appLastLoopTick = now;
  appLoopIntervalMs = MAIN_LOOP_DELAY_MS;

#if MAIN_POWER_STANDBY_ENABLED
  if (Board_IsWakePowerPresent() == 0U) {
    Board_EnterStandby();
    return 1U;
  }
#endif

  if ((now - lastRtcRefreshTick) >= RTC_REFRESH_INTERVAL_MS) {
    UiController_RefreshDateTime();
    lastRtcRefreshTick = now;
  }

  AlarmManager_UpdateTrigger(UiController_DateTime());

  button = Board_ReadButton();
  buttonActivity = (button != CLOCK_BUTTON_NONE) ? 1U : 0U;
  if (buttonActivity == 0U) {
    alarmButtonReleasePending = 0U;
  } else if (AlarmManager_IsBuzzerActive() != 0U) {
    AlarmManager_StopBuzzer();
    alarmButtonReleasePending = 1U;
    button = CLOCK_BUTTON_NONE;
  } else if (alarmButtonReleasePending != 0U) {
    button = CLOCK_BUTTON_NONE;
  }
  UiController_UpdateButton(button, now);

  if (Board_IsBatteryAboveLowThreshold() == 0U) {
    if (lowBatteryMode == 0U) {
      Board_PowerDownIdleDevices();
      lowBatteryMode = 1U;
      blinkOn = 0U;
      lastBlinkTick = now;
    }
    AlarmManager_UpdateBuzzer();
    if ((now - lastBlinkTick) >= LOW_BATTERY_BLINK_INTERVAL_MS) {
      blinkOn = (blinkOn == 0U) ? 1U : 0U;
      lastBlinkTick = now;
      Board_WriteDisplay(
          (ClockDisplay_t){0U, (uint8_t)(blinkOn << CLOCK_BOARD2_ALARM_BIT)});
    }
    return 1U;
  }

  if ((now - lastBlinkTick) >= BLINK_INTERVAL_MS) {
    blinkOn = (blinkOn == 0U) ? 1U : 0U;
    lastBlinkTick = now;
  }

  displayMode = UiController_DisplayMode();

  if (lowBatteryMode != 0U) {
    lowBatteryMode = 0U;
    App_SetMsiClock(APP_MSI_ACTIVE_RANGE, APP_MSI_ACTIVE_HZ);
    idlePeripheralsOff = 0U;
    idleAutoModeSeenMask = 0U;
    oledAlarmShown = 0U;
    UiController_ShowTimeMode();
    lastIdleDisplayMode = UiController_DisplayMode();
  }

  userActivity = ((HAL_GPIO_ReadPin(GPIOA, GPIO_PIN_7) == GPIO_PIN_SET) ||
                  (buttonActivity != 0U) ||
                  (UiController_EditTarget() != EDIT_NONE) ||
                  (AlarmManager_IsBuzzerActive() != 0U))
                     ? 1U
                     : 0U;

  if (userActivity != 0U) {
    idleAutoModeSeenMask = 0U;
    lastIdleDisplayMode = displayMode;
    if (idlePeripheralsOff != 0U) {
      App_SetMsiClock(APP_MSI_ACTIVE_RANGE, APP_MSI_ACTIVE_HZ);
      UiController_ShowTimeMode();
      lastIdleDisplayMode = UiController_DisplayMode();
      idlePeripheralsOff = 0U;
      oledAlarmShown = 0U;
    }
  } else if (idlePeripheralsOff != 0U) {
    appLoopIntervalMs = IDLE_LOOP_DELAY_MS;
    return 1U;
  }

  batteryPercentTenths = Board_ReadBatteryPercentTenths();
  UiController_UpdateAutoModeCycle();
  displayMode = UiController_DisplayMode();
  EnvironmentManager_Update();

  AlarmManager_UpdateBuzzer();
  alarmAnyEnabled = AlarmManager_AnyEnabled();
  Board_SetBrightness(Board_ReadBrightness());
  display = DisplayRenderer_Build(
      displayMode, UiController_EditTarget(),
      UiController_DateTime(), EnvironmentManager_Current(),
      AlarmManager_Slots(), AlarmManager_SlotCount(),
      AlarmManager_SelectedSlot(), batteryPercentTenths, alarmAnyEnabled,
      UiController_AlarmErrorActive(), blinkOn);
  Board_WriteDisplay(display);

  if (AlarmManager_IsBuzzerActive() != 0U) {
    if (oledAlarmShown == 0U) {
      Oled128x32_ShowAlarm(AlarmManager_ActiveSlot());
      oledAlarmShown = 1U;
    }
  } else {
    oledAlarmShown = 0U;
    Oled128x32_Render(now, displayMode, UiController_DateTime(),
                    EnvironmentManager_Current(), AlarmManager_Slots(),
                    AlarmManager_SlotCount(), AlarmManager_SelectedSlot(),
                    UiController_EditTarget(), batteryPercentTenths,
                    alarmAnyEnabled);
  }

  if (userActivity == 0U) {
    if (displayMode != lastIdleDisplayMode) {
      if (lastIdleDisplayMode == DISPLAY_TIME) {
        idleAutoModeSeenMask |= IDLE_AUTO_MODE_TIME_SEEN;
      } else if (lastIdleDisplayMode == DISPLAY_DATE) {
        idleAutoModeSeenMask |= IDLE_AUTO_MODE_DATE_SEEN;
      } else if (lastIdleDisplayMode == DISPLAY_ENVIRONMENT) {
        idleAutoModeSeenMask |= IDLE_AUTO_MODE_ENVIRONMENT_SEEN;
      } else {
        idleAutoModeSeenMask = 0U;
      }
      lastIdleDisplayMode = displayMode;
    }

    if ((idleAutoModeSeenMask & IDLE_AUTO_MODE_ALL_SEEN) ==
        IDLE_AUTO_MODE_ALL_SEEN) {
      Board_PowerDownIdleDevices();
      App_SetMsiClock(APP_MSI_IDLE_RANGE, APP_MSI_IDLE_HZ);
      idlePeripheralsOff = 1U;
      appLoopIntervalMs = IDLE_LOOP_DELAY_MS;
      return 1U;
    }
  }

  return 1U;
}

/* USER CODE END 4 */
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


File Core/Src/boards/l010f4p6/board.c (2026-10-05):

#include "board.h"

#include "board_config.h"
#include "oled_128x32.h"
#include "stm32l0xx_ll_adc.h"

#define ALARM_STORAGE_SIZE 16U
#define ALARM_STORAGE_BACKUP_REGISTER_COUNT 4U
#define BRIGHTNESS_MAX 100U
#define DISPLAY_TEST_BRIGHTNESS 20U
#define ADC_FULL_SCALE 4095U
#define MAIN_POWER_CONFIRM_SAMPLES 3U
#define BATTERY_MEASUREMENT_INTERVAL_MS 500U
#define MAIN_POWER_WAKEUP_LOW_WAIT_MS 25000U
#define MAIN_POWER_WAKEUP_LOW_DEBOUNCE_MS 300U
#define BATTERY_PERCENT_FILTER_SHIFT 4U
#define BATTERY_PERCENT_DISPLAY_HYSTERESIS_TENTHS 20U
#define BATTERY_PERCENT_UPDATE_INTERVAL_MS 2000U
#define BATTERY_PERCENT_UNINITIALIZED 0xFFFFU
#define AHT10_ADDRESS 0x38U
#define AHT10_MIN_READ_INTERVAL_MS 15000UL
#define AHT10_INIT_DELAY_MS 40U
#define AHT10_RESET_DELAY_MS 20U
#define AHT10_MEASURE_DELAY_MS 80U
#define AHT10_MEASURE_TIMEOUT_MS 200U
#define AHT10_STATUS_BUSY 0x80U
#define BH1750_ADDRESS 0x23U
#define BH1750_POWER_ON 0x01U
#define BH1750_RESET 0x07U
#define BH1750_CONT_HIGH_RES_MODE 0x10U
#define BH1750_READ_INTERVAL_MS 5000U
#define BOARD_I2C_DELAY_CYCLES 8U

extern RTC_HandleTypeDef hrtc;

static uint8_t currentBrightness = DISPLAY_TEST_BRIGHTNESS;
static ClockEnvironment_t lastEnvironment = {0U, 0U, 0U};
static uint32_t lastEnvironmentReadMs = 0U;
static uint8_t aht10Initialized = 0U;
static uint8_t aht10MeasurePending = 0U;
static uint32_t aht10MeasureStartMs = 0U;
static uint32_t lastBrightnessReadMs = 0U;
static uint8_t bh1750Initialized = 0U;
static uint8_t adcCalibrated = 0U;
static uint8_t batteryLow = 0U;

static void Board_PowerDownExternalDevices(uint16_t gpioAPins, uint8_t stopAdc);
static void ADC_Shutdown(void);

static volatile uint32_t *AlarmStorage_BackupRegister(uint8_t registerIndex) {
  switch (registerIndex) {
  case 0U:
    return &RTC->BKP0R;
  case 1U:
    return &RTC->BKP1R;
  case 2U:
    return &RTC->BKP2R;
  case 3U:
    return &RTC->BKP3R;
  default:
    return &RTC->BKP4R;
  }
}

static void ShiftRegister_Pulse(GPIO_TypeDef *GPIOx, uint16_t pin) {
  HAL_GPIO_WritePin(GPIOx, pin, GPIO_PIN_SET);
  HAL_GPIO_WritePin(GPIOx, pin, GPIO_PIN_RESET);
}

static void ShiftRegister_OutputEnablePwmInit(uint8_t brightness) {
  GPIO_InitTypeDef GPIO_InitStruct = {0};

  if (brightness > BRIGHTNESS_MAX) {
    brightness = BRIGHTNESS_MAX;
  }

  __HAL_RCC_TIM2_CLK_ENABLE();

  GPIO_InitStruct.Pin = SHIFT_REGISTER_OUTPUT_ENABLE_PIN;
  GPIO_InitStruct.Mode = GPIO_MODE_AF_PP;
  GPIO_InitStruct.Pull = GPIO_NOPULL;
  GPIO_InitStruct.Speed = GPIO_SPEED_FREQ_LOW;
  GPIO_InitStruct.Alternate = GPIO_AF5_TIM2;
  HAL_GPIO_Init(SHIFT_REGISTER_OUTPUT_ENABLE_GPIO, &GPIO_InitStruct);

  TIM2->CR1 = 0U;
  TIM2->PSC = 7U;
  TIM2->ARR = BRIGHTNESS_MAX - 1U;
  TIM2->CCR1 = brightness;
  TIM2->CCMR1 &= ~(0xFFUL);
  TIM2->CCMR1 |= (6UL << 4) | (1UL << 3);
  TIM2->CCER &= ~(0xFUL);
  TIM2->CCER |= TIM_CCER_CC1P | TIM_CCER_CC1E;
  TIM2->EGR = TIM_EGR_UG;
  TIM2->CR1 |= TIM_CR1_ARPE | TIM_CR1_CEN;
}

static uint32_t ADC_ChannelToSelection(uint32_t channel) {
  if (channel == ADC_CHANNEL_1) {
    return ADC_CHSELR_CHSEL1;
  }
  if (channel == ADC_CHANNEL_9) {
    return ADC_CHSELR_CHSEL9;
  }
  if (channel == ADC_CHANNEL_VREFINT) {
    return ADC_CHSELR_CHSEL17;
  }
  return ADC_CHSELR_CHSEL1;
}

static void ADC_ConfigureBase(void) {
  __HAL_RCC_ADC1_CLK_ENABLE();
  ADC1_COMMON->CCR = (ADC1_COMMON->CCR & ADC_CCR_VREFEN) | ADC_CCR_LFMEN;
  ADC1->CR |= ADC_CR_ADVREGEN;
  ADC1->CFGR1 = 0U;
  ADC1->CFGR2 = ADC_CFGR2_CKMODE;
  ADC1->SMPR = ADC_SMPR_SMPR; /* 160.5 ADC clock cycles, including VREFINT. */
}

static void ADC_Enable(void) {
  if ((ADC1->CR & ADC_CR_ADEN) == 0U) {
    ADC1->ISR = ADC_ISR_ADRDY;
    ADC1->CR |= ADC_CR_ADEN;
    while ((ADC1->ISR & ADC_ISR_ADRDY) == 0U) {
    }
  }
}

static void ADC_StopConversion(void) {
  if ((ADC1->CR & ADC_CR_ADSTART) != 0U) {
    ADC1->CR |= ADC_CR_ADSTP;
    while ((ADC1->CR & ADC_CR_ADSTART) != 0U) {
    }
  }
}

static void ADC_Disable(void) {
  ADC_StopConversion();
  if ((ADC1->CR & ADC_CR_ADEN) != 0U) {
    ADC1->CR |= ADC_CR_ADDIS;
    while ((ADC1->CR & ADC_CR_ADEN) != 0U) {
    }
  }
}

static void ADC_Calibrate(void) {
  ADC_ConfigureBase();
  ADC_Disable();
  ADC1->CFGR1 &= ~(ADC_CFGR1_DMAEN | ADC_CFGR1_DMACFG);
  ADC1->CR |= ADC_CR_ADCAL;
  while ((ADC1->CR & ADC_CR_ADCAL) != 0U) {
  }
  adcCalibrated = 1U;
  ADC_Enable();
}

static void ADC_Shutdown(void) {
  ADC_Disable();
  ADC1_COMMON->CCR &= ~ADC_CCR_VREFEN;
  ADC1->CR &= ~ADC_CR_ADVREGEN;
  adcCalibrated = 0U;
  __HAL_RCC_ADC1_CLK_DISABLE();
}
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

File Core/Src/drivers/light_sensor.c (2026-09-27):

#include "light_sensor.h"

#include "board_config.h"
#include "buttons_decoder.h"

void LightSensor_Init(void) {
  ButtonsDecoder_Init();
}

uint16_t LightSensor_ReadRaw(void) {
  return ADC1_ReadChannel(LIGHT_SENSOR_ADC_CHANNEL);
}

uint8_t LightSensor_ReadBrightness(void) {
  static uint8_t currentLevel = 0U;
  uint16_t adcValue = LightSensor_ReadRaw();
  uint32_t adcRange = LIGHT_SENSOR_ADC_BRIGHT - LIGHT_SENSOR_ADC_DARK;
  uint8_t maxLevel = LIGHT_SENSOR_BRIGHTNESS_LEVELS - 1U;
  uint8_t nextLevel = currentLevel;

  if (adcValue <= LIGHT_SENSOR_ADC_DARK) {
    nextLevel = 0U;
  } else if (adcValue >= LIGHT_SENSOR_ADC_BRIGHT) {
    nextLevel = maxLevel;
  } else {
    uint32_t adcOffset = adcValue - LIGHT_SENSOR_ADC_DARK;
    nextLevel =
        (uint8_t)((adcOffset * maxLevel + (adcRange / 2U)) / adcRange);
  }

  if (nextLevel > currentLevel) {
    uint32_t upThreshold =
        LIGHT_SENSOR_ADC_DARK + ((uint32_t)(currentLevel + 1U) * adcRange) / maxLevel;
    if (adcValue >= (upThreshold + LIGHT_SENSOR_ADC_HYSTERESIS)) {
      currentLevel = nextLevel;
    }
  } else if (nextLevel < currentLevel) {
    uint32_t downThreshold =
        LIGHT_SENSOR_ADC_DARK + ((uint32_t)currentLevel * adcRange) / maxLevel;
    if ((adcValue + LIGHT_SENSOR_ADC_HYSTERESIS) <= downThreshold) {
      currentLevel = nextLevel;
    }
  }

  uint32_t brightnessRange =
      LIGHT_SENSOR_BRIGHTNESS_MAX - LIGHT_SENSOR_BRIGHTNESS_MIN;

  return (uint8_t)(LIGHT_SENSOR_BRIGHTNESS_MIN +
                   (((uint32_t)currentLevel * brightnessRange) / maxLevel));
}

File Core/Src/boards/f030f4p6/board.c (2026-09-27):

#include "board.h"

#include "board_config.h"

extern ADC_HandleTypeDef hadc;

volatile uint16_t buttonsAdcRaw = 0U;
volatile ClockButton_t buttonsDecoded = CLOCK_BUTTON_NONE;
volatile uint16_t lightSensorAdcRaw = 0U;

#define DS1302_SECONDS_READ 0x81U
#define DS1302_SECONDS_WRITE 0x80U
#define DS1302_MINUTES_READ 0x83U
#define DS1302_MINUTES_WRITE 0x82U
#define DS1302_HOURS_READ 0x85U
#define DS1302_HOURS_WRITE 0x84U
#define DS1302_DATE_READ 0x87U
#define DS1302_DATE_WRITE 0x86U
#define DS1302_MONTH_READ 0x89U
#define DS1302_MONTH_WRITE 0x88U
#define DS1302_CONTROL_WRITE 0x8EU
#define DS1302_RAM_WRITE_BASE 0xC0U
#define DS1302_RAM_READ_BASE 0xC1U
#define DS1302_RAM_SIZE 31U

#define DHT11_TIMEOUT 0xFFFFFFFFUL
#define DHT11_MIN_READ_INTERVAL_MS 2000UL
#define DHT11_START_LOW_MS 25U
#define DHT11_START_RELEASE_US 30U
#define DHT11_RESPONSE_TIMEOUT_US 120U
#define DHT11_BIT_TIMEOUT_US 100U
#define DHT11_ONE_THRESHOLD_US 45U

#define PWM_MAX_DUTY 100U

static ClockEnvironment_t lastEnvironment = {0U, 0U, 0U};
static uint32_t lastEnvironmentReadMs = 0U;

static void Board_DelayCycles(volatile uint32_t cycles) {
  while (cycles > 0U) {
    --cycles;
  }
}

static void Board_DelayUs(uint32_t microseconds) {
  uint32_t cyclesPerUs = SystemCoreClock / 1000000UL;
  uint32_t waitTicks = microseconds * cyclesPerUs;
  uint32_t reload = SysTick->LOAD;
  uint32_t start = SysTick->VAL;
  uint32_t elapsed = 0U;

  if ((cyclesPerUs == 0U) || ((SysTick->CTRL & SysTick_CTRL_ENABLE_Msk) == 0U)) {
    while (microseconds > 0U) {
      Board_DelayCycles(8U);
      --microseconds;
    }
    return;
  }

  while (elapsed < waitTicks) {
    uint32_t current = SysTick->VAL;

    if (start >= current) {
      elapsed = start - current;
    } else {
      elapsed = start + (reload - current) + 1U;
    }
  }
}

static void ShiftRegister_Pulse(GPIO_TypeDef *GPIOx, uint16_t pin) {
  HAL_GPIO_WritePin(GPIOx, pin, GPIO_PIN_SET);
  HAL_GPIO_WritePin(GPIOx, pin, GPIO_PIN_RESET);
}

static void ShiftRegister_OutputEnablePwmInit(uint8_t brightness) {
  GPIO_InitTypeDef GPIO_InitStruct = {0};

  if (brightness > PWM_MAX_DUTY) {
    brightness = PWM_MAX_DUTY;
  }

  __HAL_RCC_TIM3_CLK_ENABLE();

  GPIO_InitStruct.Pin = SHIFT_REGISTER_OUTPUT_ENABLE_PIN;
  GPIO_InitStruct.Mode = GPIO_MODE_AF_PP;
  GPIO_InitStruct.Pull = GPIO_NOPULL;
  GPIO_InitStruct.Speed = GPIO_SPEED_FREQ_LOW;
  GPIO_InitStruct.Alternate = GPIO_AF1_TIM3;
  HAL_GPIO_Init(SHIFT_REGISTER_OUTPUT_ENABLE_GPIO, &GPIO_InitStruct);

  TIM3->CR1 = 0U;
  TIM3->PSC = 7U;
  TIM3->ARR = PWM_MAX_DUTY - 1U;
  TIM3->CCR1 = brightness;
  TIM3->CCMR1 &= ~(0xFFUL);
  TIM3->CCMR1 |= (6UL << 4) | (1UL << 3);
  TIM3->CCER &= ~(0xFUL);
  TIM3->CCER |= (1UL << 1) | (1UL << 0);
  TIM3->EGR = TIM_EGR_UG;
  TIM3->CR1 |= TIM_CR1_ARPE | TIM_CR1_CEN;
}

static uint8_t BcdToDecimal(uint8_t bcdValue) {
  return (uint8_t)(((bcdValue >> 4U) * 10U) + (bcdValue & 0x0FU));
}

static uint8_t DecimalToBcd(uint8_t decimalValue) {
  return (uint8_t)(((decimalValue / 10U) << 4U) | (decimalValue % 10U));
}

static uint16_t ADC_ReadChannel(uint32_t channel) {
  ADC_ChannelConfTypeDef sConfig = {0};
  uint16_t value = 0x0FFFU;

  HAL_ADC_Stop(&hadc);
  ADC1->CHSELR = 0U;

  sConfig.Channel = channel;
  sConfig.Rank = ADC_RANK_CHANNEL_NUMBER;
  sConfig.SamplingTime = ADC_SAMPLETIME_239CYCLES_5;
  if (HAL_ADC_ConfigChannel(&hadc, &sConfig) != HAL_OK) {
    return value;
  }

  for (uint8_t sample = 0U; sample < 2U; ++sample) {
    if (HAL_ADC_Start(&hadc) != HAL_OK) {
      break;
    }
    if (HAL_ADC_PollForConversion(&hadc, 5U) == HAL_OK) {
      value = (uint16_t)(HAL_ADC_GetValue(&hadc) & 0x0FFFU);
    }
    HAL_ADC_Stop(&hadc);
  }
  return value;
}

static ClockButton_t DecodeButton(uint16_t adcValue) {
  if (adcValue <= BUTTON_MODE_ADC_MAX) {
    return CLOCK_BUTTON_MODE;
  }
  if (adcValue <= BUTTON_SET_ADC_MAX) {
    return CLOCK_BUTTON_SET;
  }
  if (adcValue <= BUTTON_UP_ADC_MAX) {
    return CLOCK_BUTTON_UP;
  }
  if (adcValue <= BUTTON_DOWN_ADC_MAX) {
    return CLOCK_BUTTON_DOWN;
  }
  if (adcValue <= BUTTON_OFF_ADC_MAX) {
    return CLOCK_BUTTON_OFF;
  }
  return CLOCK_BUTTON_NONE;
}

static void DHT11_PinInput(void) {
  GPIO_InitTypeDef GPIO_InitStruct = {0};

  GPIO_InitStruct.Pin = DHT11_DATA_PIN;
  GPIO_InitStruct.Mode = GPIO_MODE_INPUT;
  GPIO_InitStruct.Pull = GPIO_NOPULL;
  HAL_GPIO_Init(DHT11_DATA_GPIO, &GPIO_InitStruct);
}

static void DHT11_PinOutput(void) {
  GPIO_InitTypeDef GPIO_InitStruct = {0};

  GPIO_InitStruct.Pin = DHT11_DATA_PIN;
  GPIO_InitStruct.Mode = GPIO_MODE_OUTPUT_OD;
  GPIO_InitStruct.Pull = GPIO_NOPULL;
  GPIO_InitStruct.Speed = GPIO_SPEED_FREQ_LOW;
  HAL_GPIO_Init(DHT11_DATA_GPIO, &GPIO_InitStruct);
}

static GPIO_PinState DHT11_ReadPinFast(void) {
  return ((DHT11_DATA_GPIO->IDR & DHT11_DATA_PIN) != 0U) ? GPIO_PIN_SET
                                                          : GPIO_PIN_RESET;
}
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

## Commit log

2026-06-23 Phase 1 STM32F407 binary clock prototype
2026-06-24 Refactor hardware into board packages and drivers
2026-07-06 F030f4p6 code base for hall
    [Clock_F030F4P6.cfg]
2026-07-06 Make STM32CubeIDE paths workspace-relative
2026-07-16 Add STM32L010F4P6 board support
    Replace the F030 CubeMX/HAL target with the L010F4P6 project files, startup, linker script, and OpenOCD/CubeIDE launch config. Add the L010 board implementation with RTC-on-LSE display output, PA0 wakeup standby flow, PB1 power sense, PA6 light ADC reservation, and PA1 button ladder support.
    [Clock_F030F4P6.cfg, l010f4p6.cfg]
2026-07-16 Document L010F4P6 board wiring and standby flow
2026-07-16 Add persistent alarms and buzzer support
    [app_config.h, board.c, board_config.h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]
2026-07-28 Add I2C OLED and AHT10 bring-up
2026-07-28 Restore buttons and avoid blocking environment reads
    [board.c, main.c]
2026-07-28 Improve OLED alarm UI and button timing
2026-07-28 Improve button responsiveness with OLED updates
2026-07-28 Add buzzer output and OLED alarm cues
    [board.c, board_config.h, main.c]
2026-07-29 Tune standby power sense handling
2026-08-03 Enable I2C sensors and OLED recovery
2026-08-03 Add delayed standby power-down
2026-08-03 Add battery display mode
2026-08-03 Stabilize battery ADC display
    [board.c, board_config.h, main.c]
2026-08-05 Refine 595 edit indicators and battery handling
2026-08-05 Wait for full auto display cycle before idle powerdown
2026-08-05 Optimize OLED updates and sensor polling
2026-08-18 Document button resistor ladder
2026-08-18 Fix idle UI scheduling
    [app_config.h, main.c]
2026-08-18 Keep alarm active on low battery
2026-09-27 Add Clock Plus documentation and KiCad sources
    [Clock i2c l0.kicad_pcb, Clock i2c l0.kicad_sch]
2026-09-27 Add clock enclosure FreeCAD model
    [CASE-v0_1.1.FCStd]
2026-09-28 Update KiCad schematic layout
    [Clock i2c l0.kicad_sch]
2026-09-28 Restore finalized KiCad PCB routing
    [Clock i2c l0.kicad_pcb]
2026-10-05 Add timed sleep and stabilize ADC and AHT10 readings
    [board.c, main.c]
2026-10-05 Correct battery divider scaling and document measurement loading
    [board_config.h]

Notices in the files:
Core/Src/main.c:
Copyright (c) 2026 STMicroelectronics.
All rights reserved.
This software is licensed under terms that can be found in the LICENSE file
